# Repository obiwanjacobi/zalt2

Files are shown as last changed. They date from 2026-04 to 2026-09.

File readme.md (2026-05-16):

# Zalt II

The design of the Zalt II computer hinges on a 10-slot (PC) ISA powered backplane I had laying around.

So all modules have an ISA edge connector and although the physical construction is the same as the (PC) ISA bus, the electrical connections are different. So don't try plugging the modules into an old PC.

All card modules (except the Main Board) represent a "smart device".
A smart device has it's own processor to give it additional functionality and perform DMA to offload the CPU.

## Main Board v2.0 (manufactured)

The "motherboard" of the Zalt II computer, containing the 20MHz Z80 CPU, a CPLD for condensed system logic (like MMU/MPU) and an MCU for some (serial) peripherals.

---

## Mass Storage Card

> TBD

- Support IDE hard disks / Compact Flash
- Support File System (FAT16/32)
- Efficient file data transfer (DMA and prefetch)

---

## Video Display Card

> TBD

Currently being researched.

We start of with a simple test on an (SSD1963) [LCD display](./Lcd%20display.md) I have.

- command-based interaction
- lots of graphic services (layers, sprites, transformations, animation, scrolling)
- Additional memory for storing graphic assets
- maybe even a built-in windowing system
- VGA and HDMI using a CPLD to do the heavy lifting
- MCU (STM32?) for 'accelerion', additional memory and DMA

---

## Audio Interface Card

> TBD

Fague ideas on what to do here.

- use MIDI (files) to drive the sound generator(s).
- use a teensy and the audio library (design) capabilities as the processor / sound generator.
- Allow samples to be uploaded and played.
- Prepare for recording audio samples (don't make it impossable), but no plans to use it.

---

## Network Card

> TBD

No idea yet how to do this, but seems like a good idea.

- LAN + WIFI (+BLE?)
- W5500 LAN module (AliExpress)

---

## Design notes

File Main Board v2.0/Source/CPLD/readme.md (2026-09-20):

# CPLD Xilinx XC95288XL

Toolchain: Xilinx ISE WebPack (14.7)

## Memory Decoder

Decode address for:

- ROM Enable
- RAM Enable

## Memory Protection Unit (MPU)

> triggers NMI for violation

- M1 & MEMRQ + RD => MP_EXE (implies MP_RD)
- MEMRQ + RD => MP_RD
- MEMRQ + WR => MP_WR

> MP_RD is a bit redundant. Read access can be assumed as default (and non-destructive). MP_EXE implies read access (M1 is only active at the start of an instruction, which can have additional read cycles). MP_RD could perhaps be renamed/reused for an OS-flag, marking a memory page as locked to applications. See Repurpose MP_RD chat.

Copy on write: mark a memory page as non-writable and keep separate flags in os-memory.
When the NMI triggers, lookup the additional flags and allocate an empty memory page.
Temporary put the two pages in the same memory bank and copy over the content.
Restore the original bank with the new mem-page copy instead of the old one.

Debug Breakpoint: add an address register to the CPLD and when the CPLD detects an execution (M1) at that address, it raises the NMI. The NMI-handler can then enters the debugger using the debug-console. That would mean a loooong interrupt.

Detect `HALT` stalls: when DI and HALT both active, the code will never run. Could count Refresh to detect HALT being active for too long.

> NMI: multiple uses arrise.

- NMI triggers on an actual violation. The program should be killed. Adjust the return address on the stack to handle what to do after that.
- NMI triggers but some function has to be performed and after that execution can continue.

### External DMA

There is a potential issue with external DMA of a smart device.

When a smart device takes over the CPU bus, the smart device has control of the (CPU) memory. The MMU (and MPU) are never turned off.
So the current memory bank the application was using last when making the call to initiate the DMA transfer, is still active.

To fix this we reserve (8) memory banks for the 8 smart devices (also 8 interrupts on the bus) and auto-select the memory bank for that specific smart device.
How does the CPLD know what smart-device is (going to be) active? The bus-req is coupled to the bus interupt index, it is basically a special interrupt.

The smart-device 'index' is used to activate that specific MMU-bank in a reserved/OS-dedicated MMU-map.
This has to be done by the CPLD when the bus is requested.
Select the MMU-map and the device-bank.
That way each device has their 'shared' memory mapped in a location suitable for that device. Other page-indexes can be mapped to a null-page to make them unusable.
The OS MMU-map (Task 0) will reserve the last 8 memory banks for the 8 smart-devices that the CPLD will use.

Access to the MMU-IO registers (to change MMU configuration) is already blocked if not in supervisor mode - so a smart-device can not reconfigure the MMU to gain access to other memory.

## Memory Management Unit  (MMU)

> Physical Memory is the total memory attached to the hardware.
> Logical Memory is the memory addressed by the Z80 CPU (64k).

Normal Operation:

- Latch (6bit) for MMU-Bank
- Latch (6bit) for Task-Bank-maps
- Enable MMU RAM1 + RAM2

IO Operation (RD/WR):

- Decode IO address for writing MMU SRAMs.
- Latch (6bit) for IO-MMU-Bank
- Latch (6bit) for IO-Task-Bank-maps
- Enable MMU RAM1 + RAM2
- WR-Enable MMU RAM1 + RAM2
- Data Direction (RD/WR) for buffers (MMU_RAM_DDIR)
- Data Enable for RAM1 or RAM2

Startup sequence:

At startup/powerup the MMU SRAMs are unitialized (assume garbage).
The CPLD will not enable the SRAMs initially until a specific (IO) write is performed from the Z80 code, indicating initialization of the SRAMs is complete.

When the SRAMs are disabled, the state of the MA13-MA25 lines is determined by weak pull-up/down resistors that map the bootstrap ROM code (4k) into address space $0000 of the Z80.

When the Z80 ROM initialization code is writing values to the MMU SRAMs, they are enabled to receive the write (of course). When the write is done, the state of the SRAM CE line is set to the value of the initialization FlipFlop.

The initialization FlipFlop can be set/reset targeting an output to a specific IO address.

IO Addresses:

- Total of 6 IO addresses requires 3 bits
- Reuse high address bits: `$aaaX_1111_1111_1111`
- A13-A15 select the MMU page address (X=0)
- lower IO address nibbles are `$F` to differentiate from normal IO.

Individual IO ports:

- Startup Latch/MMU Enable (1-bit) `$1FFF`
- Current bank latch (6-bits) `$3FFF`
- Current task latch (6-bits) `$5FFF`

- Change bank latch (6-bits) `$7FFF`
- Change task latch (6-bits) `$9FFF`
- RD/WR memory page in latched bank `$0FFF`-`$EFFF` (uses A13-A15)

## Interrupt Controller

handles Interrupt priority and promotes to INT

In order of prio:

- System IO Interrupts
  - System Timer
  - Programmable Timer(s)
  - PS2 Keyboard
  - Console 1
  - Console 2
- System IO Interrupt Acknowledge

- Expansion Bus Interrupts
  - Interrupt request 1
  - Interrupt request 2
  - Interrupt request 3
  - Interrupt request 4
  - Interrupt request 5
  - Interrupt request 6
- Expansion Bus Interrupt Acknowledge

- Interrupt Enable
  - Scan for RETI instruction after interrupt was issued.

## System IO

- System IO - Data RD/WR and Status RD/Command WR
  - CMD bit
  - Data Direction (245)
  - Data Enabled (CE) (last to activate)
  - Cyclc-count clock (20MHz) to generate CPU wait-states (MCU is slower).

See also Interrupt Controller for System IO interrupts.

## Expansion Bus

- MEM-RD (MEMRQ+RD)
- MEM-WR (MEMRQ+WR)
- IO-IN (IOREQ+RD)
- IO-WR (IOREQ+WR)

- 20MHz clock on dedicated pin.
  - Output 10MHz (bus) clock

---

## TODO

- [ ] detect RETI - to know when interrupt/and RST returns. Assume DI for RSTs also.
  - [ ] Enable `BINTEN` when RETI returns (from an interrupt).
- [ ] detect all RST variants (11xxx111).
- [x] detect INT by CPU int-ack (IORQ+M1)
- [ ] add supervisor FF. Set on RST or INT and cleared on RETI. Track nesting of INT in RST - requires 2x RETI. Can check MMU_MP_OS bit for transition from user to supervisor mode.
- [ ] when coming out of reset the supervisor bit must be on
- [ ] prohibit MMU IO when supervisor is not set.
- [ ] MMU_MP_OS bit (instead of MMU_MP_RD) that is set for os data and code. Fault if MMU_MP_OS is set and supervisor FF is not on during a read or write.
- [ ] Perform no other checks when MMU_MP_OS bit is on. The os mixes code and data in memory pages.

- [x] detect a bus-req interrupt from a smart device.
  - [ ] auto-select the OS-task (0) MMU-map.
  - [ ] select the memory bank for the device requesting the interrupt.

- [ ] BINTACK is not really used. Each BIRQn has its own ACK.
- [x] MMU-enable needs to be active when data is being written or read using IO - even when the FF is off.
- [x] When MMU-enable is false (disabled) the protection bits (MMU_MP_XX) are ignored.
- [x] Writes to the normal MMU latch must be atomic to change all 11 bits at the same time.

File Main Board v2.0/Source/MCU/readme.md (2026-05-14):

# MCU ATmega1284 Source Code

Toolchains: platform IO + VScode

Contains the source code for the System IO processor.

- USART (console) (2x)
- PS/2 Keyboard
- System Tick Timer
- Realtime Clock (RTC) timer
- Programmable Timer(s)
- Persistent Settings (EEPROM)
- SD-Card (SPI)

After a Command has been issued the relevant state-machine is activated.
Any state-machine that was active (but not finished?) is aborted/terminated.

## Status and Commands

| Bit | Status | Function | Description |
| -- | -- | -- | -- |
| 0 | Error | File | There is an error in the last file operation (per file handle) |
| 1 | Error | Console 1 | There was an error. |
| 2 | Output Empty | Console 1 | There is room to send another byte. |
| 3 | Input Full | Console 1 | The receieved byte can be retrieved. |
| 4 | Error | Console 2 | There was an error. |
| 5 | Output Empty | Console 2 | There is room to send another byte. |
| 6 | Input Full | Console 2 | The receieved byte can be retrieved. |
| 7 | Busy | System IO | System IO is doing work. |

| Byte | Command | Function | Description |
| -- | -- | -- | -- |
| 0000_0000 | - | - | - |
| 0000_1000 | FILE-OPEN-READ | File | |
| 0000_1001 | FILE-OPEN-WRITE | File | |
| 0000_1010 | FILE-READ | File | |
| 0000_1011 | FILE-WRITE | File | |
| 0000_1100 | FILE-CLOSE | File | |
| 0000_1101 | FILE-ERROR | File | |
| 0000_0001 | RTC-DATE | Realtime Clock | |
| 0000_0010 | RTC-TIME | Realtime Clock | |
| 0000_0100 | SETTING-READ | Configuration Settings | |
| 0000_0101 | SETTING-WRITE | Configuration Settings | |
| 0000_0110 | SETTING-ERROR | Configuration Settings | |
| 0001_000n | CONSOLE-READ-n | Console | |
| 0001_001n | CONSOLE-WRITE-n | Console | |
| 0001_010n | CONSOLE-ERROR-n | Console | |
| 0001_1000 | KEYBOARD-READ | Keyboard | |
| 0001_1001 | KEYBOARD-WRITE | Keyboard | |
| 0010_00nn | TIMER-SET-n | Programmable Timer-n | |

## Interrupt Levels

Interrupts issued to the CPU:

| Level | Interrupt |
| -- | -- |
| 1 | System Tick Timer |
| 2 | Keyboard |
| 3 | Console 0 |
| 4 | Programmable Timer 0 |
| 5 | Console 1 |
| 6 | Programmable Timer 1 |
| 7 | Protocol Signal* |

> *) If a Procotol Signal is not needed, the interrupt will be assigned to Programmable Timer 2, which currently has no interrupt (polling-based).

Interrupts handled by the MCU (internally):

| Level | Interrupt |
| -- | -- |
| 0 | Hardware Reset |
| 1 | Protocol Data Exchange |
| 2 | Keyboard (pint) |
| 3 | Realtime Clock |
| 4 | System Tick Timer |
| 5 | Programmable Timer 0 |
| 6 | Programmable Timer 1 |
| 7 | SPI / SD-card |
| 8 | Console 0 |
| 9 | Configuration Setting Ready |
| 10 | Console 1 |
| 11 | Programmable Timer 2 |

The interrupt levels for handling internal interrupts in the MCU are fixed by the MCU.

## System Tick Timer

Fixed interval timer tick interrupts for the os to act upon.

- INT: every tick (100ms?)

> Implemented using Timer0 (interrupt) of the MCU.

## Realtime Clock

- CMD: RTC-DATE
  - RD: year (?)
  - RD: month (1-12)
  - RD: day (1-31)

- CMD: RTC-TIME
  - RD: hour (0-23)
  - RD: minute (0-59)
  - RD: second (0-59)

> Implemented using Timer2 (and the external 32.768kHz crystal) of the MCU.

## Configuration Settings

- CMD: SETTING-8
  - WR: address (0-255)
    - RD: value (slow)
    - WR: value (0-255)

- CMD: SETTING-16
  - WR: address (0-255)
    - RD: value LSB (slow)
    - RD: value MSB (slow)
    - WR: value LSB (0-255)
    - WR: value MSB (0-255)

> Implemented using the on-board EEPROM of the MCU.

## Console

- CMD: CONSOLE-n (n:0-1)
  - WR: value (0-255) - output
  - (or) RD: value (0-255) - input, response to INT
- STAT: OutputBufferEmpty, InputBufferFull
- INT: receive input

- CMD: CONSOLE-n-ERROR (n:0-1)
  - RD: error value

> Implemented off the USART0/1 (interrupts) of the MCU.

## PS2 Keyboard

- CMD: KEYBOARD (key-table values)
  - RD: LSB
  - RD: MSB
  - WR: LEDs
- INT: receive input

> Implemented off the Pin Interrupt of the MCU.

## Programmable Timers

- CMD: TIMER-n (n:0-1)
  - WR: interval (0=off)
- INT every tick (different prios)

> Implemented using Timer1 and Timer 3 (interrupts) of the MCU.

## SD-Card Files

- CMD: FILE-OPEN | mode (bit0: 0-read/1=write)
  - WR: file name (one char at a time) + terminating /0.
  - RD: file handle (CPU will wait till MCU is ready) (negative are error values)

- CMD: FILE-READ
  - WR: file-handle
  - INT: file block ready
  - RD: read file handle
  - RD: block length (0=EOF)
  - RD: block data per byte (till block length)

- CMD: FILE-WRITE
  - WR: file handle
  - WR: block length
  - WR: block data per byte (till block length)

- CMD: FILE-CLOSE
  - WR: file handle

- CMD: FILE-ERROR
  - WR: file handle
  - RD: error value

> Implemented using the SPI serial interface (interrupt) of the MCU.

## Data Exchange

The Read and Write data exchange (either data or command/status) have to be handled by the MCU.

The CPLD prepares the Data-Direction signal and the Command/Status bit before activating the Data-Enable signal (active low).

The Data-Enable signal will interrupt the MCU to allow it to read or write the data to/from the CPU data bus.

If the Command/Status bit is active, the MCU will either return the status byte -readilly available in memory- or store the requested command in memory and initialize the corresponding state-machine - clearing out any state that might be left there.

> State-machines that have not finished their state transitions -and required more IO with the CPU- will be aborted. If a state-machine just needs to finish it's background tasks, it is kept alive an gets a slice of the main loop (cooperative).

After the state-machine is initialized, the interrupt service handler is exited.

The main loop will perform the actions advance the state-machine.
The state-machine might signal an interrupt to the CPU (handled by the CPLD) as one of it's steps.

When a Data-Read is received  (another interrupt) the active state-machine is requested to yield a value.
If this value is not available yet (because the CPU is too fast) a pending or error condition has to be generated.

> Currently there is no way to distinguish a read data value from an error value:

- After a read, the corresponding error status or busy flag could be checked. This would double the data transfer.
- The CMD-protocol should be designed such, that there is room in the data-space returned from reads, to indicate errors (pending).

The state-machine can buffer data that will be read by multiple data-read operations.
If there a lot of time between isueing the command and being able to execute the first read, an interrupt should be used to signal completion of an asynchronous operation (the state-machine performed).
We have 7 interrupts in total.
Related signals could share interrupts and the client code on the CPU has to poll to know what operation completed.

Interrupt handling must be a short as possible in order not to frustrate other interrupts (data-exchange iterrupt is highest prio).
Especialy the system-tick timer has highest prio in order to have a stable tick pulse.

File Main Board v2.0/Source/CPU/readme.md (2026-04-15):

# Z80 CPU Source Code

Toolchain: z88dk

## BIOS

Basic Input/Output System - contains hardware abstraction.

- Memory Management Unit - functions for all aspects of the MMU.
- Console IO - routines for serial communication
- Keyboard - low level keyboard scan routine and turning leds on.
- Persistent settings management.
- Realtime Clock functions (Date and Time)
- Storage interaction (TBD)
- programmable timers

## OS

API / services for applications to run on the Zalt2 computer.

- System Init: memory scan/test
- Program loader (applications, modules)
- Process managment (no threads, only process/task=program)
- Memory protection routines (MMU/NMI)
- Interrupt handling / vector management
- Asynchronous communication
- Device Physical/Logical (linux like)
- Streaming API (async) Data/Meta

Program Loader:

- Relocatable code?
- Segmented application format (S-records?) (data section, code section, etc)

## Shell

- command line interface
- built-in commands (monitor like)
  - system utils
    - memory: read/write/fill/test
    - memory manager:control MMU
    - keyboard test
    - inspect settings
  - debug: setup debug console
  - expansion bus
    - address cards (TBD)
- start programs (dos like)

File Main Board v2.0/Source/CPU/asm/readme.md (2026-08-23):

# BIOS

Basic IO System

Contains routines to initialize and access the primary IO devices.

## Conventions

### Registers

`BC`, `DE`, `HL` and `AF` are used as OS-arguments and return values, filled and received by the calling application. Assume (as caller) these registers are not preserved when the call returns (except return values of course).

`BC'`, `DE'`, `HL'` and `AF'` are used by OS and are not preserved.

`IX` and `IY` are not used by the OS at all and are reserved for C-lang application code.

## Page 0

Page zero is the first 4k memory page that will live in all banks (except device specific banks). The page0 contains the necessary data and routines for the OS to operate and interact with (as an application).

- RST entry points: all RST instructions are used for application code to enter the OS.
- IM2 vector table. All the interrupt vectors that are used by the CPLD (BusIO and SystemIO) are located in the first bytes.
- MMU routines: functions to reconfigure and switch memory banks.
- NMI handler: handles memory protection faults.
- Task scheduler: schedules tasks on the system-tick interrupt.
- OS Task: the anchor for switching to and from the OS task (memory bank).

> Note that the IM2 vector table is laid out in the same addresses as the RST and NMI handlers, invalidating some of the vectors.

IM2 vector table at `$0000` (I register = `$00`), even vectors only, sharing addresses with RST and NMI handlers.

| Address | Bytes | Content | Even IM2 Data Bus Values |
|:---:|:-----:|---|:---:|
| $0000–$0003 | 4 | **RST $00** — `JP nnnn` + align | ⛔ $00, $02 |
| $0004–$0007 | 4 | IM2 vector data | ✅ $04, $06 |
| $0008–$000B | 4 | **RST $08** — `JP nnnn` + align | ⛔ $08, $0A |
| $000C–$000F | 4 | IM2 vector data | ✅ $0C, $0E |
| $0010–$0013 | 4 | **RST $10** — `JP nnnn` + align | ⛔ $10, $12 |
| $0014–$0017 | 4 | IM2 vector data | ✅ $14, $16 |
| $0018–$001B | 4 | **RST $18** — `JP nnnn` + align | ⛔ $18, $1A |
| $001C–$001F | 4 | IM2 vector data | ✅ $1C, $1E |
| $0020–$0023 | 4 | **RST $20** — `JP nnnn` + align | ⛔ $20, $22 |
| $0024–$0027 | 4 | IM2 vector data | ✅ $24, $26 |
| $0028–$002B | 4 | **RST $28** — `JP nnnn` + align | ⛔ $28, $2A |
| $002C–$002F | 4 | IM2 vector data | ✅ $2C, $2E |
| $0030–$0033 | 4 | **RST $30** — `JP nnnn` + align | ⛔ $30, $32 |
| $0034–$0037 | 4 | IM2 vector data | ✅ $34, $36 |
| $0038–$003B | 4 | **RST $38** — `JP nnnn` + align | ⛔ $38, $3A |
| $003C–$003F | 4 | IM2 vector data | ✅ $3C, $3E |
| $0040–$004D | 14 | SYSINT 1–7 — IM2 vectors | ✅ $40, $42, $44, $46, $48, $4A, $4C |
| $004E–$005D | 16 | BIRQ0–7 — IM2 vectors | ✅ $4E, $50, $52, $54, $56, $58, $5A, $5C |
| $005E–$0065 | 8 | Free — IM2 vector data | ✅ $5E–$64 (4 vectors) |
| $0066–$0069 | 4 | **NMI** — `JP nnnn` + align | ⛔ $66, $68 |
| $006A–$00FF | 150 | ⚠️ NOT INITIALIZED | ⛔ $6A–$FE (75 vectors) |

The `RST` instructions define the ABI of the OS and device drivers.
A function id follows the RST instruction indicating what to perform.
Any parameters are either passed in registers or put in a dedicated memory block.

| RST | Role | Notes |
| -- | -- | -- |
| $00 | Boot / warm reset | Cannot use it for anything else |
| $08 | OS kernel | Memory, MMU, alloc, tasks, console I/O, everything OS |
| $10 | Storage / file system | High-level functions |
| $18 | Video / graphics | High-level functions |
| $20 | Reserved | audio |
| $28 | Reserved | network / future |
| $30 | Reserved | debug / trap hook or future |
| $38 | Stray trap | All memory is filled with $FF (RST38) |

## OS Initialization

Initialize Memory:

- copy page0 from ROM (currenly executing) to RAM and put that memory page on index 0 (this tranfers execution instantly).
- layout the other OS-pages (code from ROM) in the MMU (64k max)
- initialize OS data-page (RAM) and init stack (OS-specific)

## Memory Management

- MMU operations: map page into address space / change bank configuration
- Allocating a memory page per task.
- Provide Allocators on claimed memory pages (per task).

## Debugging

There are several options for debugging in place.

| Mechanism | How triggered | Use case |
| -- | -- | -- |
| RST $30 | Developer patches a byte | Intentional breakpoint |
| CPLD breakpoint register | M1 at watched address → NMI | Non-invasive / ROM breakpoint |
| HALT → NMI | Any HALT opcode → CPLD → NMI | Crash / unhandled fault trap |

RST $30 is a single byte (0xF7), so it can replace any opcode byte in-place. The handler:

- Saves the full register set into a fixed debug save-area in page 0
- The saved PC (from the stack) points past RST $30 — subtract 1 to get the actual breakpoint address
- Enters a debug monitor loop on the debug console (you already have SYSINT5 / console 1 for this)
- Can inspect/modify the save-area (= registers), read/write any memory
Single-step: temporarily write RST $30 at the next PC, patch the original opcode back, RETI

CPLD Breakpoint register:

- Breakpoints in read-only memory (device ROM, BIOS)
- No need to modify running code
- One NMI handler checks a flag to distinguish "memory protection fault" (existing) from "hardware breakpoint hit"

## Task Switching

For handling interrupts and performing os-functions (RSTs) a light form of task-switching is required. The idea is that upon entering an ISR or RST, the OS switches to it's own private Task memory layout, including it's own stack.

If not already in OS-task:

- stash current (app) SP
- stash current MMU active Task/Bank
- switch to OS-task

For RSTs this requires bringing over the parameters (registers) that acompanied the RST call, which may introduce some additional complexity. If the OS-Task is already active, nothing happens and it is not switched back (to what?) after the ISR or RST is finished.

Just before the INT or RST returns (from page0):

- activate stashed Task/Bank
- reinstate the SP (clear var to indicate no task/bank to switch back to)

### RST - OS function

```z80asm
; os_page0.asm
    di
    jp os_rst_n

; os_rst_n - os_rst.asm
    exx
    ; TODO=> save registers BC' DE', and HL'
    ld bc, <function-table>
    jp os_rst_dispatch

; os_rst_dispatch
    ; get rst-id and adjust caller return address (uses HL' and E')
    ; save (push) all caller's registers (retrieve earlier: BC', DE' and HL')
    ; save caller mmu + SP in TCB
    
    ; switch to full os-task (mmu + SP)
    ; execute os-function (uses BC and E) - requires parameters!
    
    ; load current task mmu and SP
    ; restore (pop) all caller's registers
    ; return to caller
```

### INT - Timer Interrupt

```z80asm
; os_int.asm
    ; save (push) all caller's registers (retrieve earlier: BC, DE and HL)
    ; save caller mmu + SP in TCB

    ; switch to full os-task (mmu + SP)
    ; execute task-scheduler

    ; load current task mmu and SP
    ; restore (pop) all caller's registers
    ; return to caller (ei)
```

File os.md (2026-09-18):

# Zalt OS

Notes on a Zalt os.

## Multi-Tasking

The hardwarde (MMU) can handle multiple tasks. So it stands to reason to have the OS load more than one application that can run (at a time).

The system-timer will be the clock that the task-scheduler will use to activate the different tasks (round robbin) - preemptively. Inside a task, there is no threading (one main 'thread'). A cooperative (Async) mechanism is to be used. You can only starve your own sub-tasks if you take too long.

The OS takes up (at least) one Task (with the highest prio) that is ran outside of the standard scheduling algorithm (assume round robin). At each system-timer tick when the task-scheduler interrupt handler runs, it checks with the OS task to see if work needs to be done (typically hardware signaled), if so it is given priority.

Data per Task:

- Register Data (SP+PC) (Context Switch)*
- Memory Pages Allocated / Current Bank
- Entry Point
- Interrupt handlers? Soft-handlers that are called by the OS (when Task is scheduled).

*) instead of keeping track of all registers for all tasks at a central place (the scheduler), each task could store their own state  (on stack if needed) and we only have to keep track of the current SP for that task. When it is reactivated, we pop all registers off the stack in reverse order and continue.

Task API:

- `Task_Yield` / `Task_Sleep`
- Locking Shared Resources? Lock/Mutex
- Inter Process (Task) Communication? Pipes, Shared Memory (Mapped File)?
- Atomic operations -prevent task switch for a short time.

> We can reserve `HALT` as a yield+idle and wait for next scheduling interrupt. Although it would not be used often? If a task yields and we do not have to perform other (OS) tasks...

### Task Isolation / OS Protection

Task are isolated from each other (as much as possible):

- Have their own MMU Bank Map - no application memory is shared between tasks (except library code).
- Have their MMU Pages marked with Writable and Executable bits.
- The OS preemtively schedules Task execution. It is not possible for a Task to hijack the CPU.

The OS protects its code from illegal access by:

- Marking its MMU Pages with the OS bit. The CPLD monitors execution to manage a supervisor bit and will invalidate the memory access (write/execute) when illegal (MMU page has OS bit on but the supervisor FF is off).
- OS functions (RSTs tracked by the CPLD) can switch to their private stack and MMU banks to pull-in additional data/code.
- The CPLD can even track `IORQ` (+ address) to prevent illegal IO-requests (supervisor bit).
- The CPLD only allows MMU IO-access when supervisor bit is on.

## Program Loader

The program loader reads in a binary file and loads it into the correct memory pages.
The ultimate idea is for a program to be fully relocatable and to have segments defined that will be loaded into the memory pages (MMU). Ideal would be that each segment would also be relocatable so it can be reordered in the CPU address space. But that is probably too complex to manage and write (as a programmer of the application).

It would require an application programmer to output the program in 4k sections.
These sections have to carfully chosen to minimize the need to switch memory pages/sections in and out when calls are made across sections.
The problem of where (what memory page) the called function lives and if it is mapped into CPU address space are a burdon of the os and unclear (at this time) if it can be done. A jump/dispatch table for a program (or each section?) would make it easier to keep track of that.
Note that each Task/Process has its own set of MMU banks and therefor application/task specific bookkeeping is pretty easy.

## Memory Allocation

Memory allocations can be global (heap) - in a memory page shared (and fixed?) by all applications. Limited resource.
Memory Allocation can be local (heap) - in a memory page that is reserved for the application that made the allocation/reservation.

> I would prefer not to have a generic 'malloc' but specific allocators for each specific scenario in an attempt to optimize it as much as possible.

Memory Allocators:

- Arena: Manages a big(ger) block of memory to satify smaller allocations. Typically freed after call tree returns.
- Pooled: Manages a pool of same sized allocation, typically pre-allocated and (optional) pre-initialized.
- Stack: Manages allocations in a FIFO way. Freeing a ptr also free all ptrs that were allocated later.

Normal Stack allocation (local vars) is done through the programming language.

> Can memory be reseverd? And is this then guaranteed?

Dedicated memory pages can be allocated (per task) for smart-device interaction.
These pages are mapped to both the specific device and the application in order for them to share data.

A similar mechanism could be constructed to share data between applications.

## OS Devices

- Physical Devices: Console, Storage, Keyboard?, Mouse?, Video?, Audio?
  - Character Devices: Exchange one byte at a time.
  - Block Devices: Exchange blocks of data at a time.
- Logical Devices: Point to physical devices - can be reassigned at runtime.
  - Null Device: does nothing - data writen is ignored, read is EOF.
  - StreamTap Device: duplicates an out-Stream to an additional device (copy). What to do with read?
  - CharAdapt Device: adapts a block device to be a character device.

Character Devices:

- Console (in/out)
- Keyboard
- Mouse
- Serial

Block Devices:

- Storage (read/write)
- Printer
- Audio
- Video

Each Device Driver implements at least the Stream-Provider API.

| API | Description |
| -- | -- |
|`TryStreamOpen` (async)| Establishes a connection with the stream source (hardware or file). May allocate memory. |
|`TryStreamClose` (async)| Disconnects from stream source and cleanup (free memory). |
|`TryStreamRead` (async)| Reads a block from the underlying device/file. |
|`TryStreamWrite` (async)| Writes a block to the underlying device/file. |

Block devices manage the size of the block and the memeroy required for block data exchange.

### Everything is File (Stream)

> TBD: this is an old concept that may not be the best fit.
It has issues in its (leaky) abstraction and should be async.

Asynchronous Stream-based API interfacing with files and devices.

Content or Data Stream contains the actual data.
The format of the data is dictated by the type of underlying file or device that was opened.

A Meta Stream reports the metadata on the stream and its contents. Examples are:

- file name and attributes
- video mode/resolution

A Stream is opened using an 'uri' that identifies the device (StreamProvider) and the stream source (or target).
The 'uri' is very condensed and simplified to make parsing easy. The way device data is identified (files for instance) is device-dependent. A 8.3 file system (FAT16) will required 8.3 identifiers.

- `con:def` / `con:dbg` default or debug console
- `file:mynotes.txt` targets a file called mynotes.txt
- `file:folder/dir/notes.txt` a file nested in folders.
- `dev:con` information on the device itself.

Basic Stream API.

| API | Description |
| -- | -- |
|`Stream_Construct`| initializes a new stream struct.|
|`Stream_Open`(async)| opens the stream by 'uri'.|
|`Stream_Close` (async)| closes the stream (struct).|
|`Stream_Read` (async)| reads from the stream (char and/or block?)|
|`Stream_Write` (async)| writes to the stream (char and/or block?)|
|`Stream_Seek` (async)| skips through the contents of the stream. Not all devices may support it.|
|`Stream_CanRead`| Indicates if there is something to read from the stream.|
|`Stream_CanWrite`| Indicates if there is room to write to the stream.|

Stream API extensions.

For some devices the basic Stream API is not sufficient.
Additional APIs can be provided by the device (driver) to unlock the extra functionality.
Additional APIs can also aid in reading/writing a specific data format into/from the content or meta streams.

Examples of devices that require extra APIs

- Storage
- Audio
- Video

## Memory Map

- 512kB ROM
- 512kB RAM

- Memory Page is 4kB
- Number of active Pages: 16 (16 x 4kB = 64kB)
- Memory Bank is 64kB (16 Pages) - layout of memory in Z80 address space.
- Total number of addressable Pages: 8192 (32MB)

A Memory Page can be positioned in any 4kB slot in the Z80 address space.

### Z80 CPU Address Space

There are 16 pages of 4kB in CPU memory.

| Idx | Start | End | Size | Description |
| -- | -- | -- | -- | -- |
| f | $F000 | $FFFF | 4kB | |
| e | $E000 | $EFFF | 4kB | |
| d | $D000 | $DFFF | 4kB | |
| c | $C000 | $CFFF | 4kB | |
| b | $B000 | $BFFF | 4kB | |
| a | $A000 | $AFFF | 4kB | |
| 9 | $9000 | $9FFF | 4kB | |
| 8 | $8000 | $8FFF | 4kB | |
| 7 | $7000 | $7FFF | 4kB | |
| 6 | $6000 | $6FFF | 4kB | |
| 5 | $5000 | $5FFF | 4kB | |
| 4 | $4000 | $4FFF | 4kB | |
| 3 | $3000 | $3FFF | 4kB | OS-resident |
| 2 | $2000 | $2FFF | 4kB | OS-resident |
| 1 | $1000 | $1FFF | 4kB | OS-resident |
| 0 | $0000 | $0FFF | 4kB | OS-resident |

The number of 'OS-resident' pages is not yet determined.

## Tasks and Banks

- Number of Tasks: 64 (6-bits)
- Number of Banks (per Task): 32 (5-bits)

Total of 11 bits.

The CPLD manages the MMU Tasks/Banks.

| Task | Bank | Description |
| -- | -- | -- |
| 0 | 0 | Fixed OS Bank that manages os-function dispatching. |
| 0 | 1-23 | OS and device-driver functional memory configurations. |
| 0 | 24-31 | Last 8 Banks are reserved for Smart Device / Extension Bus IO transfer memory configuration. |
| 1-63 | 0-31 | Custom Task (program) memory layout configured by the ProgramLoader. |

MMU-Banks can be used as a stack, where each new memory layout is another bank.
When the code is done with that layout it can be popped and the previous layout is reactivated.

### OS Memory

| Page | Description |
| -- | -- |
| 0-n | OS entry point and book keeping. All Banks have these Pages mapped at the beginning of the CPU address space. |

These first pages contain the data variables required by the OS, OS-function entries (function tables) and interrupt handlers.

| Type | Description |
| -- | -- |
| OS Resident Code | OS code that needs to be accessible at all times (mapped into all Banks) |
| OS Resident Data | OS data that needs to be accessible at all times (mapped into all Banks) |
| OS Code/Data Segments | OS function-specific code segments that are mapped in/out whenever needed, such as device-driver code. Can be mixed with data variables (only OS can do that). |
| OS Blob | Static data used by the OS. Logos, fonts, math tables etc. Located in ROM. |

Some of the OS code may be located in ROM.
Some other code may be loaded from the MCU system SD-Card into RAM.

The OS is 'loaded' and initialized during the boot-sequence when the system starts.

### Application Memory

Typically the following types of segements are in play for a typical application:

| Type | Description |
| -- | -- |
| Application Code | There can be multiple segements of application code |
| Application Data | Initialized, uninitialized variables and the call stack |
| Application Blob | Large binary objects (files, images etc) that are read (or written) in chunks (4-8kB) - windowed data access. |
| Shared Code | Shared library code that can be used by multiple applications (stateless) |
| Dispatch | Jump table where the application jumps to another Bank to access additional code. This segement is always present in all Banks for the application (Task) |

> It would be nice if the OS could perform an application call stack check to prevent or at least detect a stack overrun, where either the stack overwrites application data or visa versa.

Although the memory page size is 4kB, these segments may span multiple pages.
The maximum number of pages that is in CPU address space at one time for an application (incl. dispatch) is dependent on the number of memory pages required by the resident part of the OS.

The application is loaded and initialized by the OS Program Loader that will place the code and data in memory (pages) and configure the Banks to represent the required segements.

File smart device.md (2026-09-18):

# Smart Device

Peripheral devices, like storage, video, audio etc. will be smart devices.
The idea is that communication is done at a higher abstraction level allowing the device to implement more services

Each device implements its own 'DMA' controller to effectively blast bytes over memory (in/out) in one or more memroy-page sized blocks.

## DMA Data Exchange

For an efficient data transfer between an user application and a smart device, DMA will be used.
With a short interruption of the CPU -the application won't notice- large amounts of data can be moved as fast as the RAM chips will go (typically using the CPU clock).

A general solutions could look like:

- CPLD
  - handles the mechanics of interfacing with the CPU
    - device-int + bus-req
    - reading/writing memory (A0-A15 + D0-D7 + CPU-Ctrl)
  - manages/connects local buffer RAM
    - on-device storage where data is staged for interaction with MCU
    - mux between DMA runs and MCU access
    - manages dual access to single RAM chip (DMA has prio)
  - Handshake/interfaces with MCU for reading/writing the buffer RAM
- SRAM
  - (multiple) exchange buffers
  - MCU stages data to be sent to CPU/application memory
  - CPLD dumps data that was read from CPU/application memory
- MCU
  - Implements the device services (FileSystem/Graphics Acceleration/etc)
  - Interfaces with device specific IO (Data Storage/VGA|HDMI/etc)

| Component | Pins | Description |
| -- | -- | -- |
| CPLD | 25 | Buffer/fast SRAM 32k (A:14+D:8+Ctrl:3) |
| | 29 | CPU bus / DMA (A:15+D:8+Ctrl:3+Int:3) |
| | 12 | Handshake interface MCU (D:8+Ctrl:4) |
| | 1 | Additional CPU-IO pin for accessing registers |
| SRAM | 25 | 32kB (A:14+D:8+Ctrl:3) - connected to CPLD |
| MCU | 12 | CPLD handshake (D:8+Ctrl:4) - connected to CPLD |
| | n | Additional pins for interfacing |

This setup allows the MCU to perform work asynchronsouly and stage its data in the buffer RAM (for reading),
or take its time while retrieving data from the buffer RAM when writing.
The buffer RAM is large enough to contain at least 2 times the size of the shared memory.
When a new DMA transfer needs to take place while the MCU is still busy, it can halt the MCU interaction to do an DMA burst.

## Shared Memory

See also [External DMA](./Main%20Board%20v2.0/Source/CPLD/readme.md#external_dma)

An application and a smart device share a 4k memory page (or more than one) for data exchange.
The application sets this up and tells the device (via os-driver) where to find it.

Each device gets its own memory bank that is used to map in the shared memory page(s) at a predetermined location (device specific).

## Protocol

The protocol for data exchange between an application and a smart device is based in memory.
Dependent on the type of smart device, different variations/combinations might be needed, but here is the general idea:

The application sets up a memory area in a 4k memory page for data exchange with a specific device.
Potentially each smart device gets its own memory page.
There are tree types of memory area that may be required for the device:

- Commands: contains one or more command structures that instruct the device what to perform.
- Data: filled by the application (for write) or the device (read) as command input (parameter) or output (result).
- Event: A small area where the device will put the next (or all?) available event. A device-interrupt may signal the presence of one or more events.

After the application has finished preparing the command and possible data, it calls a specific IO port on the device (via os-driver) to let it know what action to perform: 'command' or 'command + data' for example.

The device requests the CPU-bus through raising an interrupt with a bus-request signal.
The CPLD manages handling the interrupt and requesting the CPU bus. It also changes the active MMU configuration to the one specific for that device (based on the interrupt prio).

The device performs the DMA transfer as soon as it receives an acknowledge from the CPLD.
If there is incomming data for the command that is copied also.
After the command(s) (and data) are copied into the device's own memory, it releases the CPU bus.

Now the device will work on performing the command while the CPU is free to do other things.
When the device-operation is ready, it can raise an interrupt to let the application know.
Additionally it could have prepared one or more events to be sent out (retrieved by the application).
The application can retrieve the event(s) with a call to the same operation IO port that started the device-operation, but with a different value: 'events' for example.

The commands themselves can contain information/flags for what type of signaling is requested.

For some devices it may be required to be able to have many commands in one exchange, think of a video device that gets an entire new screen definition to redraw.

In that case the command memory area is managed like an object pool of linked-list items.
Each command has a pointer/offset to the next command, always starting at the root-header.
When changes need to occur, the application can add, insert, replace or remove commands simply by manipulating the pointers/offsets.

Additional data, like strings, referenced by the commands are stored in the same memory page (accessible by the device).

When a command item is disposed it is marked as free and can be reused for further 'allocation'.
Any referenced (dynamic) data is also freed. This is basically a mini-heap.

> TBD: if the heap for dynamic data will also be an object heap with fixed-size items. Otherwise fragmentation could get nasty when commands and their accompanied data are freed.

### Command Structure

```c
// first in command memory (entry point)
struct CommandHeader {
  rel_ptr_t FirstCommand;
  // other fields?
  void* FreeList;   // managed off-site/different page?
};
```

```c
// generic base for every command to allow traversal
struct Command {
  rel_ptr_t NextCommand;
  uint8_t CommandType;      // is 255 command type enough?
  uint8_t Length;           // not strictly needed
};
```

```c
// specialized device command
struct DeviceCommand {
  Command command;          // always start with command base
  // device command specific fields
};
```

### Event Structure

```c
// generic base for events
struct Event {
  uint8_t EventId;
};
```

```c
// specialized device event
struct DeviceEvent {
  Event event;              // always start with event base
  // device event specific fields
};
```

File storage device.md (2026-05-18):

# Storage Smart Device

> This is an idea carried over from Zalt I. It assumes a single MCU that takes care of the DMA and talking to the HDD over IDE.

The idea here is to have the details of the IDE/PATA disk managed by an MCU.
The MCU acts as a DMA controller to the Z80 and can read/write data directly into/from the Z80 memory - after the Z80 has released its bus.

The idea is also that the interaction abstraction is higher that tracks and sectors or even logical blocks.
The idea of (Meta) Streams can be implemented to interface with the disk. The data is moved between Z80 memory and IDE(DMA) using blocks of a certain size. There will be a limit on the max block size because of the size of the internal memory of the MCU (4kB). The location of the command parameter and data buffers have to be on an address that is greater than `0x2200` (ATmega2560) because the DMA of the IDE controller cannot go below that - where it's own internal memory is located. Note that it is also possible to set an upper limit and free a couple of pins on the MCU that would then not be needed for the upper address lines.

The MCU exposes IO locations to the Z80 program to set registers. At what address the data is to be read/written and how large the blocks are etc. Writing to the data or Command Buffer registers, will reset any internal state in the IDE controller.

Register | Description
--|--
Buffer Address | 16-bit memory address for data exchange [1]
Buffer Length | 16-bit memory size [2]
Command Buffer Address | 16-bit memory address for writing command parameters [1][3]
BlockIndex | Writing this triggers a block-move for the current command [4]
Status | Status of the last (or current) operation [5]
Interrupt Vector | IM0 RST instruction or IM2 interrupt vector

---

Notes:

1. The Z80 raw address must be supplied to these registers. The MCU-DMA will take over the Z80 bus and any memory mapping the MMU has in place will activate as if the Z80 itself was reading/writing data.

2. The length of these data blocks are always a multiple of 512 bytes due to the logical block size the IDE uses (128 x 16-bit words). Not strictly needed but addition data will be read from the IDE disk and not used. For writing, the entire 512 bytes for that block has to be read, the changes copied in and the result written back. If the data does not align with the disk's logical blocks, multiple blocks have to be read and written.

3. The command buffer has a fixed (mandatory) length.

4. If we make the BlockIndex 8-bits the maximum file size is related to the `BufferLength`. With a `BufferLength` of 512-multiples the maximum file size would be 256*512=131072 bytes. Sounds like a reasonable start. A 4k buffer would yield 1MB file sizes.

5. Status can be written to set interrupt enable.

> For a (potential) RAM disk, we need extra registers that point to the RAM disk buffer (in Z80 memory) and defines its length.

## Commands

Command | Description
--|--
Read | reads a file
Write | writes a file
Delete | deletes a file
Move | moves a file or folder
Copy | copies a file or folder
Find | finds one or more files (returns meta)
ReadMeta | reads the meta stream
WriteMeta | writes the meta stream (create folders)
DeleteMeta | deletes the meta stream (delete folders)
Abort | aborts any active command

---

The Ide Controller will store all state that is needed across block calls - triggered by writing to the IO `BlockIndex` register of the IDE controller - in the command block. The reserved/filler area is there for that purpose and should not be changed by the Z80 program. Any new command can zero-out the command block and fill the parameters as needed (`Command` is mandatory).

The command parameter block is kept intact during the execution of multiple block transfers for a command - only the IDE controller will update the Stream parameters for bookkeeping. Then by writing the (next) BlockIndex into the IO register, the IDE controller will process the next block.

Multiple file transfers can be interleaved by (re)writing the location of the Command Parameter and data buffers.

## Command Parameters

Due to the high abstraction of the commands there is a need to pass extra command parameters.

```c
enum Commands
{
    None,   // done
    Read,
    Write,
    Delete
    Copy,   // also Move?
    Find,
    Abort   // error
    Meta    // flag
    Direct  // flag
    Sequential  // flag
}

enum Status
{
    Done,
    Error,
    Busy,
}

struct CommandParameters
{
    Commands    Command;
    Status      Status;
    uint16_t    ContentLength;
    uint16_t    ContentOffset;
    const char* Location;       // 16 bits

    // block bookkeeping
    uint16_t    StreamLength;
    uint16_t    StreamOffset;
    uint8_t     Filler[];   // reserved space
}
```

The `None` command is written by the IDE controller on the last block when a data exchange is finished. When a Z80 program writes a stream to the IDE controller it does not have to indicate the end. The IDE controller uses the `ContentLength` in combination with `StreamLength` and `StreamOffset` to calculate this.

The `Abort` command can be written by the Z80 program to abort an unfinished exchange -or it is written by the IDE controller when an error occurs. It is also an error when the `BlockIndex` written to the IO register of the IDE controller is outside the range of the `ContentLength` and `ContentOffset` specified in the command parameter block.

The `Meta` flag can be combined with the following commands:

- Read
- Write
- Delete

The `Direct` flag on any command indicates that the operation is to use the data from the Z80 memory directly and not copy it to the IDE controller's internal memory first.

The `Sequential` flag indicates that (part of) the file is read in sequence (forward, not random access) *AND* that the command will not be interleaved with other commands. This allows the IDE controller to prefetch data for the next block while the Z80 program is processing the current block. Not all commands will take advantage of this flag but it is never an error specifying it.

The `Status` field is a copy of the Status register at the very last moment the IDE controller has access to the Z80 memory bus. The status register can be queried at any time to get an up to date value. For instance a write command copies the data over to the IDE controller's internal memory and then releases the bus. At that time the status is `Busy` as an indication of the data being written to disk. It also indicates that it is ok for the Z80 program to fill up the (write) buffer with another block of data.

The `Location` field of the file (or folder) to fetch is a pointer to a null-terminated string. The location of this string must be accessible to the IDE controller when it accesses the Z80 memory directly (DMA). Should not be a problem.

### File Path (Location)

The file path parameters identifies the location of a file on the file system. Files and Folders can be explored by opening Meta streams on the root or any known folder location.

This parameter is mandatory for all commands.

Location | Description
--|--
`/` | root folder
`/MyFolder/` | 1st level folder [1]
`/MyFile.dat` | root file
`/**/*.txt` | Find query (find all text files in any folder)

---

1. Note that folder paths always end with a path separator (`/`).

### Block Number

The block numbers (Id) of the first block in the buffer. When a command starts this is always 0. When a continuation is submitted, this number is incremented by the Z80 program.

### Content Length

The content length parameter allows a limit on the amount of data to return from a (data) stream. Usually not very useful for Meta streams.

This parameter can be specified per byte (no alignment).
If not specified (zero) the entire file is retrieved.

### Content Offset

The content offset parameter allows reading or writing partial files. Usually not very useful for Meta streams.

This parameter can be specified per byte (no alignment).
If not specified (zero) data transfers starts at the beginning of the file.

### Stream Length

Running value for length of the stream. It is always smaller or equal to the `BufferLength`.

### Stream Offset

Running value for the offset for the current block in the buffer. The next block will start at the `Stream Offset` + `Stream Length`, taking the `ContentOffset` as a start point.

For Meta Streams it may be necessary to relate back to the disk data. For instance doing a list (dir) on a folder may return more files than the buffer has room for. This field will point to the next item in the original list (from FS).

### Stream Structure

Exchange of data between the Z80 program and the IDE (or any other smart device) is done by pumping over blocks of data using the shared (Z80) memory buffer.

For data files the buffer is just a part of the file content. The interpretation of that content is up to the Z80 program.

For Meta Streams there is a fixed structure to the content of the stream. If a meta stream is larger than the buffer length, it will always contain a number of complete structures - it never ends (or begins) with a partial structure.

The bad news is that the structure is a variable size - to save space.

```c
enum MetaFlags
{
    None = 0x00,        // end of the line
    File = 0x01,
    Folder = 0x02,

    Protected = 0x04,  // read-only
    Hidden = 0x08,

    // TBD
    Meta,   // indicates a meta stream
    Volume, // volume/partition ??
    Flush,  // make sure everything is persisted
}

struct MetaRecord
{
    MetaFlags   Flags;  // uint8_t
    uint32_t    ContentLength; // max length dependent on FS
    uint16_t    Date;
    uint16_t    Time;
    char        Location[1+];   // variable length
}
```

Field | Offset | Description
--|--|--
Flags | 0 | Flags and attributes of the record
ContentLength | 1 | Length in bytes of a file (0 for Folder)
Date | 5 | Date (year, month and day) of last modified
Time | 7 | Time (hour, minute, second) of last modified
Location | 19 | Zero terminated string of path (min length is 1)
\<end> | > 20 | Variable length structure

---

The end of the stream is indicated by an additional `null` in memory (next record's Flags = None).

> No provision for Volumes, Partitions, (un)mounting etc. yet.

> Mount drives by name (not drive letter) service as root.

Location names are subject to underlying file system (FAT32/exFAT). Assume 8.3 file names.

## Process Interaction

### Read

- The Z80 program initializes the command block for a read operation.
- The Z80 program sets the MCU-DMA registers using OUT instruction at the appropriate addresses.
- The Z80 program triggers the MCU-DMA to perform the read command (writing to the BlockIndex register).
- The MCU-DMA implements the file system and maps the requested file path to an entry in the index on disk.
- The MCU-DMA activates the read-command to the IDE disk and retrieves the first logical block.
- When retrieving the data from disk is finished, the MCU-DMA activates the Z80 /BUSRQ to gain access to the memory.
- After /BUSACK is activated the MCU-DMA disables the IDE-interface and enables the external memory interface.
- It then copies the data from the MCU's internal memory to a memory location that corresponds to the target address in the Z80 memory. It also updates the command block.
- When done it releases the Z80 /BUSRQ and advanced its internal state-machine to setup the next read cycle from the ide.
- The MCU-DMA will generate an /INT to the Z80.
- In the mean time the MCU-DMA will commence to read the next data block into its internal memory (pre-fetch).
- The Z80 program will respond to the interrupt and signal the MCU-DMA that the next block can be read (by writing to the BlockIndex register).
- The MCU-DMA will continue to move data from its internal memory to the Z80's memory and preloading the next data block.

### Write

- The Z80 program initializes the command block for a write operation.
- The Z80 program sets the MCU-DMA registers using OUT instruction at the appropriate addresses.
- The Z80 program writes its data to the (shared) memory it has set up for the MCU-DMA to access.
- The Z80 program triggers the MCU-DMA to perform the write command (writing to the BlockIndex register).
- Then the MCU-DMA activates the Z80 /BUSRQ to gain access to the memory.
- After /BUSACK is activated the MCU-DMA (disables the IDE-interface and) enables the external memory interface.
- It then copies the data from  a memory location that corresponds to the target address in the Z80 memory to the MCU's internal memory.
- When done it releases the Z80 /BUSRQ.
- The MCU-DMA implements the file system and maps the requested file path to an entry in the index on disk.
- The MCU-DMA activates the write-command to the IDE disk and pushes the first logical block.
- The Z80 program can fill its data buffer in memory in the meantime, to prepare for the next write cycle.
- The MCU-DMA will generate an /INT to the Z80 when it has finished writing to the IDE disk.
- The Z80 program will respond to the interrupt and signal the MCU-DMA that the next block can be written (by writing to a register).
- The MCU-DMA will continue to move data from the Z80's memory to the MCU's internal memory while the Z80 can continue to prepare the data to write in its memory buffer while the MCU is busy writing to disk.

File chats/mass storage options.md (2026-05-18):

User: I am investigating what mass-storage to attach to my 20HMz z80 homebrew computer.
The main board that is currently being made works on a (custom) bus. The idea is to have smart-devices on the bus that each perform a task, like mass-storage, video display, network etc.
The protocol to communicate with a smart-device (SD) is not final, but the current idea is to have the SD do DMA to exchange large amounts of data.
The protocol is also on a higher abstraction level than sectors or blocks (for mass storage). The file system (FAT16/32) will be imlemented in the SD.
My initial idea was to try to interface with an old IDE HDD, but perhaps there are easier options to persue. Any thoughts?

GitHub Copilot: I’m checking the existing project notes around storage and the smart-device bus so the recommendation is grounded in your current architecture rather than generic advice.

Read [](file:///c%3A/My/MyProjects/zalt2/Main%20Board%20v2.0/readme.md)

Read [](file:///c%3A/My/MyProjects/zalt2/readme.md)

Read [](file:///c%3A/My/MyProjects/zalt2/chats/SPI%20SD%20Card.md)

For your architecture, an old IDE HDD is probably the wrong first target. Since the smart-device owns the filesystem and the Z80 only sees higher-level file operations, the best storage medium is the one that is easiest for the smart-device to drive reliably, not the one that is most “native” to the Z80 era.

My recommendation is: start with an SD card, likely over SPI for rev 1. If you later want more throughput, move to a controller that can do 4-bit SD mode or use a faster MCU. SD gives you cheap media, low power, no 12 V rail, simple mechanics, easy replacement, and straightforward MCU support. For the abstraction you described, it is a very good fit.

Old IDE HDDs are attractive emotionally, but they cost you a lot:
- awkward power requirements
- bulk and noise
- aging, failure-prone media
- more annoying electrical/timing behavior than modern removable flash
- little benefit if your smart-device hides sectors and ATA details anyway

If you want something “IDE-like” without the pain of spinning disks, CompactFlash is the interesting middle ground. CF in True IDE mode is much friendlier than a real HDD, still has the retro flavor, and is electrically simpler to integrate than a legacy drive. If your goal is experimentation with a parallel storage interface, CF is a better path than an actual HDD.

I’d rank the options like this:

1. SD card over SPI
Best first implementation. Lowest risk, fastest path to a working mass-storage device.

2. CompactFlash in True IDE mode
Good if you specifically want a parallel, retro-style storage module and removable media.

3. eMMC
Technically good for a compact fixed “system disk,” but usually worse for hobbyist bring-up because of package and routing pain.

4. Old IDE HDD
Only worth it as a later novelty or engineering challenge.

5. USB flash drive
Avoid for now. USB host support adds complexity for very little payoff in your design.

For the protocol, I’d keep a strict split between control plane and data plane:
- control: open, create, close, read, write, seek, stat, enumerate
- data: DMA transfers of file payload only

That keeps the Z80 side clean. The smart-device should own:
- FAT16/32 parsing
- directory traversal
- filename handling
- current file position
- buffering and prefetch
- write-back caching

On the Z80 side, expose opaque handles rather than paths after open. Something like:
- `open(path, mode) -> handle`
- `read(handle, addr, len) -> actual_len`
- `write(handle, addr, len) -> actual_len`
- `seek(handle, pos)`
- `close(handle)`
- `find_first/find_next`
- `mkdir`, `delete`, `rename` later if needed

A few design choices will make this much smoother:
- Use DMA in 256 B or 512 B chunks, not tiny transfers.
- Let the device prefetch sequential reads.
- Keep writes buffered and commit on `close` or `flush`.
- Return simple status/error codes; don’t mirror FAT internals to the Z80.
- Support sequential access first. Random seek can come later.
- Consider 8.3 filenames first, then add long filenames only if you really need them.

If you want a practical first target, I’d build a storage smart-device around:
- an SD card
- an MCU with solid SPI and enough RAM for a few sector buffers
- a handle-based file API
- DMA bursts into Z80 RAM

That gets you to a usable filesystem quickly. If later you still want the retro satisfaction of “IDE,” make a second mass-storage card based on CF rather than a spinning HDD.

Natural next steps:
1. I can help sketch a minimal command set for the Z80-to-storage-device protocol.
2. I can help compare MCU choices for the storage smart-device.
3. I can help define a DMA-friendly file API that fits your bus cleanly.

User: Is there a CF size I should be aware of? Like the new modern ones with many GBs - do they introduce extra complexity?

GitHub Copilot: Yes. The main capacity-related complexity is not the CF interface itself, but the addressing mode and filesystem choices that come with larger cards.

For CF in True IDE mode, the practical breakpoints are:

1. Up to 2 GB: easiest if you want FAT16.
2. Above 2 GB up to 128 GiB: still straightforward if you use FAT32 and 28-bit LBA.
3. Above 128 GiB: you need 48-bit LBA support, which adds command and register-handling complexity.

So if your storage device implements FAT16/32 and talks ATA/IDE-style commands to the CF card, “modern big” CF cards do not automatically become hard, but once you cross 128 GiB you are in a different class of protocol support. For a first implementation, I would avoid that entirely.

There is also a filesystem breakpoint:
- Small cards let you stay on FAT16 if you want the simplest code.
- Larger cards push you toward FAT32.
- Very large cards may come preformatted as exFAT, but that is not a hardware problem; you can usually reformat them to FAT32 if the size is reasonable for your use.

For your project, I would deliberately choose something modest, like 512 MB to 8 GB, or at most 16 GB or 32 GB. That gives you plenty of space, keeps you away from 48-bit LBA, and avoids any temptation to support exFAT. If you want the absolute simplest path, 1 GB to 2 GB is a very comfortable range.

The bigger practical issue with CF today is often not size but card quality and compatibility. New random CF cards can be inconsistent. Industrial CF cards or older genuine-brand cards tend to behave more predictably in True IDE mode.

Short version: large CF cards do add some complexity, but mostly only at the filesystem and LBA48 boundary. If you stay at 32 GB or below, and ideally much smaller, you avoid most of it.

User: can you address a CF > 2GB as one < 2GB (FAT16) - just wasting the rest?

GitHub Copilot: Yes, in principle. A CF card larger than 2 GB can usually be used as if it were a smaller FAT16 volume by creating a small partition at the front and ignoring the rest.

A few distinctions matter:

- Hardware addressing: the CF card still reports its real full capacity. Your smart-device can choose to use only the first N sectors.
- Filesystem: you format only that first region as FAT16.
- Unused space: the remainder just stays unpartitioned or unused.

So from your firmware’s point of view, you can absolutely say: “I only expose the first 1 GB or 2 GB of this card” and treat it like a small disk.

The simplest ways to do it are:

1. Create a partition smaller than 2 GB at LBA 0 and format that FAT16.
2. Ignore partitioning entirely and build a FAT16 volume directly on the first part of the medium, if your firmware is happy treating the device as “superfloppy” style media.

The catch is compatibility, not theory:

- Some PC formatting tools may prefer FAT32 on larger cards.
- Some OSes may not like odd partitioning choices on large removable media.
- If the card comes preformatted, you’ll likely want to repartition/reformat it yourself.
- If your firmware reads MBR partitions, it must honor the partition size and not the raw device size.
- If your firmware skips MBR and mounts a raw FAT volume, then you just ignore everything after the FAT16 region.

For your project, this is a valid simplification strategy. In fact, it is a good one if you want:
- FAT16 only
- fixed small-volume assumptions
- simpler testing and recovery

I would still prefer getting an actually small CF card if convenient, because it reduces ambiguity during bring-up. But if larger cards are easier to source, using only the first 512 MB to 2 GB is perfectly reasonable.

One practical warning: FAT16 “2 GB” is not a universal hard line in the real world. The exact usable limit depends on sector size and cluster-count rules. If you want the least friction, target something comfortably below the edge, like 1 GB or 1.9 GB, rather than trying to hit the absolute maximum exactly.

If you want, I can outline the simplest on-device strategy for this:
1. raw FAT16 volume with no partition table
2. MBR with one small FAT16 partition
3. smart-device firmware that clamps visible capacity regardless of actual CF size

User: got it.
what MCU would be suitable?
My idea for DMA is to use a complete 4k memory page that contains both control commands (ring) buffer as well as the data (ring) buffer.
Would be ideal if the MCU had some sort of external memory interface. 

GitHub Copilot: For what you described, the first thing to pin down is this: do you want the MCU to be a bus master that actively drives the Z80 memory bus during DMA, or do you want a permanently shared 4 kB page that both sides can access through some arbitration logic?

Those lead to different MCU requirements.

If you want true DMA into Z80 RAM, an “external memory interface” on the MCU is helpful, but not in the way people usually mean. Most MCU external bus interfaces are for the MCU to access external SRAM, NOR flash, LCDs, or FPGA registers as a master. They do not automatically make the MCU a nice bus-slave on someone else’s system bus. So if your DMA plan is “MCU grabs the bus and writes into a 4 kB page of system RAM,” then what matters is:
- fast GPIO or a parallel bus peripheral
- predictable timing
- enough DMA capability internally to move data from SDIO/SPI into staging RAM
- enough RAM for buffering
- acceptable glue logic complexity

If instead you create a dedicated 4 kB dual-ported or arbitrated shared page, then the MCU can talk to that page as external memory and the Z80 can map it through the MMU. That is much cleaner architecturally. In that model, the MCU is not pretending to be a RAM chip on the Z80 bus; both sides just exchange descriptors and payloads through shared memory.

For MCU families, I would shortlist these:

1. STM32F4/F7 with FSMC/FMC
Best overall fit. These parts have a well-known async external memory controller, decent DMA, lots of RAM options, SDIO/SDMMC on many variants, and a big hobby ecosystem. An STM32F407 or STM32F767 is a strong candidate.

2. ATSAM / SAME70 / SAMV71 with EBI/SMC
Very capable for external bus work and storage tasks. Good if you want a more industrial feel and strong peripheral set. Slightly less hobby-friendly than STM32, but technically solid.

3. NXP LPC177x/178x or similar parts with EMC
Usable, though I would usually pick STM32 first unless you already know the NXP toolchain well.

4. Teensy-class i.MX RT boards
Very fast, but often less convenient for clean external parallel bus interfacing than an STM32 with FMC. Great compute, less obviously the simplest fit for this exact job.

The part I would not choose for this specific card is an AVR-class MCU like the ATmega1284P if you want serious DMA-style mass storage. It can do the logic, but once you add FAT, buffering, ring management, and high-speed bus transfers, you will start fighting RAM size, throughput, and software complexity.

My concrete recommendation would be:
- STM32F407 if you want a pragmatic first implementation
- STM32F767 or H7-class only if you know you need more headroom
- use SD card first, not CF first, unless retro-parallel storage is the actual goal

About your 4 kB page idea: that is a good idea. In fact, it is better than trying to expose lots of registers. I would structure it as:
- a command ring
- a completion ring
- one or two large data regions
- ownership flags / producer-consumer indices
- a very small doorbell/interrupt mechanism outside the page

That gives you a transport layer that can serve storage, network, and video devices with the same model.

A few practical observations:
- 4 kB is large enough to be useful and small enough to reason about.
- Make the rings descriptor-based, not byte-stream-only.
- Keep command descriptors fixed-size.
- Put actual file data in one or two larger contiguous buffers.
- Use separate producer/consumer pointers for Z80 and MCU.
- Avoid per-byte handshakes entirely.

One important caveat: if the shared page lives in the normal Z80 RAM space and the MCU writes it during DMA, cache coherency is not an issue for a Z80, but page ownership is. You need a very crisp rule about when the Z80 may touch a buffer and when the MCU may touch it. A double-buffered region is usually easier than a fully general byte-ring for payload data.

If you want the simplest hardware architecture, I would do this:
1. MCU with FMC/FSMC and SDIO/SDMMC, preferably STM32F4/F7.
2. Shared 4 kB page implemented as external SRAM or FPGA/CPLD-backed memory window.
3. Descriptor rings in the first part of the page, data buffers in the rest.
4. MCU reads SD card into its own RAM first, then copies or DMA-pushes into the shared page.
5. Z80 consumes from the shared page without touching storage protocol details.

If you want the simplest firmware architecture, I would not try to make the MCU directly emulate a memory device on the Z80 bus. I would use the shared-page design instead.

If you want, I can do one of these next:
1. sketch a concrete 4 kB page layout with ring headers and descriptors
2. compare a few specific STM32 parts for this role
3. outline the bus-arbitration options for “true DMA into Z80 RAM” versus “shared-page transport”

User: Each smart device (SD) has it's own dma capability (instead of a central DMA controller on the motherboard like with a PC). The SD can request the (CPU) bus and access the memory without contention. Clearly this time should be as short as possible. 

GitHub Copilot: In that model, I would treat the smart device as two blocks, not one:

- an MCU that handles the slow, stateful work: filesystem, SD/CF protocol, buffering, command parsing
- a small CPLD/FPGA or dedicated bus-state machine that handles the fast, timing-critical bus master cycle generation

That split fits your bus-master-per-device architecture much better than trying to make the MCU do everything directly.

A plain MCU external memory interface is usually not the deciding feature here. It helps the MCU talk to parallel memory, but bus-mastering a Z80 system cleanly means you also need:
- bus request/grant handling
- address/data/control signal sequencing
- wait-state handling if needed
- clean tri-state behavior
- short, deterministic burst transfers

Those are exactly the parts a CPLD/FPGA is good at. The MCU is good at everything else.

So the ideal smart-device architecture is:

1. MCU fills a local buffer from storage or prepares data to write.
2. When enough data is ready, the device requests the Z80 bus.
3. A CPLD/FPGA takes over the bus and performs a short burst into RAM.
4. Bus is released immediately.
5. MCU continues background work while the CPU runs again.

That keeps bus-hold time short, which is the right optimization target.

For MCU choice under that architecture, I would prioritize:
- enough SRAM for prefetch/write-back buffers
- good SDIO/SDMMC or at least fast SPI
- decent internal DMA
- enough performance to handle FAT and command queues comfortably
- easy toolchain and board availability

I would look at these classes:

1. STM32F4
Very good baseline. Enough RAM/performance for filesystem work, strong peripheral set, easy to source used boards/modules.

2. STM32F7 or H7
Good if you want more buffering, more throughput, or multiple services later. Probably more than you need for a first storage device.

3. SAME70 / SAMV71
Technically strong, especially for a more serious bus-oriented design, but I’d still usually pick STM32 first unless you already prefer Microchip’s ARM parts.

For a first device, an STM32F407-class MCU plus a small CPLD is a very sensible combination.

What I would not optimize for first is “MCU with external memory bus.” If the CPLD is generating the actual Z80 bus cycles, the MCU no longer needs to directly present itself as a bus master on the motherboard. It only needs a fast local link to the CPLD and enough RAM to stage bursts.

The key architectural rule should be: never hold the CPU bus while talking to the storage medium.

That means:
- read from SD/CF into local RAM first
- then request the bus and blast a burst into system RAM
- for writes, pull a burst from RAM quickly, release the bus, then write to media afterward

So your DMA becomes “burst memory exchange,” not “live storage transaction.” That is the right design.

If you want to minimize bus occupancy further, your 4 kB page idea is strong, but I would use it as a mailbox plus staging window, not as a constantly shared live structure. For example:
- one small command ring
- one completion ring
- one or two data buffers
- ownership bits per buffer

Then the MCU can prefetch a 512-byte sector or file chunk locally, request the bus once, copy it into the 4 kB page, release the bus, and let the Z80 consume it later without another bus arbitration event.

So the practical recommendation becomes:

- MCU: STM32F407 or similar
- Bus interface: small CPLD/FPGA
- Media: SD first, CF second if you want the retro interface
- DMA strategy: prebuffer locally, burst over the bus, release immediately

If you want, I can next sketch:
1. a concrete smart-device hardware partition between MCU and CPLD
2. a bus-master DMA burst protocol for your 4 kB page
3. a rough timing budget for how long a 256 B, 512 B, or 4 kB transfer would hold the Z80 bus at 20 MHz

User: Splitting into a CPLD-DMA, a (transfer) RAM and a MCU will make the hardware more complicated. You need to mux the RAM between the CPLD and the MCU. Also using a ring buffer in the 4k shared page - it is not as straight-forward to implement in a CPLD? it is not a mere 'increment address' until you're done - scenario.

GitHub Copilot: Yes. That is the real cost of the “MCU + CPLD + transfer RAM” split: the timing gets cleaner, but the local card architecture gets more complicated.

And you are also right about the ring buffer point: a general-purpose ring is not something I would want the CPLD to “own” in the sense of parsing variable-length commands, tracking wraparound, dealing with partial records, and arbitrating with the MCU. That pushes too much control logic into the programmable logic.

The cleaner way to think about it is this: the ring lives at the protocol level, but the CPLD should only execute very small, fixed transfer primitives. The MCU owns the ring semantics.

So instead of:

- CPLD understands the shared 4 kB page structure
- CPLD walks command/data rings
- CPLD decides where the next payload begins

I would do:

- MCU parses the command ring in shared memory
- MCU decides: source address, destination address, length, direction
- MCU then arms the CPLD with a very small descriptor like “copy 512 bytes between local buffer X and system address Y”
- CPLD performs only the burst
- MCU updates the shared-page ring metadata afterward

That keeps the CPLD to “increment address until done,” which is exactly the level it should operate at. The ring buffer remains a software structure, not a hardware state machine.

So your objection is valid, but it argues for narrowing the CPLD’s role, not necessarily removing it.

If you want to reduce hardware even further, there are really three viable architectures:

1. MCU only, no local transfer RAM, no CPLD
Possible, but only if you are willing to accept relatively slow and timing-sensitive DMA bus service. At 20 MHz Z80, I would not choose this unless the DMA bursts are tiny and infrequent.

2. MCU + CPLD, but no shared local RAM between them
This is often the sweet spot. The MCU keeps its own SRAM buffers internally. The CPLD is just a bus master engine. The link between MCU and CPLD is a few control/status registers plus maybe an 8- or 16-bit local data path/FIFO. No external transfer RAM to mux.

3. MCU + dual-port RAM, optionally no CPLD or minimal CPLD
Architecturally elegant, but dual-port RAM parts are less common and may be overkill unless you really want a true shared-memory card model.

Given your concern, I would avoid “CPLD + external transfer RAM + MCU” unless you have a very clear reason for it. It adds a lot of board complexity for something the MCU’s internal RAM can often handle perfectly well.

A better compromise is:

- MCU stores prefetched file data in its own RAM
- MCU manages the 4 kB shared-page protocol logically
- CPLD only performs bus-request, bus-master burst, bus-release
- CPLD gets a simple transfer descriptor from the MCU
- no CPLD awareness of ring wrap, handles, file state, or variable-length protocol records

That also fixes your ring-buffer concern. The shared 4 kB page can still use rings, but only the MCU and Z80 software need to understand them. The DMA hardware only copies byte ranges.

If you want to simplify even more, I would question whether you need a true ring for the data area at all. For a storage device, a ping-pong or mailbox scheme is often much easier:

- command area
- response area
- buffer A
- buffer B

Ownership bits:
- Z80 owns A, MCU fills B
- then swap

That is much easier in both firmware and hardware than a general ring, and for sequential file I/O it is usually enough. Rings are attractive, but they solve a more general problem than mass-storage really needs.

So my practical advice is:

- keep the 4 kB shared page idea
- do not implement the ring logic in the CPLD
- strongly consider replacing the data ring with fixed-size double buffers
- let the MCU own all protocol semantics
- let the CPLD only execute fixed DMA bursts

That gets you most of the benefit without turning the card into a three-way arbitration problem.

If you want, I can sketch a concrete 4 kB layout based on double-buffered file transfers rather than a full ring.

User: You say the CPLD performs a 'bus master burst' - what is that exactly? Is it the data transfer? If so - how does it reach the MCUs internal RAM?

GitHub Copilot: Yes, in that sentence “bus master burst” meant the actual memory transfer on the Z80 side: the device takes the bus, presents addresses and control signals, and writes or reads a run of bytes to or from system RAM.

Your question is the right one: a CPLD cannot magically read the MCU’s internal RAM. Internal MCU SRAM is only visible inside the MCU unless the MCU explicitly exports the data somehow. So if the CPLD is the block performing the Z80 bus cycles, it needs a separate path to get the bytes.

That path can only be one of these:

1. MCU directly feeds the CPLD during the burst
The MCU writes bytes or words into a small register/FIFO interface in the CPLD, and the CPLD consumes them while driving the Z80 bus.
This works, but only if the MCU can keep up, or if the burst is short enough.

2. External transfer RAM or FIFO shared between MCU and CPLD
The MCU fills local RAM first. Then the CPLD reads that RAM and performs the Z80-side burst.
This is the cleanest separation, but it adds the hardware complexity you objected to.

3. MCU performs the bus transfer itself
In this case the MCU, not the CPLD, is what actually sources or sinks the data while bus mastering.
Then there is no “how does the CPLD reach MCU RAM?” problem, because it doesn’t. The MCU already has the data.
A CPLD could still help with bus arbitration or signal shaping, but it is no longer the transfer engine.

So yes: my earlier phrasing hid an important detail. If the payload is in MCU internal RAM, then either:
- the MCU must participate actively during the transfer, or
- the data must first be copied into some memory/FIFO the CPLD can see.

That is exactly why this partition is tricky.

For your design, the realistic options are:

1. MCU-only DMA engine
The MCU requests the bus and directly performs the reads/writes to Z80 memory.
Simplest hardware.
Harder timing problem.

2. MCU + small CPLD, but CPLD only handles arbitration/control
The MCU still provides address/data timing, or at least feeds the data path.
Middle ground, but not always worth it.

3. MCU + CPLD + shared buffer memory
Most robust hardware behavior.
Most complicated board design.

If your main concern is avoiding extra muxed RAM and keeping the board simpler, then the most honest conclusion is: the MCU probably has to be the actual DMA data mover. In that case, an MCU with:
- plenty of GPIO
- predictable timing
- decent SRAM
- maybe an external memory/peripheral bus for convenience
becomes more important than a CPLD-centric scheme.

So the corrected summary is:

- “bus master burst” = the actual sequence of memory read/write cycles on the Z80 bus
- if a CPLD performs that burst, it must get the bytes from somewhere it can see
- MCU internal RAM is not directly visible to the CPLD
- therefore you need either a feeder interface, external buffer memory, or the MCU doing the transfer itself

Given your stated preference for less hardware complexity, I would lean toward this architectural rule:
- MCU owns buffering and protocol
- MCU is the real DMA mover
- optional CPLD only assists with bus request/grant and safe bus isolation, not bulk data storage

If you want, I can next compare these two concrete approaches:
1. MCU directly writing Z80 RAM during bus hold
2. External dual-ported or shared transfer RAM page with no active burst copying at all

User: I actually like the CPLD idea and I understand that a (dual ported) RAM would be ideal, but I am trying not to over-engineer it. I am currently leaning towards a CPLD that performs the bus operations and DMA and has a dedicated/special/specific interface with the MCU. I mean would only take like 12 pins (max?) for a 2-way 8-bit data handshake...?

GitHub Copilot: Yes, that is a reasonable middle ground.

What you are describing is essentially:

- MCU handles storage, FAT, buffering, and protocol
- CPLD handles bus request/grant and Z80 memory read/write cycles
- MCU and CPLD talk over a small private byte-stream interface

That is not over-engineering. It is a fairly clean partition, and it avoids the worst part of the “full shared transfer RAM” design.

Your “about 12 pins” intuition is in the right range if the interface is narrow and handshake-based. For example:

- 8 data pins
- 1 direction bit, or separate read/write strobes
- 1 data valid / write strobe
- 1 ready / ack
- 1 optional packet-start / command-data select

That is already enough for a robust two-way link.

The main question is not pin count, but whether the MCU-to-CPLD link can feed data fast enough to justify the CPLD doing the Z80-side burst. There are two basic models.

1. Streaming interface
The MCU pushes or pulls bytes while the CPLD is in the middle of a DMA transfer.

This is the simplest interface electrically, but it means the CPLD is only as fast as the MCU can feed it. In that case the CPLD is mostly helping with timing cleanliness on the Z80 side, not making the transfer fundamentally faster.

2. Commanded burst with small local elasticity
The MCU first loads a small FIFO or holding buffer in the CPLD, then tells it:
- direction
- Z80 address
- length
- go

The CPLD performs as much of the burst as it can from that local buffer, while handshaking for refill or drain as needed.

This is usually the sweet spot. You do not need a full 4 kB dual-port RAM. Even a tiny elastic buffer, say 16 to 64 bytes, can decouple the MCU and the Z80 bus enough to simplify timing a lot.

So yes, a “special-purpose interface” is a good idea. I would make it packetized rather than a raw bidirectional bus.

A practical split would be:

Control path from MCU to CPLD:
- target Z80 address
- transfer length
- direction
- start
- maybe flags like auto-increment and interrupt-on-complete

Data path between MCU and CPLD:
- 8-bit data bus
- write strobe from source side
- read/consume strobe from sink side
- full/empty or ready/valid flags

That is cleaner than trying to build a symmetric “general bus” between them.

If you want to keep pins down, I would avoid a truly bidirectional 8-bit data bus unless you really need it. Two reasons:

- bidirectional buses cost you direction control and tighter timing discipline
- modern MCUs are often happier with separate unidirectional signals or a simple parallel write/read protocol

You can still do it bidirectionally, but from a design-risk standpoint, these are the options I’d rank:

1. 8-bit bidirectional data + 3 to 4 handshake/control pins
Lowest pin count, slightly trickier control.

2. 8-bit data path optimized for “mostly write into CPLD,” plus a few status registers read back separately
Very practical if storage reads dominate and writeback is less frequent.

3. 2 small unidirectional FIFOs
Best behavior, highest pin count.

For your use case, option 1 or 2 is likely enough.

The key design decision is this: do not make the CPLD parse rings or filesystem semantics. Let the CPLD see only transfer descriptors such as:

- source/destination mode
- base address
- byte count
- execute

Then the MCU can say:
- “write 512 bytes to Z80 RAM at page X offset Y”
- “read 128 bytes from Z80 RAM at address Z”

and the CPLD just does the cycles.

A few concrete recommendations:

- Put a small FIFO in the CPLD if it fits. Even 16 bytes helps.
- Keep the MCU-CPLD protocol fixed-length and simple.
- Support only linear bursts with auto-increment at the CPLD level.
- Let the MCU handle ring wrap, ownership, and command interpretation.
- Add a “pause/refill needed” state so the CPLD can stall between sub-bursts if its FIFO empties.
- Keep read-from-Z80 and write-to-Z80 symmetric if possible, but optimize write-to-Z80 first since that is the common storage-read path.

One subtle point: if the CPLD has no significant local buffering, calling it a “burst” can be misleading. It is then really a paced transfer engine. That is still useful. The win is that Z80 bus timing stays deterministic and isolated from MCU firmware jitter.

So my answer is: yes, that architecture is sane, and yes, roughly 10 to 14 signals is enough for a very workable private MCU-CPLD transfer interface. The real trick is to include just enough elasticity in the CPLD so the Z80 bus side and MCU side do not have to be cycle-locked.

A good first version would be:

- 8-bit shared data bus
- `DIR`
- `DATA_STB`
- `READY`
- `START`
- `DONE`
- optional `IRQ`

Then separate latched registers for:
- Z80 address
- transfer length
- mode

That keeps the CPLD simple and the board reasonable.

If you want, I can sketch a concrete signal list and a minimal MCU↔CPLD DMA protocol next.

User: yes, please do

GitHub Copilot: A workable first cut is to treat the MCU↔CPLD link as two planes:

- a slow control plane for transfer setup
- a narrow byte-stream plane for payload

That keeps the CPLD simple. It only needs to know “copy N bytes to or from Z80 memory starting at address A,” while the MCU handles all higher-level storage logic.

**Signals**

I would start with 14 to 16 signals total, depending on how symmetric you want reads and writes to be.

Minimal shared payload bus:
- `MCD[7:0]` : 8-bit data bus between MCU and CPLD
- `MDIR` : direction, `0 = MCU->CPLD`, `1 = CPLD->MCU`
- `MSTB` : source says data is valid
- `MACK` : sink accepted byte
- `MSTART` : marks start of a transfer
- `MDONE` : marks end of transfer / engine idle
- `MIRQ` : optional interrupt from CPLD to MCU

Control register interface:
- `CREG[1:0]` : register select
- `CWR` : write selected control register
- `CRD` : read selected status register

That is 8 + 8 = 16 pins if you count everything. You can trim it a bit if some signals are multiplexed.

If you want the absolute simplest version, drop `CRD` and make status visible on a few dedicated pins. Then you are around 14 pins.

**Register Set**

The CPLD only needs a few registers:

1. `ADDR0`
Low 8 bits of Z80 address.

2. `ADDR1`
Middle 8 bits of Z80 address.

3. `ADDR2`
High bits / page / flags.
Since your machine has paging, this should encode the physical destination context cleanly rather than pretending all RAM is flat.

4. `LEN0`
Low byte of transfer length.

5. `LEN1`
High byte of transfer length.

6. `CTRL`
Bits like:
- direction: `0 = write to Z80 RAM`, `1 = read from Z80 RAM`
- auto-increment enable
- assert interrupt on completion
- maybe memory cycle type if your bus distinguishes them

7. `STATUS`
Bits like:
- busy
- fifo empty
- fifo full
- done
- bus granted
- error / timeout

That is enough for a first implementation.

**Recommended Internal CPLD Structure**

Do not try to implement the full 4 kB ring logic in the CPLD. Internally, keep only:

- transfer registers
- a tiny FIFO, ideally 16 to 64 bytes
- a Z80 bus master state machine
- a small MCU-side handshake state machine

That is the right level of complexity for a CPLD.

**How A Write-To-Z80 Transfer Works**

This is the main storage-read case: MCU has read file data locally and wants it copied into Z80 RAM.

1. MCU fills `ADDR`, `LEN`, and `CTRL`.
2. MCU asserts `MSTART`.
3. CPLD requests the Z80 bus.
4. Once bus grant is active, CPLD begins consuming bytes from the MCU over `MCD[7:0]`.
5. For each accepted byte, CPLD performs one Z80 memory write cycle and increments address.
6. When `LEN` reaches zero, CPLD releases the bus and asserts `MDONE` or `MIRQ`.

The payload handshake is simply:

- MCU places byte on `MCD`
- MCU asserts `MSTB`
- CPLD latches byte when ready and pulses or asserts `MACK`
- MCU moves to next byte

That is easy to drive from firmware.

**How A Read-From-Z80 Transfer Works**

This is the storage-write case: device wants to fetch a block from Z80 RAM.

1. MCU fills `ADDR`, `LEN`, and `CTRL` with direction set to read-from-Z80.
2. MCU asserts `MSTART`.
3. CPLD requests the Z80 bus.
4. CPLD performs Z80 memory read cycles and pushes bytes toward MCU.
5. MCU accepts bytes using the same `MSTB/MACK` handshake, but with `MDIR=1`.
6. On completion, CPLD releases the bus and raises `MDONE`.

This gives you symmetry without needing separate buses.

**Recommended Handshake Semantics**

Use a ready/valid style handshake, even if you name the signals differently.

For `MCU -> CPLD`:
- MCU drives byte and raises `MSTB`
- CPLD raises `MACK` when consumed
- MCU drops `MSTB` and advances

For `CPLD -> MCU`:
- CPLD drives byte and raises `MSTB`
- MCU raises `MACK` when consumed
- CPLD drops `MSTB` and advances

That lets one pair of handshake lines work in both directions.

**Why A Tiny FIFO Helps**

Without any FIFO, the CPLD must wait on nearly every byte for the MCU. That still works, but bus hold time increases.

Even a 16-byte FIFO helps because the sequence becomes:

- MCU preloads a few bytes
- CPLD takes the bus and writes a short burst
- MCU refills while CPLD drains
- if FIFO empties, CPLD pauses locally, not by losing state

So the system behaves much better even with a very small amount of elasticity.

**A Minimal Protocol Example**

Write 512 bytes to Z80 RAM:

1. MCU writes:
- `ADDR = destination`
- `LEN = 512`
- `CTRL = write_to_z80 | autoinc | irq_on_done`

2. MCU asserts `MSTART`.

3. CPLD:
- sets `busy`
- requests bus
- waits for grant
- starts draining incoming bytes into memory writes

4. MCU streams 512 bytes over `MCD` using `MSTB/MACK`.

5. CPLD:
- decrements internal count
- releases bus at zero
- sets `done`
- optionally asserts `MIRQ`

**What The CPLD State Machine Actually Does**

The core states are simple:

1. `IDLE`
Wait for `MSTART`.

2. `REQ_BUS`
Assert bus request, wait for CPU release/grant.

3. `TRANSFER`
For each byte:
- if direction is MCU->Z80, wait for input byte then issue memory write cycle
- if direction is Z80->MCU, issue memory read cycle then present byte to MCU
- increment address
- decrement count

4. `COMPLETE`
Release bus, raise done/irq, return to idle.

That is a good CPLD problem. It avoids parsing rings, file handles, or variable-sized descriptors.

**Where The 4 kB Shared Page Fits**

Your 4 kB page can still be the software-visible transport area, but the CPLD does not need to understand its internal structure.

The MCU can interpret:
- command ring
- completion ring
- data buffer ownership

Then it tells the CPLD only:
- move bytes from my local buffer to Z80 page offset X
or
- fetch bytes from Z80 page offset X into my local buffer

That keeps the smart part in firmware and the deterministic part in logic.

**My Recommendation For Rev 1**

I would build rev 1 around:

- 8-bit bidirectional data bus `MCD[7:0]`
- `MDIR`
- `MSTB`
- `MACK`
- `MSTART`
- `MDONE`
- optional `MIRQ`
- 5 to 7 simple control/status registers
- a 16-byte or 32-byte FIFO inside the CPLD if it fits

That is small enough to be realistic and structured enough to grow.

If you want, I can next turn this into one of two concrete artifacts:

1. a pin-level signal table with exact direction and meaning for each pin
2. a register map and step-by-step firmware/CPLD transaction sequence for `DMA write`, `DMA read`, and `status polling`

User: The z80 program should tell the smart-device where it wants the data written, or where it has prepared the data to be read by the smart device/mcu. The command-plane of the protocol communicates what the operation is and for instance a file name etc.
I am not sure if I want the commands to be just another DMA with predefined structures or some sort of IO driven mechanism where the CPLD implemens some IO ports and stores address, length and operation etc. Other metadata (file name) will then be a problem. But there should be a trigger that the z80 app can set/send that tells the smart-device that it can do its thing.
Interrupt on done is a must.
Ideally I would also want the z80 program to be able to setup a device-to-device exchange but that can wait.

GitHub Copilot: The cleanest answer is a hybrid, not “all DMA” or “all I/O”.

Use I/O for control and triggering, and use DMA-visible memory for everything variable-sized. That gives you a simple hardware model and avoids turning file names and long metadata into awkward port traffic.

What I would recommend is:

1. The Z80 builds a command descriptor in RAM.
2. The descriptor contains:
- operation
- data buffer address
- data length
- metadata pointer
- metadata length
- flags
- request id or tag

3. The Z80 pokes one or two I/O registers in the smart-device:
- descriptor address
- `GO` / doorbell

4. The smart-device raises DMA, fetches the descriptor, then fetches any extra metadata such as the filename from the pointer in the descriptor.

5. When done, it writes status back to a completion area or updates the descriptor, then interrupts the Z80.

That is the best fit for what you described.

Why this is better than pure I/O commands:
- filenames and paths stay in normal RAM, so they can be arbitrary length
- you avoid designing a complicated port-streaming protocol for metadata
- the CPLD only needs a few I/O registers, not a full command parser
- the same mechanism scales later to device-to-device transfers

Why this is better than “commands are just another DMA blob” with no I/O:
- you still need a clean trigger
- you still need status/ownership bits somewhere
- a tiny I/O doorbell interface is much simpler than polling memory blindly
- reset/error/abort becomes easier

So I would make the command plane look like this:

I/O registers:
- `CMD_DESC_LO`
- `CMD_DESC_HI`
- `CMD_DESC_PAGE` or bank/page selector if needed
- `CONTROL`
- `STATUS`
- `IRQ_ACK`

And let `CONTROL` contain things like:
- `GO`
- `ABORT`
- `RESET`

Let `STATUS` contain:
- `BUSY`
- `DONE`
- `ERROR`
- maybe `IRQ_PENDING`

Then put the real command payload in RAM.

A good first descriptor could be fixed-size, something like:

```c
struct DeviceCommand {
    uint8_t opcode;
    uint8_t flags;
    uint16_t request_id;

    uint32_t data_addr;
    uint16_t data_len;

    uint32_t meta_addr;
    uint16_t meta_len;

    uint32_t result_addr;
    uint16_t result_len;

    uint8_t status;
    uint8_t error;
};
```

The exact widths depend on how your page/bank system is encoded, but the structure is the important part.

That gives you a clean split:

- `data_addr/data_len`: actual file payload buffer
- `meta_addr/meta_len`: filename, path, open mode, seek info, whatever extra command data is needed
- `result_addr/result_len`: optional return payload for things like directory listings or stat data

For example:

`OPEN`:
- `opcode = OPEN`
- `meta_addr -> "SYS/CONFIG.TXT\0"`
- `meta_len = filename length`
- `data_addr = 0`
- result written into descriptor or result buffer

`READ`:
- `opcode = READ`
- `data_addr = destination buffer in Z80 RAM`
- `data_len = requested bytes`
- metadata may be empty if using an already-open handle

`WRITE`:
- `opcode = WRITE`
- `data_addr = source buffer in Z80 RAM`
- `data_len = bytes to write`

That avoids inventing separate special cases for “commands with strings” versus “commands with data”.

The CPLD role then becomes much simpler:
- expose a few I/O registers
- latch the descriptor pointer when `GO` is written
- notify the MCU
- optionally help fetch the descriptor or perform DMA bursts
- assert interrupt on completion

The MCU role:
- interpret the descriptor
- fetch any extra metadata via DMA
- do FAT/filesystem work
- move file data to/from the specified buffer
- update completion status
- trigger interrupt

That is a much cleaner partition than making the CPLD understand filenames or command syntax.

For completion, I would strongly prefer:
- interrupt on done
- plus a completion status field in memory

Do not rely on interrupt alone. The interrupt is the wakeup, but the descriptor/result area is the truth. That makes retries, debugging, and future multitasking much cleaner.

On the “where should the operation be set” question: use the descriptor, not a port. The port should just be the trigger. In other words:

- operation code lives in RAM descriptor
- I/O port says only “command at address X is ready”

That is the simplest model.

For future device-to-device exchange, this same model extends nicely. Later you can define a descriptor whose source or target is not “CPU RAM” but “device endpoint”. For example:
- source device id
- destination device id
- shared buffer descriptor
- command chaining

You do not need to solve that now, but this descriptor-based design does not block it.

My recommendation for rev 1 is therefore:

1. Use I/O only as doorbell/control/status.
2. Put all real command content in a fixed-size command descriptor in RAM.
3. Put variable-length metadata like filenames in separate RAM buffers referenced by the descriptor.
4. Use DMA for descriptor fetch, metadata fetch, and payload transfer.
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

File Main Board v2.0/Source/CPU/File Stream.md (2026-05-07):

# Files and Streams

All Device IO functions are Async.

An 'uri' points to a device (or file). This identifies the device as well as any sub-entity (think of a file in a directory on a file-system).

Stupid example:

```
u:0          → UART 0
u:1          → UART 1
s:boot/x.com → SD card, path boot/x.com
p:3          → MMU page 3
r:date       → RTC date
i:           → stdin  (alias)
o:           → stdout (alias)
x:0          → expansion bus device 0
```

`File_Open(uri)` returns a handle that represents the item/entity identified in the uri, created by the specific driver of the targeted device.

`StreamWriter` => `Stream` => `StreamReader` // async api

A `Stream` is always one-way - it's writer produces data which the reader consumes.

For reading, a Device implements the StreamWriter and the client uses a StreamReader to get the data.
For Writing, a Device implement the StreamReader and the client uses a StreamWriter to send the data.

The `Stream` can be a ring-buffer:

```
Reading from SD card:

  [SD hardware]
       │
  FileDesc (sd driver)  ← handle lives here, in the Writer
       │
  StreamWriter ──► [ring buffer] ──► StreamReader
                                           │
                                      application
                                      (no handle — app IS the reader)
```

```
Writing to UART:

  application
  (no handle — app IS the writer)
       │
  StreamWriter ──► [ring buffer] ──► StreamReader
                                           │
                                      FileDesc (uart driver) ← handle lives here
                                           │
                                      [UART hardware]
```

The `Stream` can be a direct connection to a device?
Do you need a stream for a direct connection?
Or will there always be a need for a buffer.

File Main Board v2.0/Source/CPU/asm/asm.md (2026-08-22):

# Z80 Assembly

`LD HL, $0000`

```asm
; 3b-10c
ld hl, $0000    ; 3b-10c

; 4b-14c
ld h, $00   ; 2b-7c
ld l, $00   ; 2b-7c

; 3b-12c
xor a       ; 1b-4c
ld h, a     ; 1b-4c
ld l, a     ; 1b-4c
```

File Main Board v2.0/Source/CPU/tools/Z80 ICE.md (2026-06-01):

# Z80 In-Circuit Emulator

- Wiki: https://github.com/hoglet67/AtomBusMon/wiki
- Getting Started: https://github.com/hoglet67/AtomBusMon/wiki/User-Manual---Getting-Started
- Commands: https://github.com/hoglet67/AtomBusMon/wiki/User-Manual---Command-Reference

We have the eepizza variant with the Z80 adapter board:
https://github.com/hoglet67/AtomBusMon/wiki/Z80-CPU-Adapter
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

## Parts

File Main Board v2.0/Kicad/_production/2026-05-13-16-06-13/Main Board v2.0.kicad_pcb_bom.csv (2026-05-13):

Designator | Quantity | Value | Footprint | Package | MPN | DNP | Mount_Type | Description | KiLib_Generator
C1, C10, C11, C12, C13, C14, C15, C16, C17, C2, C21, C22, C23, C24, C25, C3, C4, C5, C6, C7, C8, C9 | 22 | 100n | C_0603_1608Metric_Pad1.08x0.95mm_HandSolder |  |  |  | smt | [C2,C21,C22,C23,C24,C25,C3,C4,C5,C6,C7,C8,C9]Unpolarized capacitor; [C17]Unpolarized capacitor, small symbol | SMD_2terminal_chip_molded
C18, C19, C20 | 3 | 100u | CP_Radial_D8.0mm_P3.80mm |  |  |  | tht | [C18,C19]Polarized capacitor, small symbol; [C20]Polarized capacitor | capacitor/THT/other
J1 | 1 | Bus_ISA_16bit | BUS_AT |  |  |  | tht | 16-bit ISA-AT bus connector
J2 | 1 | +3V3 Supply | PinHeader_1x01_P2.54mm_Vertical |  |  |  | tht | Generic connector, single row, 01x01, script generated | connector/pin_header_socket
J3 | 1 | JTAG | IDC-Header_2x07_P2.54mm_Vertical |  |  |  | tht | Generic connector, double row, 02x07, odd/even pin numbering scheme (row 1 odd numbers, row 2 even numbers), script generated (kicad-library-utils/schlib/autogen/connector/) | connector/pin_header_socket
J4 | 1 | AVR-JTAG-10 | IDC-Header_2x05_P2.54mm_Vertical |  |  |  | tht | Atmel 10-pin JTAG connector | connector/pin_header_socket
J5 | 1 | USART0 | PinHeader_1x04_P2.54mm_Vertical |  |  |  | tht | Generic connector, single row, 01x04, script generated (kicad-library-utils/schlib/autogen/connector/) | connector/pin_header_socket
J6 | 1 | USART1 | PinHeader_1x04_P2.54mm_Vertical |  |  |  | tht | Generic connector, single row, 01x04, script generated (kicad-library-utils/schlib/autogen/connector/) | connector/pin_header_socket
J7 | 1 | PS2KB | PinHeader_1x04_P2.54mm_Vertical |  |  |  | tht | Generic connector, single row, 01x04, script generated (kicad-library-utils/schlib/autogen/connector/) | connector/pin_header_socket
J8 | 1 | SPI-SDCard | PinSocket_1x06_P2.54mm_Vertical |  |  |  | tht | Generic connector, single row, 01x06, script generated (kicad-library-utils/schlib/autogen/connector/) | connector/pin_header_socket
R1, R10, R11, R12, R13, R14, R15, R16, R17, R18, R19, R2, R20, R21, R22, R23, R24, R25, R26, R27, R28, R29, R3, R30, R31, R33, R34, R4, R5, R6, R7, R8, R9 | 33 | 10k | R_0603_1608Metric_Pad0.98x0.95mm_HandSolder |  |  |  | smt | Resistor, small symbol | SMD_2terminal_chip_molded
R32 | 1 | 100R | R_0603_1608Metric_Pad0.98x0.95mm_HandSolder |  |  |  | smt | Resistor, small symbol | SMD_2terminal_chip_molded
R35, R36, R37 | 3 | 4k7 | R_0603_1608Metric_Pad0.98x0.95mm_HandSolder |  |  |  | smt | Resistor, small symbol | SMD_2terminal_chip_molded
SW1 | 1 | Reset | SW_Tactile_SPST_Angled_PTS645Vx83-2LFS |  |  |  | tht | Push button switch, generic, two pins
U1, U10, U3 | 3 | 74HCT245 | DIP-20_W7.62mm_Socket_LongNarrowPads |  |  |  | tht | Octal BUS Transceivers, 3-State outputs | package/DIP/legacy
U11 | 1 | ATmega1284-P | DIP-40_W15.24mm_Socket_LongPads |  |  |  | tht | 20MHz, 128kB Flash, 16kB SRAM, 4kB EEPROM, JTAG, DIP-40 | package/DIP/legacy
U2, U4 | 2 | GLT725608 | SOJ-28_7.62x18.415mm_P1.27mm |  |  |  | smt | 32Kx8 bit Low Power CMOS Static RAM, 25/45ns, Automotive | package/gullwing
U5 | 1 | AS6C4008-55PCN | SOP-32_11.305x20.495mm_P1.27mm |  |  |  | smt | 512K x 8 Low Power CMOS RAM, DIP-32 | package/gullwing
U6 | 1 | AM29F040B | 3M_Textool_232-1288-00-0602J_2x16_P2.54mm |  |  |  | tht | 512K x 8 Low Power CMOS Flash, DIP-32
U7 | 1 | XC95288XL-TQ144 | TQFP-144_20x20mm_P0.5mm |  |  |  | smt | CPLD, 288 Macrocells, 6400 Usable Gates | package/gullwing
U8 | 1 | AP1117-33 | SOT-223-3_TabPin2 |  |  |  | smt | 1A Low Dropout regulator, positive, 3.3V fixed output, SOT-223
U9 | 1 | Z80CPU | 3M_Textool_240-1288-00-0602J_2x20_P2.54mm |  |  |  | tht | 8-bit General Purpose Microprocessor, DIP-40
Y1 | 1 | 20MHz | Oscillator_DIP-8_LargePads |  |  |  | tht | Crystal Clock Oscillator, DIP14-style metal package
Y2 | 1 | 32.768kHz | Crystal_C26-LF_D2.1mm_L6.5mm_Horizontal |  |  |  | tht | Two pin crystal | crystal_resonator_oscillator

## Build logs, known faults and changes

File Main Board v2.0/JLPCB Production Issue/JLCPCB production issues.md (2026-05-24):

# JLCPCB Production Issues

To the best of my knowledge I uploaded the [13-05 gerbers](./Kicad/_production/2026-05-13-16-06-13/Main%20Board%20v2.0.kicad_pcb_gerber.zip) to place the order with JLCPCB (W2026051322175247) at 13-05-2026.

Upon receiving the PCBs (which was pretty quick) I noticed that all my ground vias were not present on the PCB manufactured by JLCPCB.

I contacted them and they (after sales) were pretty adament that my original gerbers did not include any ground vias.

JLCPCB
```
Dear Customer,
Thank you for contacting JLCPCB regarding your order.
From our live chat conversation, you indicated that all of the ground vias in your PCBs were removed. Before we can investigate further, could you kindly provide a picture clearly indicating where the ground vias were removed?
Once we receive the image, we will proceed with checking the issue.
Thank you for your cooperation.
Best regards,
Nick
```

Me
```
Hi Nick,
I have attached a photo of the right-bottom corner where I had placed some via's around the edge. Clearly they are not there. Also attached is the zip file I uploaded for this order.
Looking forward to your reply.
Marc Jacobi
```

JLCPCB
```
Dear Marc,
Thank you for your message and for providing the photo and the ZIP file.
Upon comparing the Gerber file you provided via email with the Gerber file you originally uploaded for your order, we found that they are different. The file you uploaded for production does not contain the vias you indicated, as shown in the images below:
Gerber file uploaded for production:
```
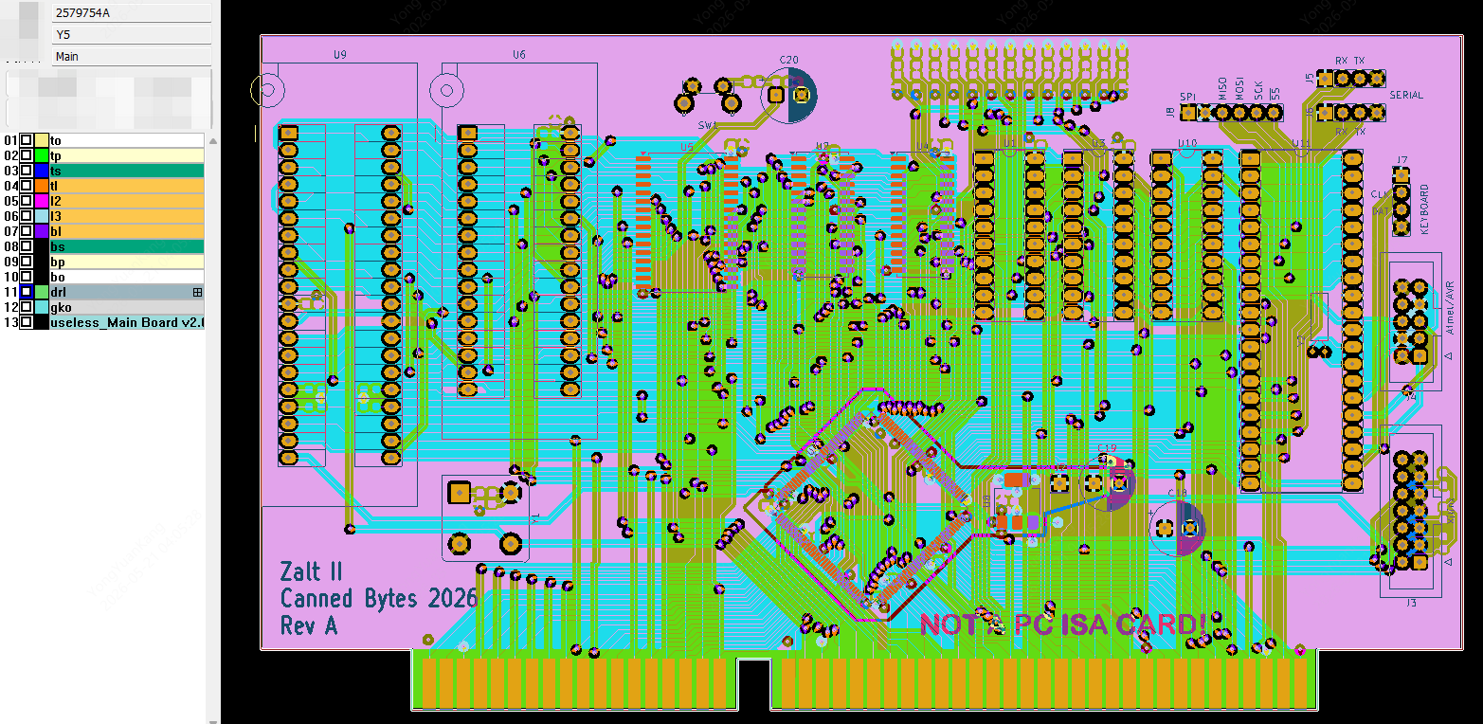
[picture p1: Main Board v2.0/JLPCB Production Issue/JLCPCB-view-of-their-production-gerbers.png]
JLCPCB production gerbers

```
Gerber file you provided via email:
```
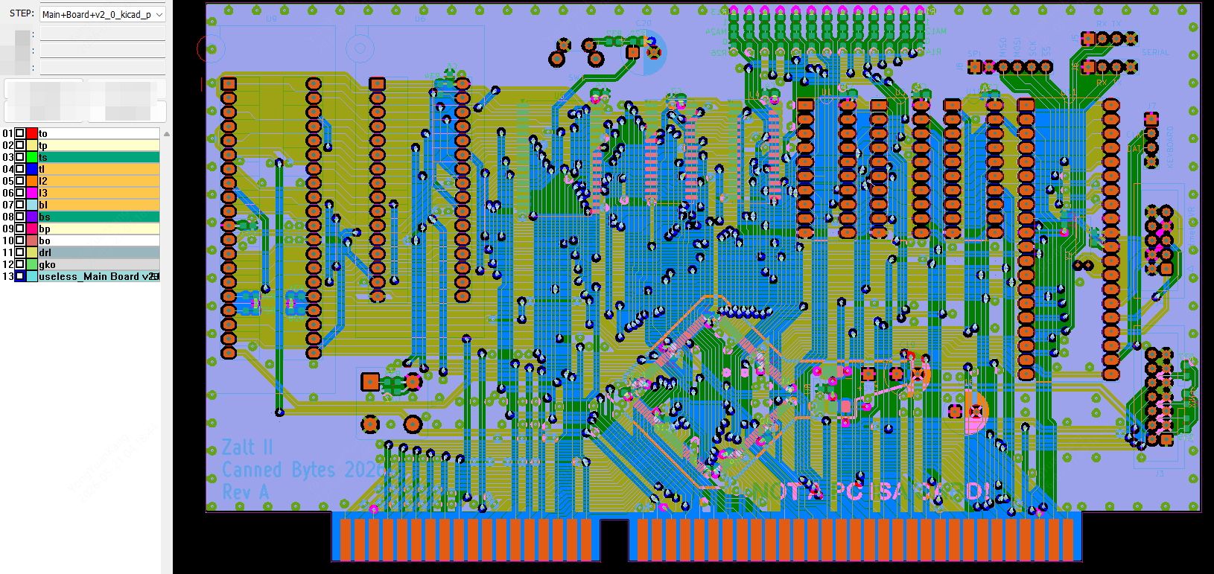
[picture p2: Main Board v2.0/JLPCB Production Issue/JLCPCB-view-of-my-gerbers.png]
JLCPCB view of my attached gerbers

```
Your PCBs were manufactured exactly according to the Gerber file you uploaded at the time of order placement.
```

My reply:
```
Hi Nick,
Clearly the production file I can download from the order page, is NOT my original file.
This is not a satisfactory conclusion.
Marc
```

JLCPCB:
```
Dear Marc,
Thank you for your message, and we sincerely apologize for the inconvenience caused.
We have noted your concern. We will request our after‑sales team to review your order issue again. Once we have determined the cause, we will get back to you.
Thank you for your patience.
Best regards,
Nick
```

There followed some more emails offering me a $3 coupon!
I just left it at that.

## 3V3 inner layer plane.

> Later I noticed that the 3V3 plane was not entirely connected, too. There are no errors in Kicad that indicate that they were not connected so is this another production issue?

It turns out that in my design I had two separate fills touching in Kicad.
In their gerbers these do not touch anymore and cause the 3V3 plane to be interrupted.

So if you're using separate fills for the same net, overlap them generously.

Another part that was also a separate fill overlapped, and did connect ok on the production gerbers.

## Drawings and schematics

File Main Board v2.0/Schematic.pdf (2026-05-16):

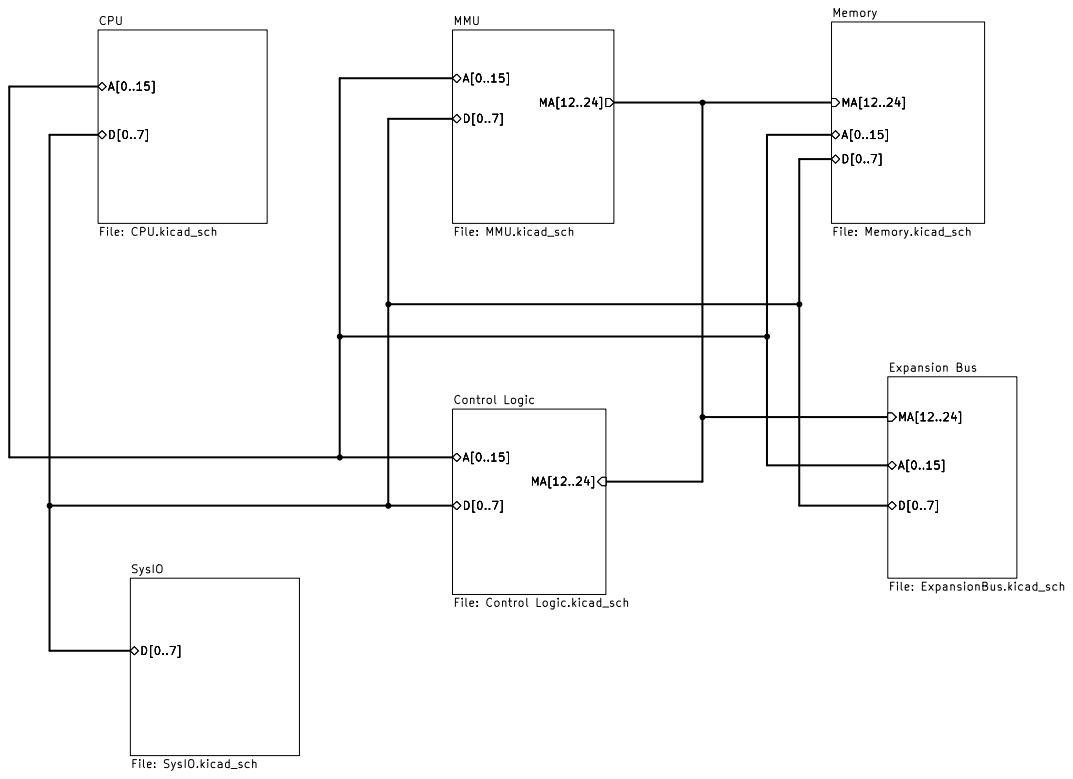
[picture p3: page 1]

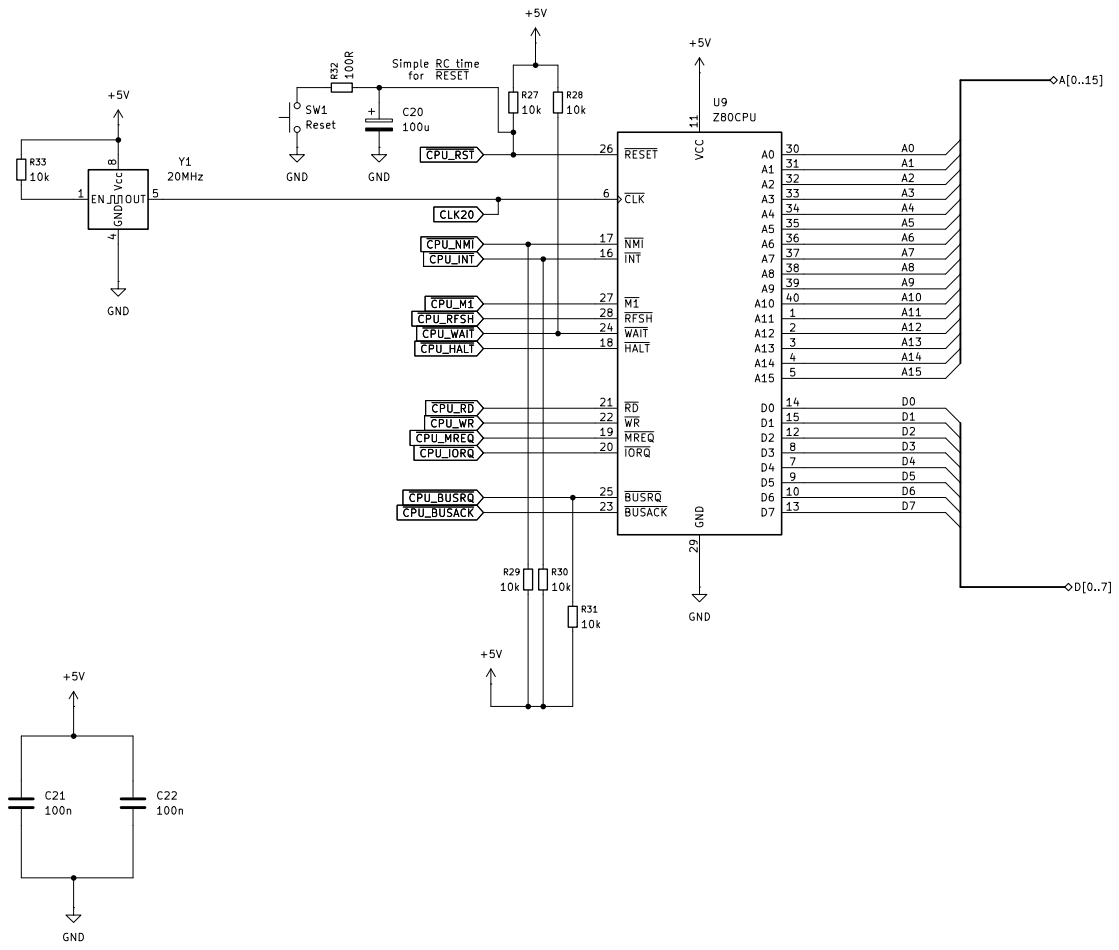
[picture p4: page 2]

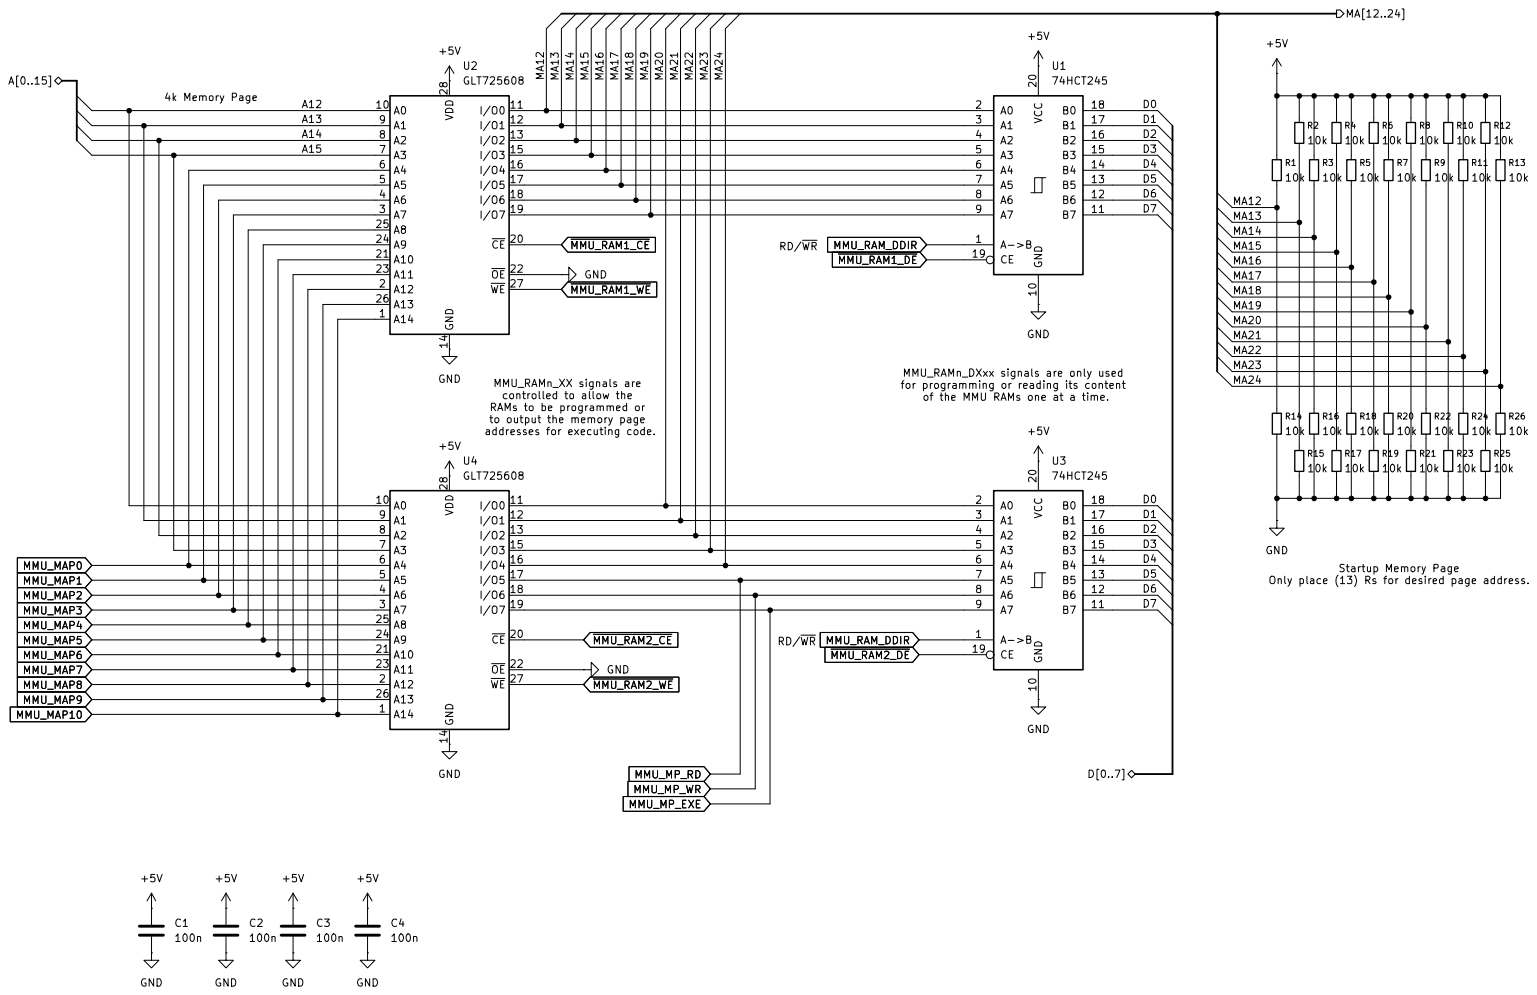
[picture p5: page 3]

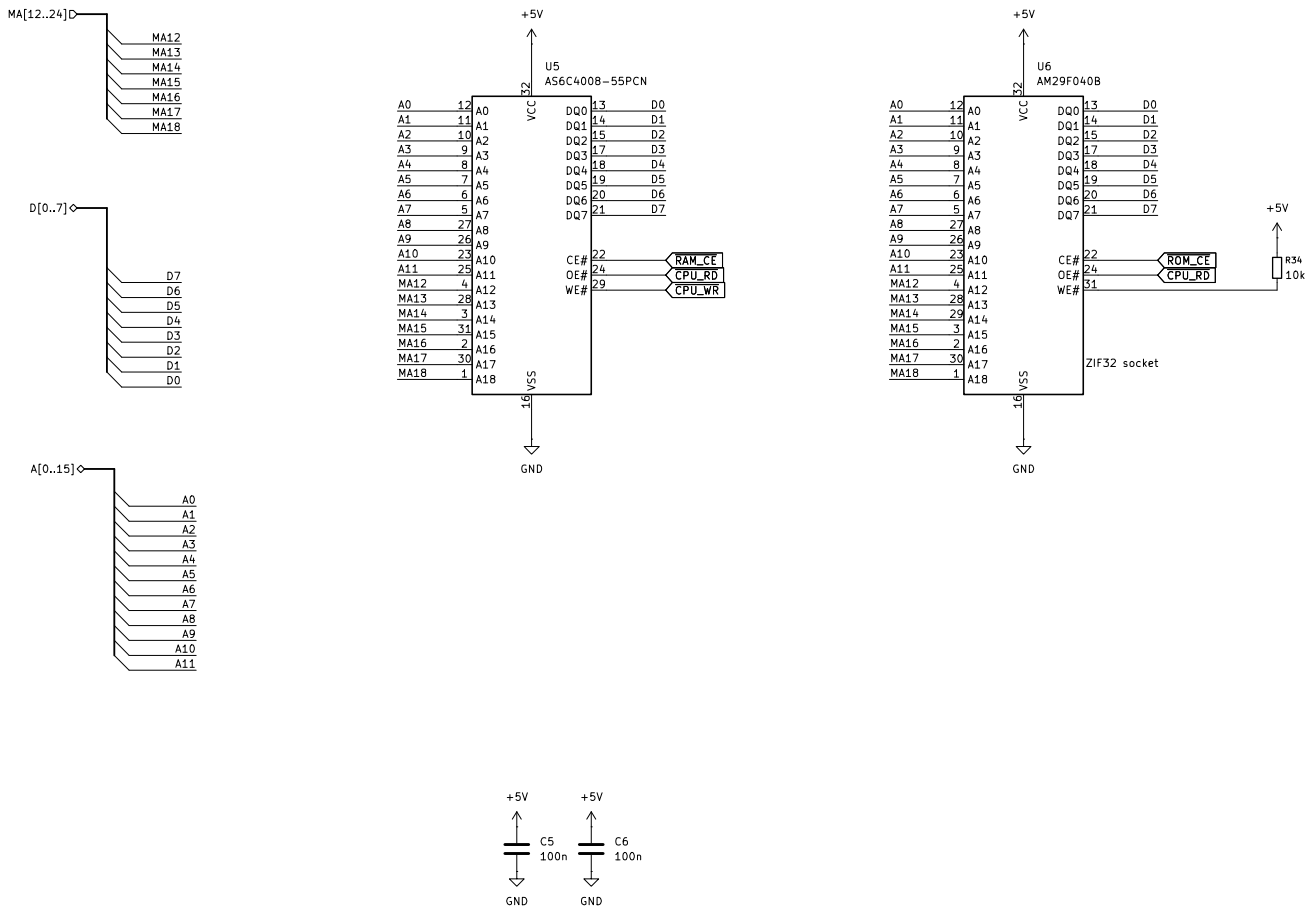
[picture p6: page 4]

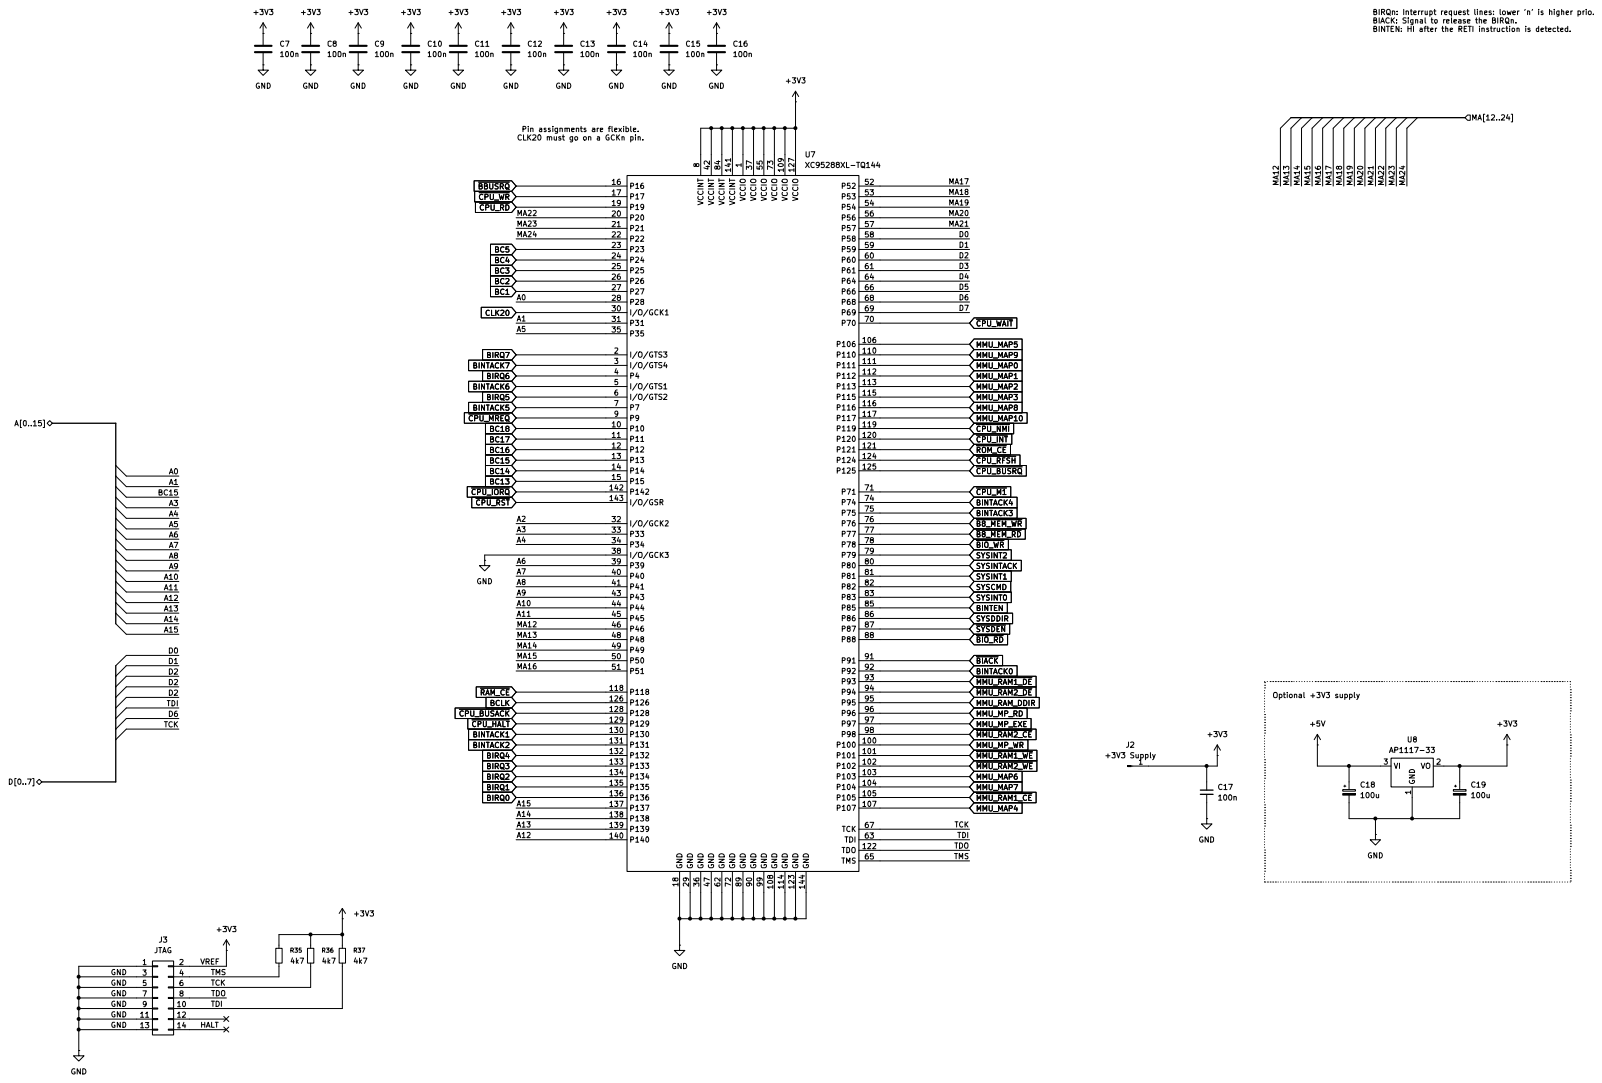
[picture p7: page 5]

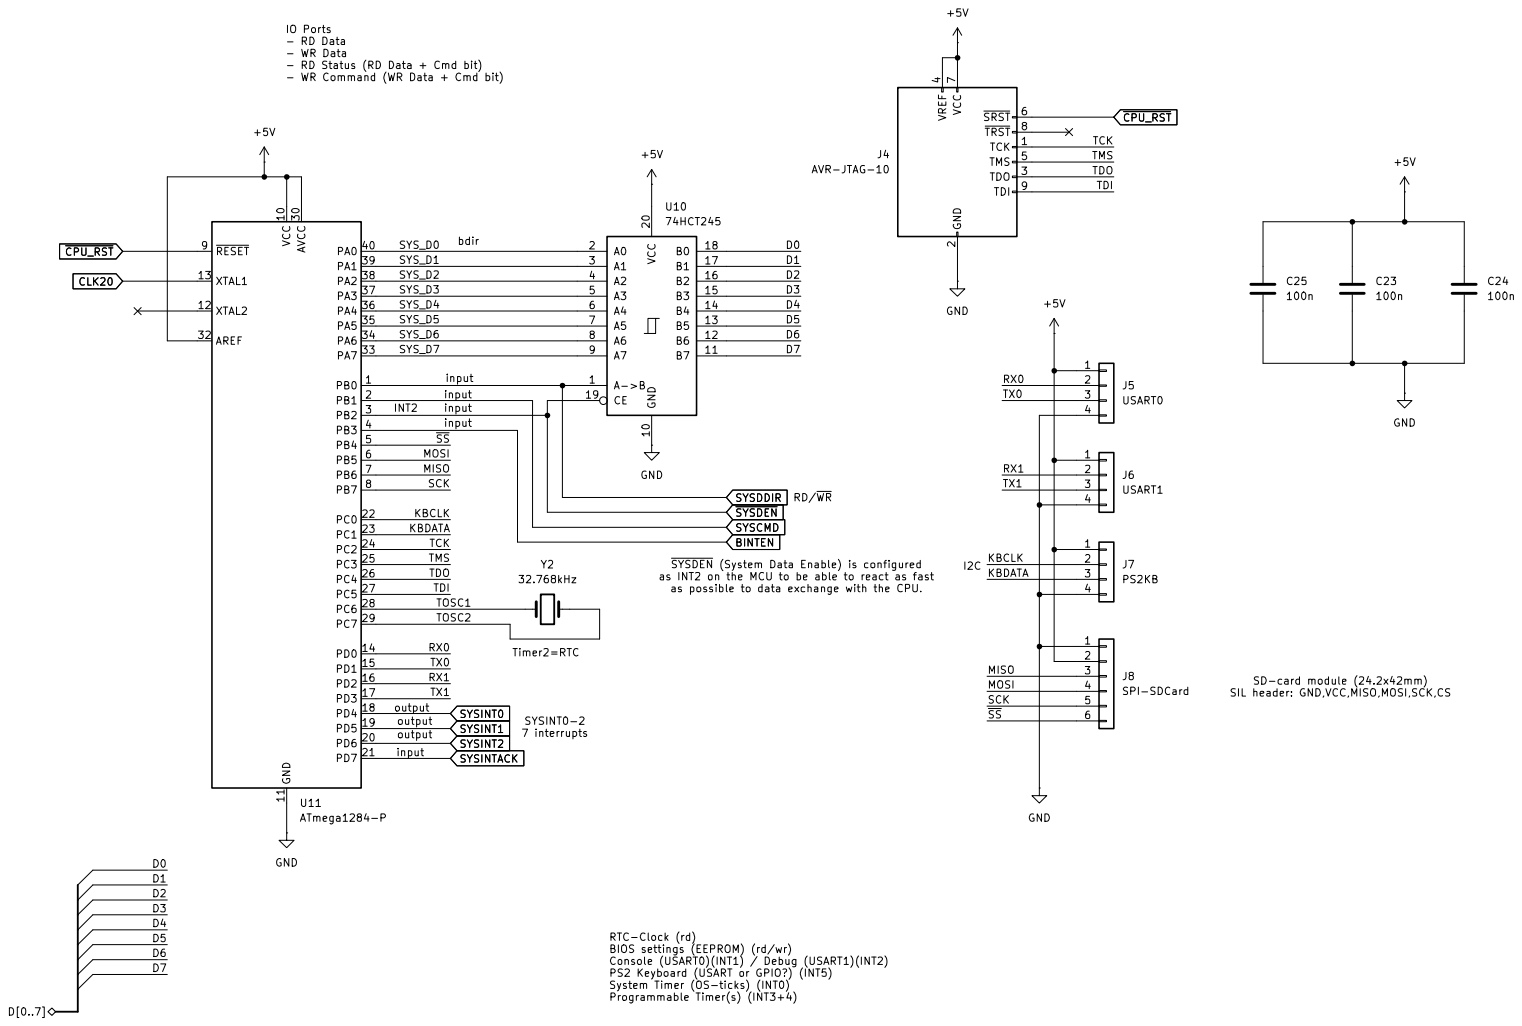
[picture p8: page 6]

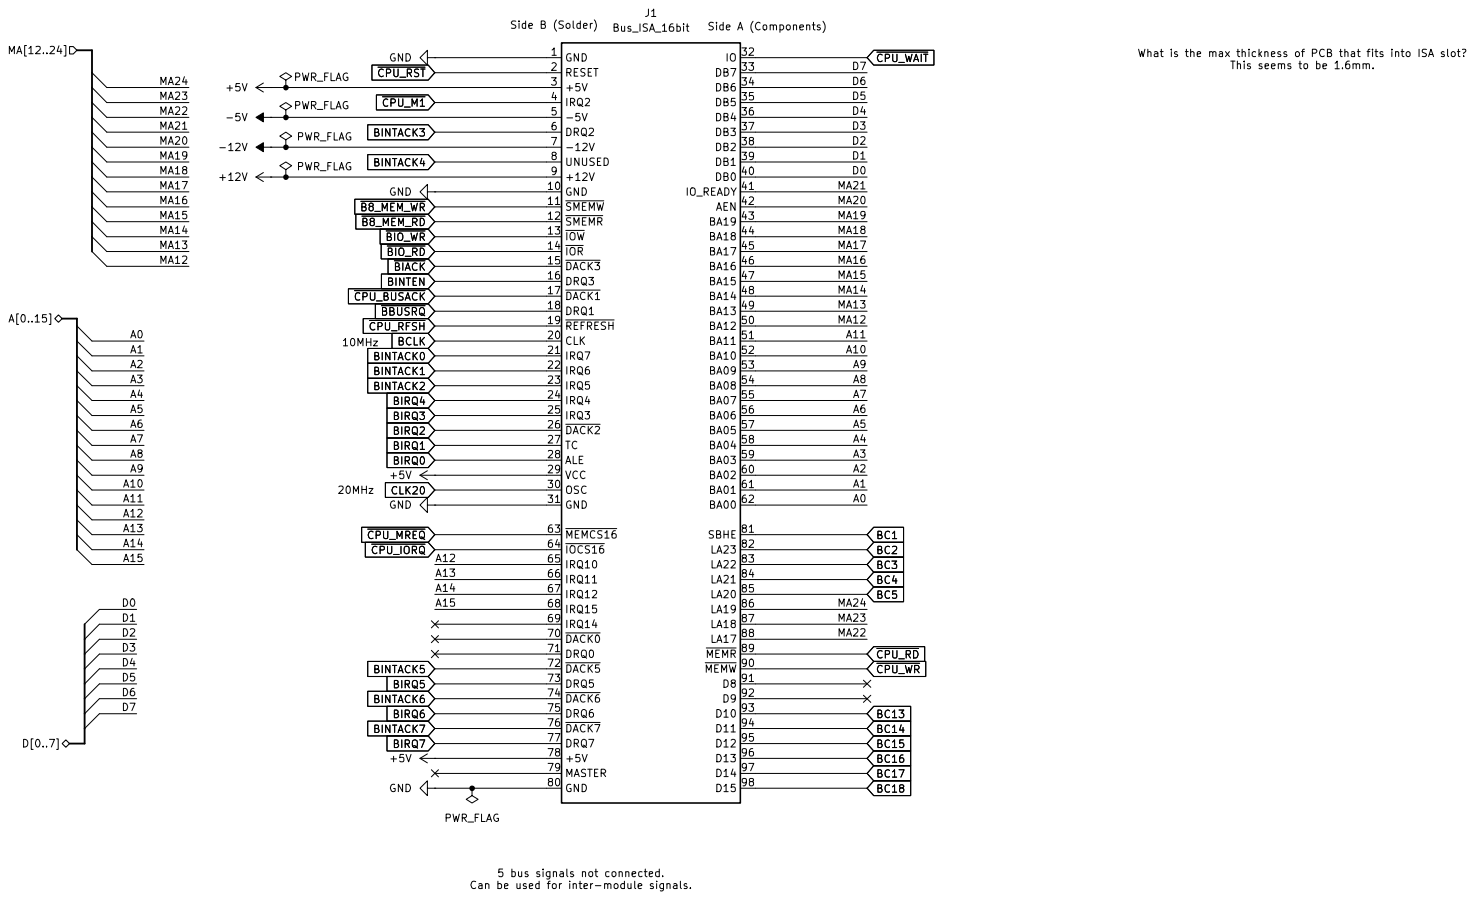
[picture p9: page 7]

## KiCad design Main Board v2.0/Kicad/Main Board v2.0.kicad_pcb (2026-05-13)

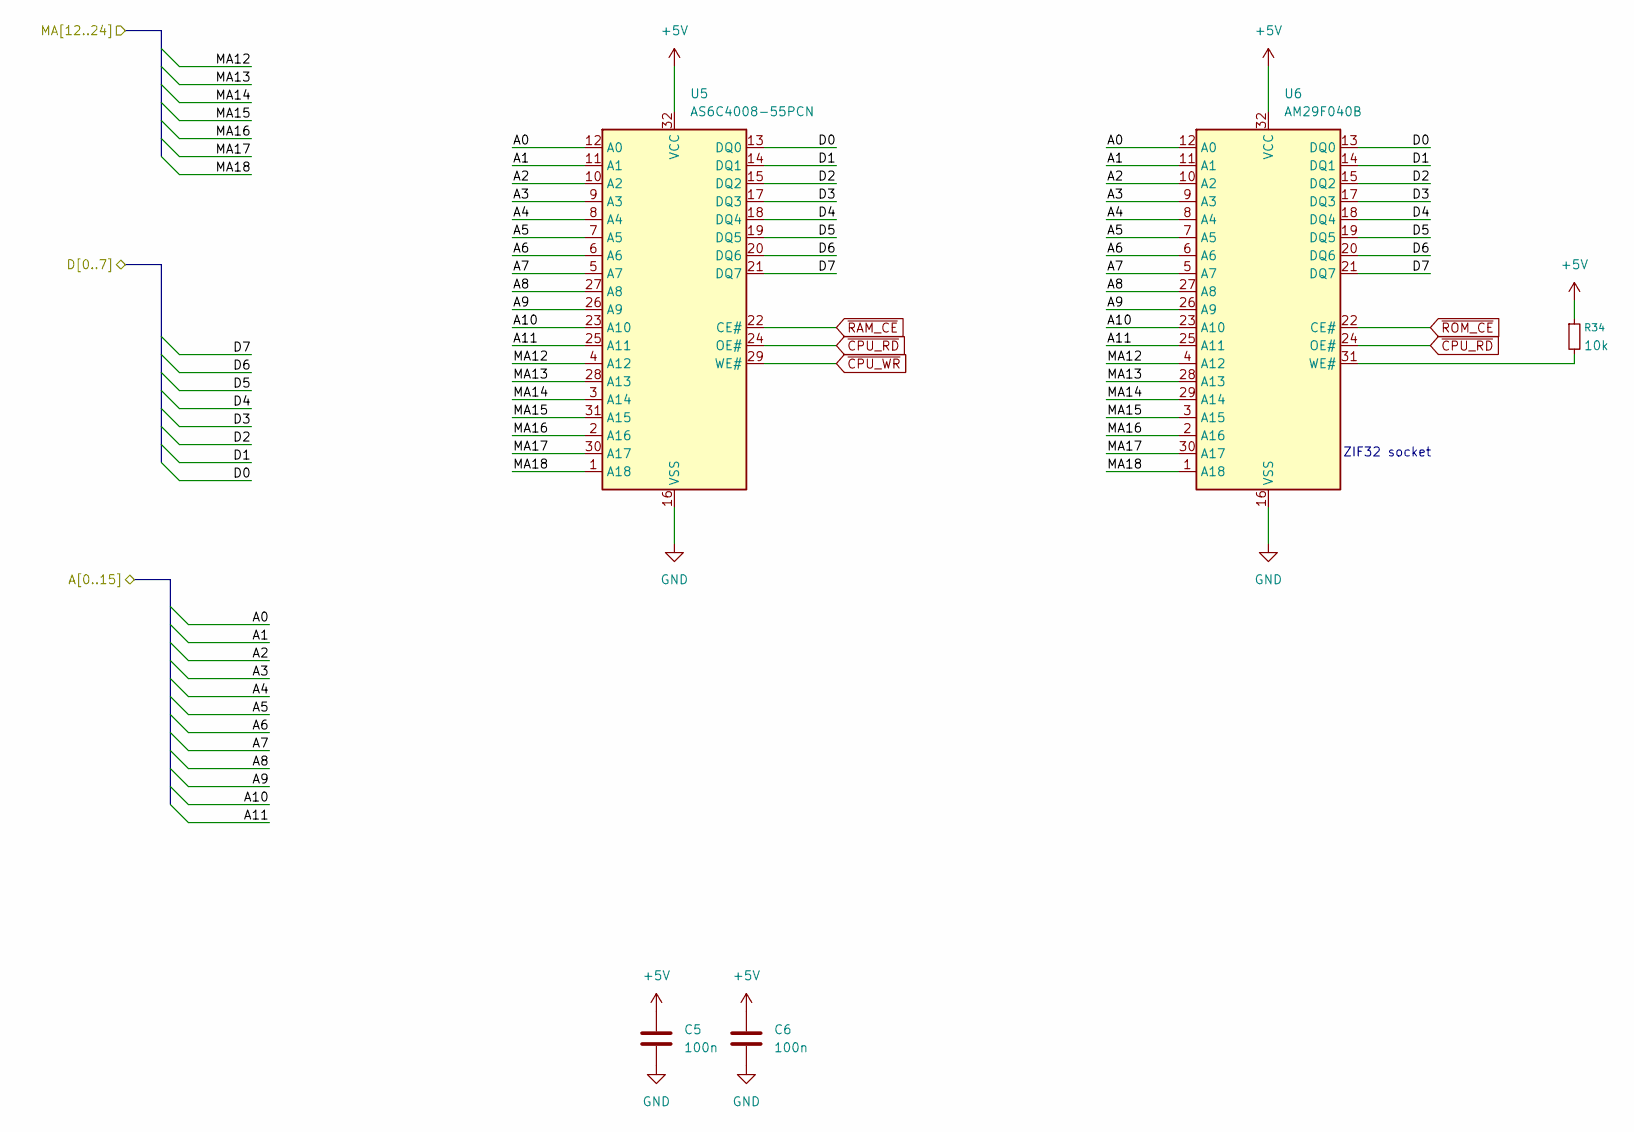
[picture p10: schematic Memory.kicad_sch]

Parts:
C5, C6: 100n; C_0603_1608Metric_Pad1.08x0.95mm_HandSolder
R34: 10k; R_0603_1608Metric_Pad0.98x0.95mm_HandSolder
U5: AS6C4008-55PCN; SOP-32_11.305x20.495mm_P1.27mm
U6: AM29F040B; 3M_Textool_232-1288-00-0602J_2x16_P2.54mm

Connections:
+5V: C5.1, C6.1, R34.1, U5.32 (VCC), U6.32 (VCC); also elsewhere on the board
/CPU/A0: U5.12 (A0), U6.12 (A0); also elsewhere on the board
/CPU/A1: U5.11 (A1), U6.11 (A1); also elsewhere on the board
/CPU/A2: U5.10 (A2), U6.10 (A2); also elsewhere on the board
/CPU/A3: U5.9 (A3), U6.9 (A3); also elsewhere on the board
/CPU/A4: U5.8 (A4), U6.8 (A4); also elsewhere on the board
/CPU/A5: U5.7 (A5), U6.7 (A5); also elsewhere on the board
/CPU/A6: U5.6 (A6), U6.6 (A6); also elsewhere on the board
/CPU/A7: U5.5 (A7), U6.5 (A7); also elsewhere on the board
/CPU/A8: U5.27 (A8), U6.27 (A8); also elsewhere on the board
/CPU/A9: U5.26 (A9), U6.26 (A9); also elsewhere on the board
/CPU/A10: U5.23 (A10), U6.23 (A10); also elsewhere on the board
/CPU/A11: U5.25 (A11), U6.25 (A11); also elsewhere on the board
/CPU/D0: U5.13 (DQ0), U6.13 (DQ0); also elsewhere on the board
/CPU/D1: U5.14 (DQ1), U6.14 (DQ1); also elsewhere on the board
/CPU/D2: U5.15 (DQ2), U6.15 (DQ2); also elsewhere on the board
/CPU/D3: U5.17 (DQ3), U6.17 (DQ3); also elsewhere on the board
/CPU/D4: U5.18 (DQ4), U6.18 (DQ4); also elsewhere on the board
/CPU/D5: U5.19 (DQ5), U6.19 (DQ5); also elsewhere on the board
/CPU/D6: U5.20 (DQ6), U6.20 (DQ6); also elsewhere on the board
/CPU/D7: U5.21 (DQ7), U6.21 (DQ7); also elsewhere on the board
/Control Logic/MA12: U5.4 (A12), U6.4 (A12); also elsewhere on the board
/Control Logic/MA13: U5.28 (A13), U6.28 (A13); also elsewhere on the board
/Control Logic/MA14: U5.3 (A14), U6.29 (A14); also elsewhere on the board
/Control Logic/MA15: U5.31 (A15), U6.3 (A15); also elsewhere on the board
/Control Logic/MA16: U5.2 (A16), U6.2 (A16); also elsewhere on the board
/Control Logic/MA17: U5.30 (A17), U6.30 (A17); also elsewhere on the board
/Control Logic/MA18: U5.1 (A18), U6.1 (A18); also elsewhere on the board
GND: C5.2, C6.2, U5.16 (VSS), U6.16 (VSS); also elsewhere on the board
unnamed: R34.2, U6.31 (WE#)
~CPU_RD: U5.24 (OE#), U6.24 (OE#); also elsewhere on the board
~CPU_WR: U5.29 (WE#); also elsewhere on the board
~RAM_CE: U5.22 (CE#); also elsewhere on the board
~ROM_CE: U6.22 (CE#); also elsewhere on the board

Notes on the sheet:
ZIF32 socket

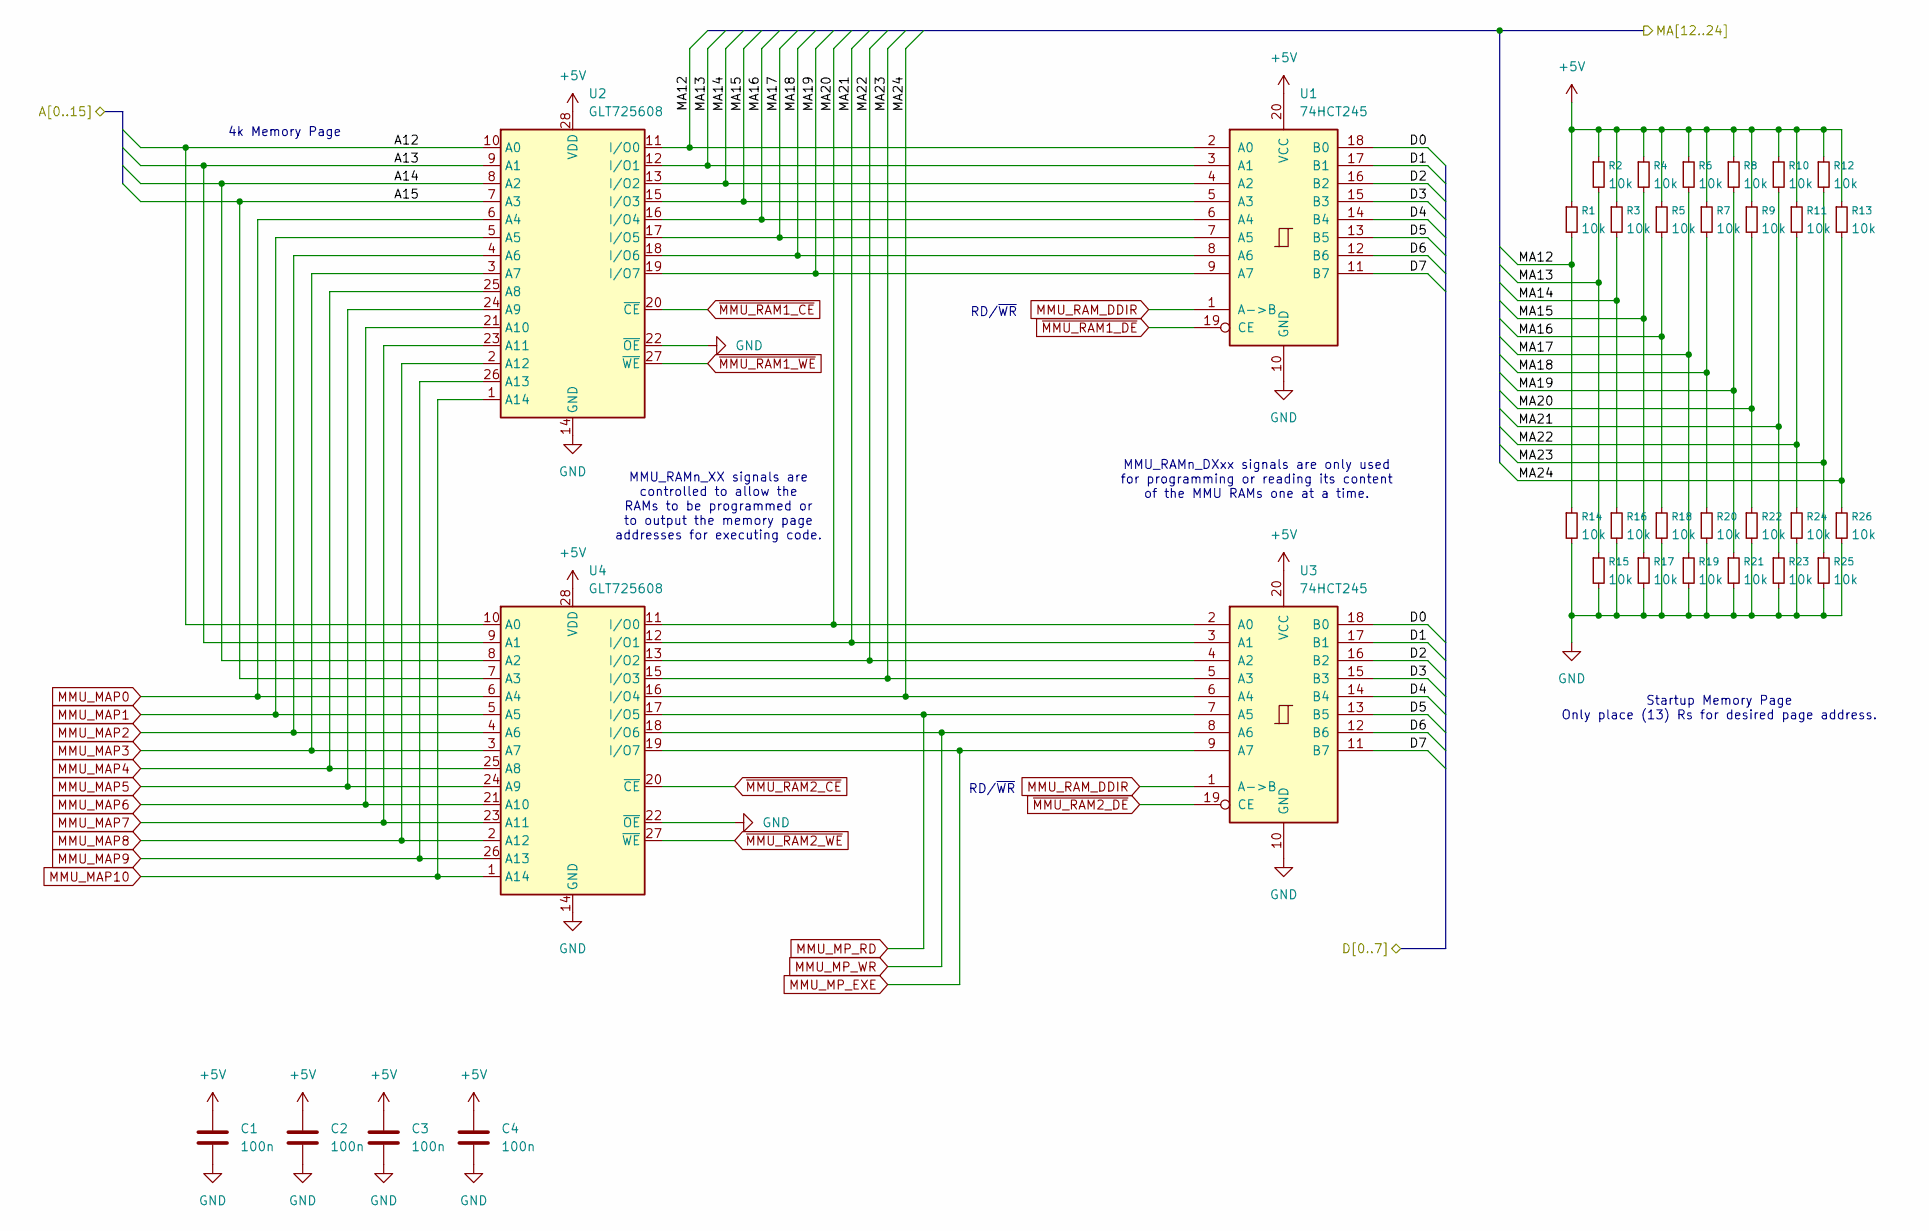
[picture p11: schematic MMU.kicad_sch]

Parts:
C1, C2, C3, C4: 100n; C_0603_1608Metric_Pad1.08x0.95mm_HandSolder
R1, R2, R3, R4, R5, R6, R7, R8, R9, R10, R11, R12, R13, R14, R15, R16, R17, R18, R19, R20, R21, R22, R23, R24, R25, R26: 10k; R_0603_1608Metric_Pad0.98x0.95mm_HandSolder
U1, U3: 74HCT245; DIP-20_W7.62mm_Socket_LongNarrowPads
U2, U4: GLT725608; SOJ-28_7.62x18.415mm_P1.27mm

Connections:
+5V: C1.1, C2.1, C3.1, C4.1, R1.1, R2.1, R3.1, R4.1, R5.1, R6.1, R7.1, R8.1, R9.1, R10.1, R11.1, R12.1, R13.1, U1.20 (VCC), U2.28 (VDD), U3.20 (VCC), U4.28 (VDD); also elsewhere on the board
/CPU/A12: U2.10 (A0), U4.10 (A0); also elsewhere on the board
/CPU/A13: U2.9 (A1), U4.9 (A1); also elsewhere on the board
/CPU/A14: U2.8 (A2), U4.8 (A2); also elsewhere on the board
/CPU/A15: U2.7 (A3), U4.7 (A3); also elsewhere on the board
/CPU/D0: U1.18 (B0), U3.18 (B0); also elsewhere on the board
/CPU/D1: U1.17 (B1), U3.17 (B1); also elsewhere on the board
/CPU/D2: U1.16 (B2), U3.16 (B2); also elsewhere on the board
/CPU/D3: U1.15 (B3), U3.15 (B3); also elsewhere on the board
/CPU/D4: U1.14 (B4), U3.14 (B4); also elsewhere on the board
/CPU/D5: U1.13 (B5), U3.13 (B5); also elsewhere on the board
/CPU/D6: U1.12 (B6), U3.12 (B6); also elsewhere on the board
/CPU/D7: U1.11 (B7), U3.11 (B7); also elsewhere on the board
/Control Logic/MA12: R1.2, R14.1, U1.2 (A0), U2.11 (I/O0); also elsewhere on the board
/Control Logic/MA13: R2.2, R15.1, U1.3 (A1), U2.12 (I/O1); also elsewhere on the board
/Control Logic/MA14: R3.2, R16.1, U1.4 (A2), U2.13 (I/O2); also elsewhere on the board
/Control Logic/MA15: R4.2, R17.1, U1.5 (A3), U2.15 (I/O3); also elsewhere on the board
/Control Logic/MA16: R5.2, R18.1, U1.6 (A4), U2.16 (I/O4); also elsewhere on the board
/Control Logic/MA17: R6.2, R19.1, U1.7 (A5), U2.17 (I/O5); also elsewhere on the board
/Control Logic/MA18: R7.2, R20.1, U1.8 (A6), U2.18 (I/O6); also elsewhere on the board
/Control Logic/MA19: R8.2, R21.1, U1.9 (A7), U2.19 (I/O7); also elsewhere on the board
/Control Logic/MA20: R9.2, R22.1, U3.2 (A0), U4.11 (I/O0); also elsewhere on the board
/Control Logic/MA21: R10.2, R23.1, U3.3 (A1), U4.12 (I/O1); also elsewhere on the board
/Control Logic/MA22: R11.2, R24.1, U3.4 (A2), U4.13 (I/O2); also elsewhere on the board
/Control Logic/MA23: R12.2, R25.1, U3.5 (A3), U4.15 (I/O3); also elsewhere on the board
/Control Logic/MA24: R13.2, R26.1, U3.6 (A4), U4.16 (I/O4); also elsewhere on the board
GND: C1.2, C2.2, C3.2, C4.2, R14.2, R15.2, R16.2, R17.2, R18.2, R19.2, R20.2, R21.2, R22.2, R23.2, R24.2, R25.2, R26.2, U1.10 (GND), U2.14 (GND), U2.22 (~OE), U3.10 (GND), U4.14 (GND), U4.22 (~OE); also elsewhere on the board
MMU_MAP0: U2.6 (A4), U4.6 (A4); also elsewhere on the board
MMU_MAP1: U2.5 (A5), U4.5 (A5); also elsewhere on the board
MMU_MAP2: U2.4 (A6), U4.4 (A6); also elsewhere on the board
MMU_MAP3: U2.3 (A7), U4.3 (A7); also elsewhere on the board
MMU_MAP4: U2.25 (A8), U4.25 (A8); also elsewhere on the board
MMU_MAP5: U2.24 (A9), U4.24 (A9); also elsewhere on the board
MMU_MAP6: U2.21 (A10), U4.21 (A10); also elsewhere on the board
MMU_MAP7: U2.23 (A11), U4.23 (A11); also elsewhere on the board
MMU_MAP8: U2.2 (A12), U4.2 (A12); also elsewhere on the board
MMU_MAP9: U2.26 (A13), U4.26 (A13); also elsewhere on the board
MMU_MAP10: U2.1 (A14), U4.1 (A14); also elsewhere on the board
MMU_MP_EXE: U3.9 (A7), U4.19 (I/O7); also elsewhere on the board
MMU_MP_RD: U3.7 (A5), U4.17 (I/O5); also elsewhere on the board
MMU_MP_WR: U3.8 (A6), U4.18 (I/O6); also elsewhere on the board
MMU_RAM_DDIR: U1.1 (A->B), U3.1 (A->B); also elsewhere on the board
~MMU_RAM1_CE: U2.20 (~CE); also elsewhere on the board
~MMU_RAM1_DE: U1.19 (CE); also elsewhere on the board
~MMU_RAM1_WE: U2.27 (~WE); also elsewhere on the board
~MMU_RAM2_CE: U4.20 (~CE); also elsewhere on the board
~MMU_RAM2_DE: U3.19 (CE); also elsewhere on the board
~MMU_RAM2_WE: U4.27 (~WE); also elsewhere on the board

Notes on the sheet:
RD/~{WR}
MMU_RAMn_DXxx signals are only used for programming or reading its content of the MMU RAMs one at a time.
MMU_RAMn_XX signals are controlled to allow the RAMs to be programmed or to output the memory page addresses for executing code.
4k Memory Page
Startup Memory Page Only place (13) Rs for desired page address.

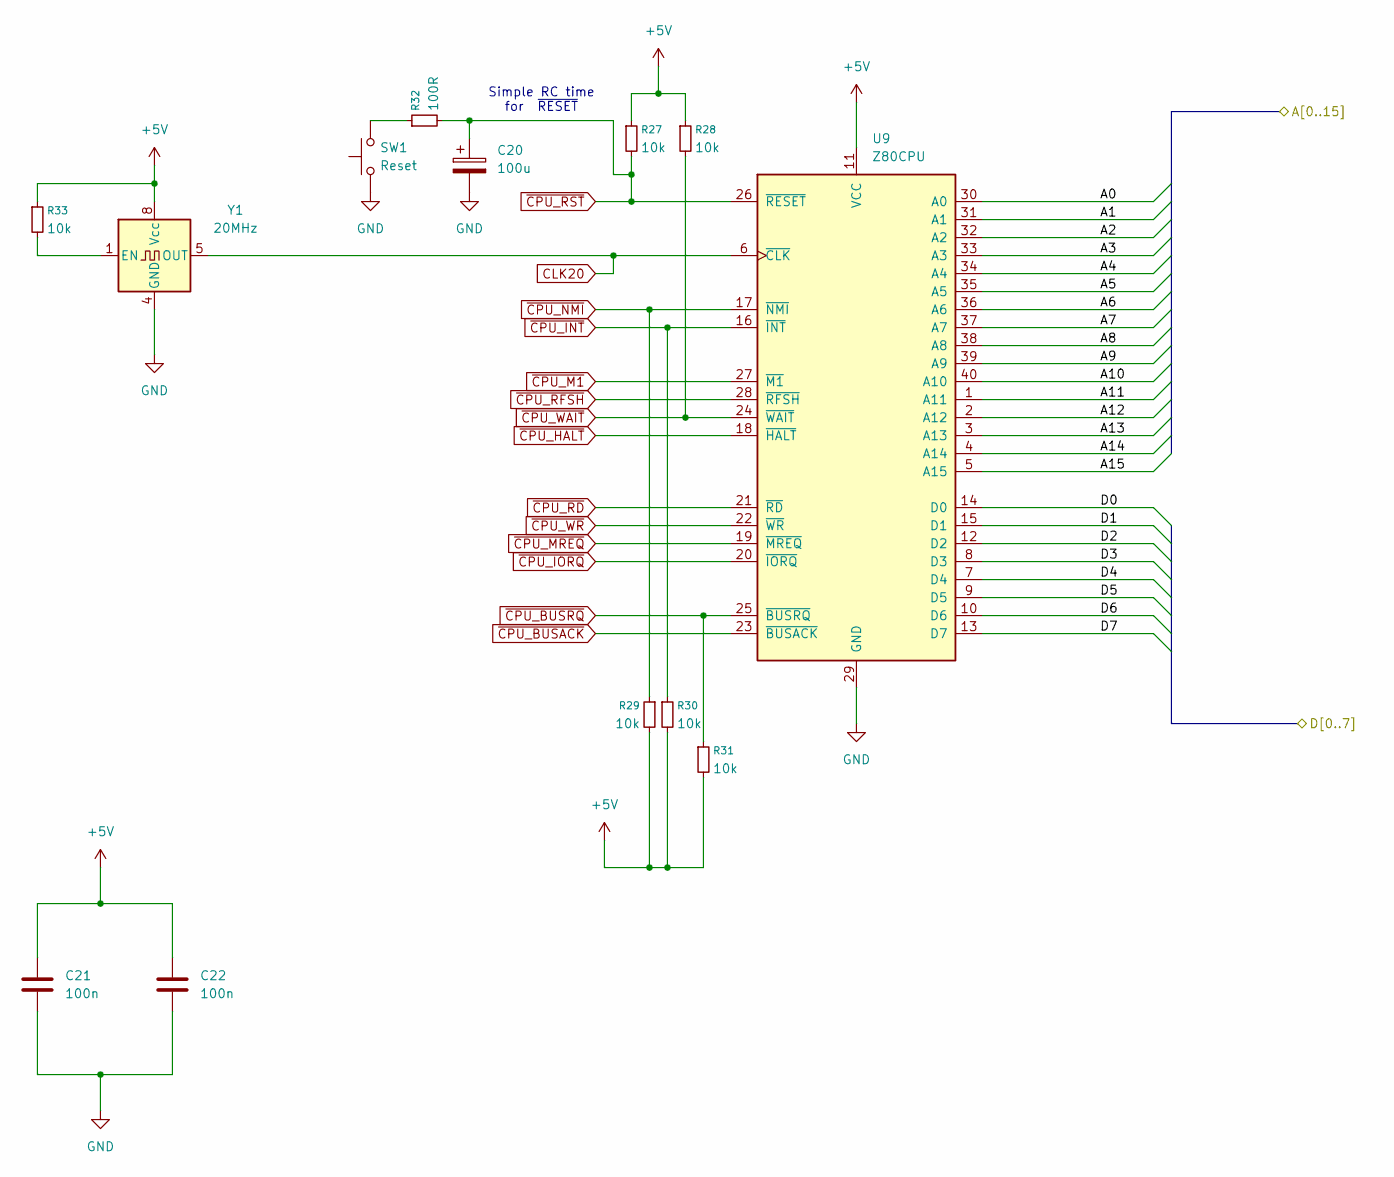
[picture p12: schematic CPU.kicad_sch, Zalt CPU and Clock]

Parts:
C20: 100u; CP_Radial_D8.0mm_P3.80mm
C21, C22: 100n; C_0603_1608Metric_Pad1.08x0.95mm_HandSolder
R27, R28, R29, R30, R31, R33: 10k; R_0603_1608Metric_Pad0.98x0.95mm_HandSolder
R32: 100R; R_0603_1608Metric_Pad0.98x0.95mm_HandSolder
SW1: Reset; SW_Tactile_SPST_Angled_PTS645Vx83-2LFS
U9: Z80CPU; 3M_Textool_240-1288-00-0602J_2x20_P2.54mm
Y1: 20MHz; Oscillator_DIP-8_LargePads

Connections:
+5V: C21.1, C22.1, R27.1, R28.1, R29.2, R30.2, R31.2, R33.1, U9.11 (VCC), Y1.8 (Vcc); also elsewhere on the board
/CPU/A0: U9.30 (A0); also elsewhere on the board
/CPU/A1: U9.31 (A1); also elsewhere on the board
/CPU/A2: U9.32 (A2); also elsewhere on the board
/CPU/A3: U9.33 (A3); also elsewhere on the board
/CPU/A4: U9.34 (A4); also elsewhere on the board
/CPU/A5: U9.35 (A5); also elsewhere on the board
/CPU/A6: U9.36 (A6); also elsewhere on the board
/CPU/A7: U9.37 (A7); also elsewhere on the board
/CPU/A8: U9.38 (A8); also elsewhere on the board
/CPU/A9: U9.39 (A9); also elsewhere on the board
/CPU/A10: U9.40 (A10); also elsewhere on the board
/CPU/A11: U9.1 (A11); also elsewhere on the board
/CPU/A12: U9.2 (A12); also elsewhere on the board
/CPU/A13: U9.3 (A13); also elsewhere on the board
/CPU/A14: U9.4 (A14); also elsewhere on the board
/CPU/A15: U9.5 (A15); also elsewhere on the board
/CPU/D0: U9.14 (D0); also elsewhere on the board
/CPU/D1: U9.15 (D1); also elsewhere on the board
/CPU/D2: U9.12 (D2); also elsewhere on the board
/CPU/D3: U9.8 (D3); also elsewhere on the board
/CPU/D4: U9.7 (D4); also elsewhere on the board
/CPU/D5: U9.9 (D5); also elsewhere on the board
/CPU/D6: U9.10 (D6); also elsewhere on the board
/CPU/D7: U9.13 (D7); also elsewhere on the board
CLK20: U9.6 (~CLK), Y1.5 (OUT); also elsewhere on the board
GND: C20.2, C21.2, C22.2, SW1.1, U9.29 (GND), Y1.4 (GND); also elsewhere on the board
unnamed: R32.1, SW1.2
unnamed: R33.2, Y1.1 (EN)
~CPU_BUSACK: U9.23 (~BUSACK); also elsewhere on the board
~CPU_BUSRQ: R31.1, U9.25 (~BUSRQ); also elsewhere on the board
~CPU_HALT: U9.18 (~HALT); also elsewhere on the board
~CPU_INT: R30.1, U9.16 (~INT); also elsewhere on the board
~CPU_IORQ: U9.20 (~IORQ); also elsewhere on the board
~CPU_M1: U9.27 (~M1); also elsewhere on the board
~CPU_MREQ: U9.19 (~MREQ); also elsewhere on the board
~CPU_NMI: R29.1, U9.17 (~NMI); also elsewhere on the board
~CPU_RD: U9.21 (~RD); also elsewhere on the board
~CPU_RFSH: U9.28 (~RFSH); also elsewhere on the board
~CPU_RST: C20.1, R27.2, R32.2, U9.26 (~RESET); also elsewhere on the board
~CPU_WAIT: R28.2, U9.24 (~WAIT); also elsewhere on the board
~CPU_WR: U9.22 (~WR); also elsewhere on the board

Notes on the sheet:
Simple RC time for ~{RESET}

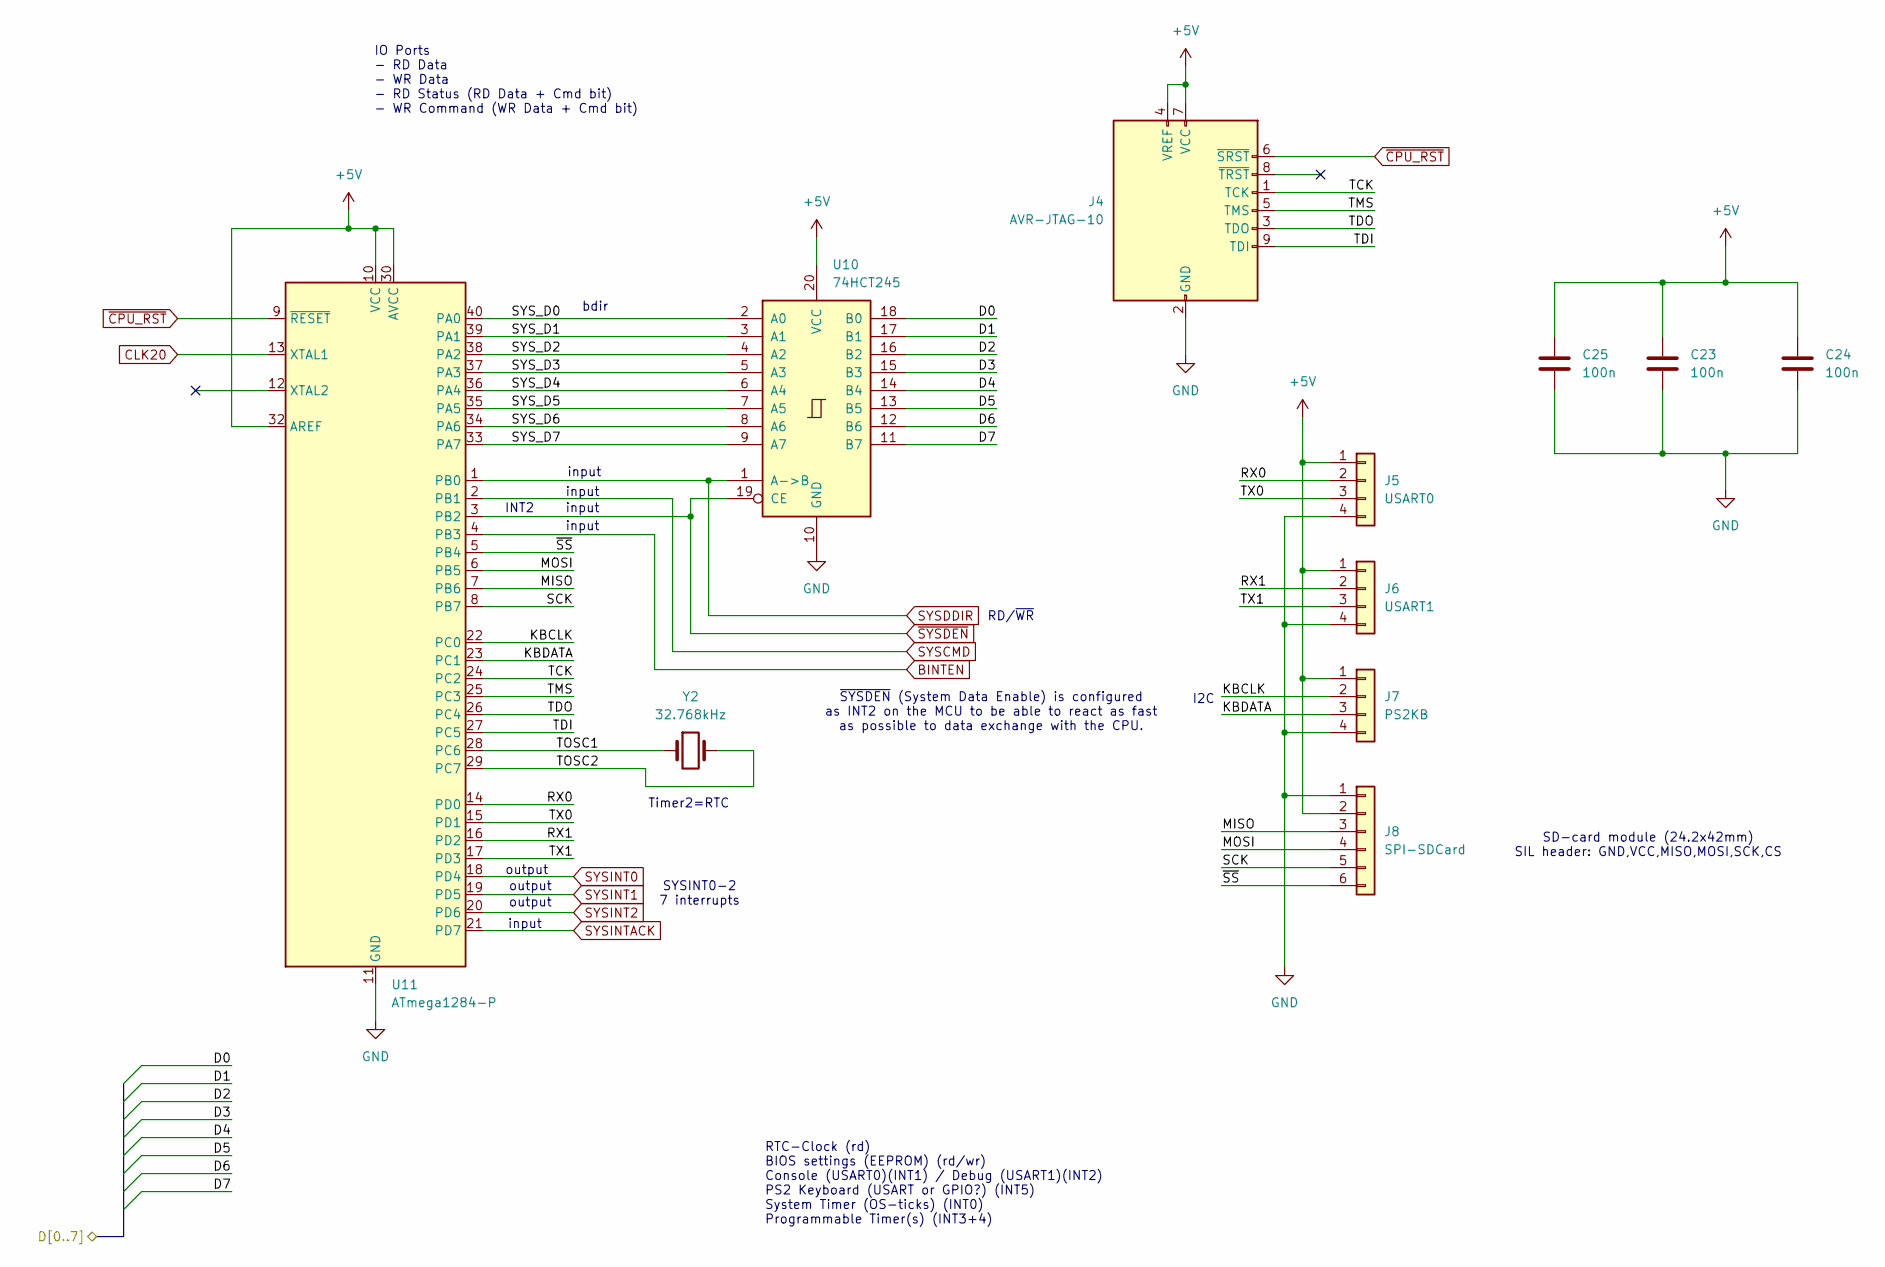
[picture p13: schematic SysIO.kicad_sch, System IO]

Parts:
C23, C24, C25: 100n; C_0603_1608Metric_Pad1.08x0.95mm_HandSolder
J4: AVR-JTAG-10; IDC-Header_2x05_P2.54mm_Vertical
J5: USART0; PinHeader_1x04_P2.54mm_Vertical
J6: USART1; PinHeader_1x04_P2.54mm_Vertical
J7: PS2KB; PinHeader_1x04_P2.54mm_Vertical
J8: SPI-SDCard; PinSocket_1x06_P2.54mm_Vertical
U10: 74HCT245; DIP-20_W7.62mm_Socket_LongNarrowPads
U11: ATmega1284-P; DIP-40_W15.24mm_Socket_LongPads
Y2: 32.768kHz; Crystal_C26-LF_D2.1mm_L6.5mm_Horizontal

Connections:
+5V: C23.1, C24.1, C25.1, J4.4 (VREF), J4.7 (VCC), J5.1, J6.1, J7.1, J8.2, U10.20 (VCC), U11.10 (VCC), U11.30 (AVCC), U11.32 (AREF); also elsewhere on the board
/CPU/D0: U10.18 (B0); also elsewhere on the board
/CPU/D1: U10.17 (B1); also elsewhere on the board
/CPU/D2: U10.16 (B2); also elsewhere on the board
/CPU/D3: U10.15 (B3); also elsewhere on the board
/CPU/D4: U10.14 (B4); also elsewhere on the board
/CPU/D5: U10.13 (B5); also elsewhere on the board
/CPU/D6: U10.12 (B6); also elsewhere on the board
/CPU/D7: U10.11 (B7); also elsewhere on the board
/SysIO/KBCLK: J7.2, U11.22 (PC0)
/SysIO/KBDATA: J7.3, U11.23 (PC1)
/SysIO/MISO: J8.3, U11.7 (PB6)
/SysIO/MOSI: J8.4, U11.6 (PB5)
/SysIO/RX0: J5.2, U11.14 (PD0)
/SysIO/RX1: J6.2, U11.16 (PD2)
/SysIO/SCK: J8.5, U11.8 (PB7)
/SysIO/SYS_D0: U10.2 (A0), U11.40 (PA0)
/SysIO/SYS_D1: U10.3 (A1), U11.39 (PA1)
/SysIO/SYS_D2: U10.4 (A2), U11.38 (PA2)
/SysIO/SYS_D3: U10.5 (A3), U11.37 (PA3)
/SysIO/SYS_D4: U10.6 (A4), U11.36 (PA4)
/SysIO/SYS_D5: U10.7 (A5), U11.35 (PA5)
/SysIO/SYS_D6: U10.8 (A6), U11.34 (PA6)
/SysIO/SYS_D7: U10.9 (A7), U11.33 (PA7)
/SysIO/TCK: J4.1 (TCK), U11.24 (PC2)
/SysIO/TDI: J4.9 (TDI), U11.27 (PC5)
/SysIO/TDO: J4.3 (TDO), U11.26 (PC4)
/SysIO/TMS: J4.5 (TMS), U11.25 (PC3)
/SysIO/TOSC1: U11.28 (PC6), Y2.1
/SysIO/TOSC2: U11.29 (PC7), Y2.2
/SysIO/TX0: J5.3, U11.15 (PD1)
/SysIO/TX1: J6.3, U11.17 (PD3)
/SysIO/~SS: J8.6, U11.5 (PB4)
BINTEN: U11.4 (PB3); also elsewhere on the board
CLK20: U11.13 (XTAL1); also elsewhere on the board
GND: C23.2, C24.2, C25.2, J4.2 (GND), J4.10 (GND), J5.4, J6.4, J7.4, J8.1, U10.10 (GND), U11.11 (GND), U11.31 (GND); also elsewhere on the board
SYSCMD: U11.2 (PB1); also elsewhere on the board
SYSDDIR: U10.1 (A->B), U11.1 (PB0); also elsewhere on the board
SYSINT0: U11.18 (PD4); also elsewhere on the board
SYSINT1: U11.19 (PD5); also elsewhere on the board
SYSINT2: U11.20 (PD6); also elsewhere on the board
SYSINTACK: U11.21 (PD7); also elsewhere on the board
~CPU_RST: J4.6 (~SRST), U11.9 (~RESET); also elsewhere on the board
~SYSDEN: U10.19 (CE), U11.3 (PB2); also elsewhere on the board

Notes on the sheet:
IO Ports - RD Data - WR Data - RD Status (RD Data + Cmd bit) - WR Command (WR Data + Cmd bit)
output
RTC-Clock (rd) BIOS settings (EEPROM) (rd/wr) Console (USART0)(INT1) / Debug (USART1)(INT2) PS2 Keyboard (USART or GPIO?) (INT5) System Timer (OS-ticks) (INT0) Programmable Timer(s) (INT3+4)
input
bdir
SYSINT0-2 7 interrupts
~{SYSDEN} (System Data Enable) is configured as INT2 on the MCU to be able to react as fast as possible to data exchange with the CPU.
I2C
Timer2=RTC
INT2
SD-card module (24.2x42mm) SIL header: GND,VCC,MISO,MOSI,SCK,CS
RD/~{WR}

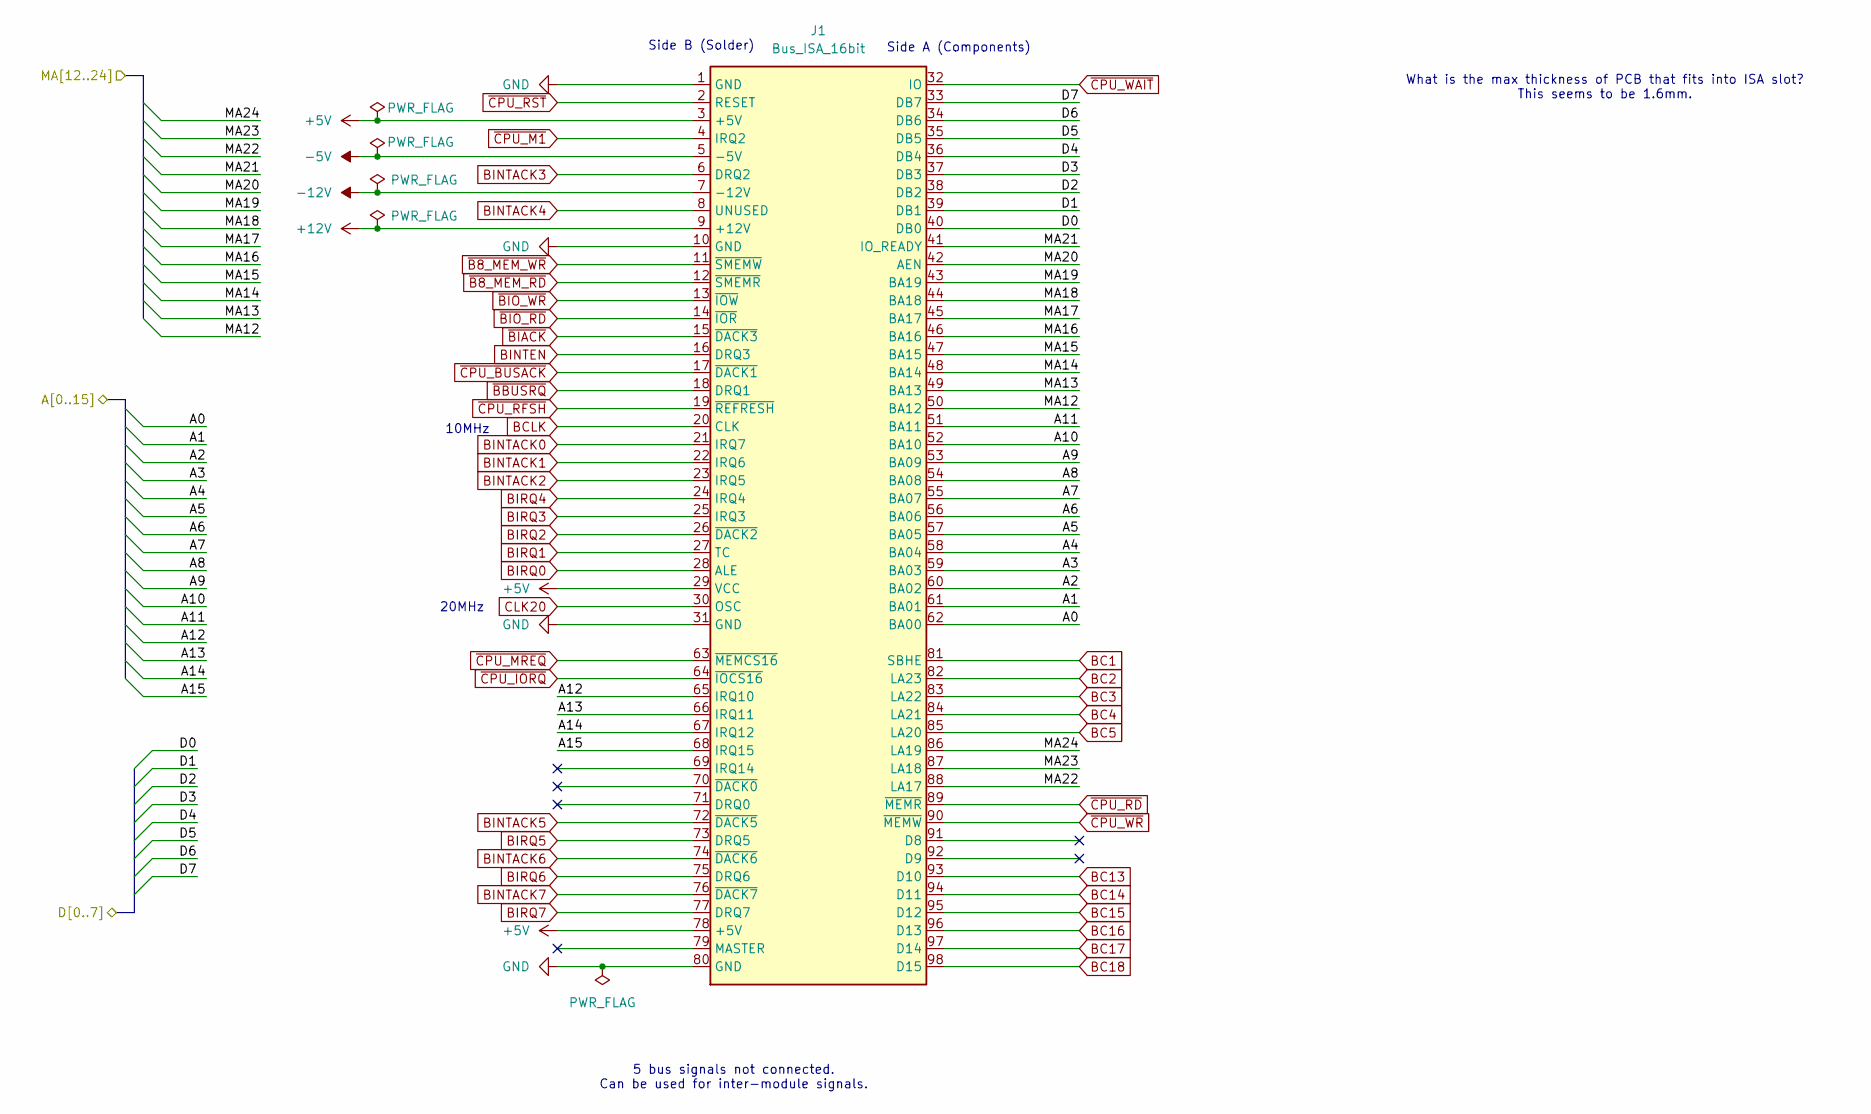
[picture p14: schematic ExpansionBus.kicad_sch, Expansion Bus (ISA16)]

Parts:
J1: Bus_ISA_16bit; BUS_AT

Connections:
+5V: J1.3 (+5V), J1.29 (VCC), J1.78 (+5V); also elsewhere on the board
+12V: J1.9 (+12V)
-5V: J1.5 (-5V)
-12V: J1.7 (-12V)
/CPU/A0: J1.62 (BA00); also elsewhere on the board
/CPU/A1: J1.61 (BA01); also elsewhere on the board
/CPU/A2: J1.60 (BA02); also elsewhere on the board
/CPU/A3: J1.59 (BA03); also elsewhere on the board
/CPU/A4: J1.58 (BA04); also elsewhere on the board
/CPU/A5: J1.57 (BA05); also elsewhere on the board
/CPU/A6: J1.56 (BA06); also elsewhere on the board
/CPU/A7: J1.55 (BA07); also elsewhere on the board
/CPU/A8: J1.54 (BA08); also elsewhere on the board
/CPU/A9: J1.53 (BA09); also elsewhere on the board
/CPU/A10: J1.52 (BA10); also elsewhere on the board
/CPU/A11: J1.51 (BA11); also elsewhere on the board
/CPU/A12: J1.65 (IRQ10); also elsewhere on the board
/CPU/A13: J1.66 (IRQ11); also elsewhere on the board
/CPU/A14: J1.67 (IRQ12); also elsewhere on the board
/CPU/A15: J1.68 (IRQ15); also elsewhere on the board
/CPU/D0: J1.40 (DB0); also elsewhere on the board
/CPU/D1: J1.39 (DB1); also elsewhere on the board
/CPU/D2: J1.38 (DB2); also elsewhere on the board
/CPU/D3: J1.37 (DB3); also elsewhere on the board
/CPU/D4: J1.36 (DB4); also elsewhere on the board
/CPU/D5: J1.35 (DB5); also elsewhere on the board
/CPU/D6: J1.34 (DB6); also elsewhere on the board
/CPU/D7: J1.33 (DB7); also elsewhere on the board
/Control Logic/MA12: J1.50 (BA12); also elsewhere on the board
/Control Logic/MA13: J1.49 (BA13); also elsewhere on the board
/Control Logic/MA14: J1.48 (BA14); also elsewhere on the board
/Control Logic/MA15: J1.47 (BA15); also elsewhere on the board
/Control Logic/MA16: J1.46 (BA16); also elsewhere on the board
/Control Logic/MA17: J1.45 (BA17); also elsewhere on the board
/Control Logic/MA18: J1.44 (BA18); also elsewhere on the board
/Control Logic/MA19: J1.43 (BA19); also elsewhere on the board
/Control Logic/MA20: J1.42 (AEN); also elsewhere on the board
/Control Logic/MA21: J1.41 (IO_READY); also elsewhere on the board
/Control Logic/MA22: J1.88 (LA17); also elsewhere on the board
/Control Logic/MA23: J1.87 (LA18); also elsewhere on the board
/Control Logic/MA24: J1.86 (LA19); also elsewhere on the board
BC1: J1.81 (SBHE); also elsewhere on the board
BC2: J1.82 (LA23); also elsewhere on the board
BC3: J1.83 (LA22); also elsewhere on the board
BC4: J1.84 (LA21); also elsewhere on the board
BC5: J1.85 (LA20); also elsewhere on the board
BC13: J1.93 (D10); also elsewhere on the board
BC14: J1.94 (D11); also elsewhere on the board
BC15: J1.95 (D12); also elsewhere on the board
BC16: J1.96 (D13); also elsewhere on the board
BC17: J1.97 (D14); also elsewhere on the board
BC18: J1.98 (D15); also elsewhere on the board
BCLK: J1.20 (CLK); also elsewhere on the board
BINTACK0: J1.21 (IRQ7); also elsewhere on the board
BINTACK1: J1.22 (IRQ6); also elsewhere on the board
BINTACK2: J1.23 (IRQ5); also elsewhere on the board
BINTACK3: J1.6 (DRQ2); also elsewhere on the board
BINTACK4: J1.8 (UNUSED); also elsewhere on the board
BINTACK5: J1.72 (~DACK5); also elsewhere on the board
BINTACK6: J1.74 (~DACK6); also elsewhere on the board
BINTACK7: J1.76 (~DACK7); also elsewhere on the board
BINTEN: J1.16 (DRQ3); also elsewhere on the board
BIRQ0: J1.28 (ALE); also elsewhere on the board
BIRQ1: J1.27 (TC); also elsewhere on the board
BIRQ2: J1.26 (~DACK2); also elsewhere on the board
BIRQ3: J1.25 (IRQ3); also elsewhere on the board
BIRQ4: J1.24 (IRQ4); also elsewhere on the board
BIRQ5: J1.73 (DRQ5); also elsewhere on the board
BIRQ6: J1.75 (DRQ6); also elsewhere on the board
BIRQ7: J1.77 (DRQ7); also elsewhere on the board
CLK20: J1.30 (OSC); also elsewhere on the board
GND: J1.1 (GND), J1.10 (GND), J1.31 (GND), J1.80 (GND); also elsewhere on the board
~B8_MEM_RD: J1.12 (~SMEMR); also elsewhere on the board
~B8_MEM_WR: J1.11 (~SMEMW); also elsewhere on the board
~BBUSRQ: J1.18 (DRQ1); also elsewhere on the board
~BIACK: J1.15 (~DACK3); also elsewhere on the board
~BIO_RD: J1.14 (~IOR); also elsewhere on the board
~BIO_WR: J1.13 (~IOW); also elsewhere on the board
~CPU_BUSACK: J1.17 (~DACK1); also elsewhere on the board
~CPU_IORQ: J1.64 (~IOCS16); also elsewhere on the board
~CPU_M1: J1.4 (IRQ2); also elsewhere on the board
~CPU_MREQ: J1.63 (~MEMCS16); also elsewhere on the board
~CPU_RD: J1.89 (~MEMR); also elsewhere on the board
~CPU_RFSH: J1.19 (~REFRESH); also elsewhere on the board
~CPU_RST: J1.2 (RESET); also elsewhere on the board
~CPU_WAIT: J1.32 (IO); also elsewhere on the board
~CPU_WR: J1.90 (~MEMW); also elsewhere on the board

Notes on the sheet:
Side B (Solder)
5 bus signals not connected. Can be used for inter-module signals.
Side A (Components)
What is the max thickness of PCB that fits into ISA slot? This seems to be 1.6mm.
20MHz
10MHz

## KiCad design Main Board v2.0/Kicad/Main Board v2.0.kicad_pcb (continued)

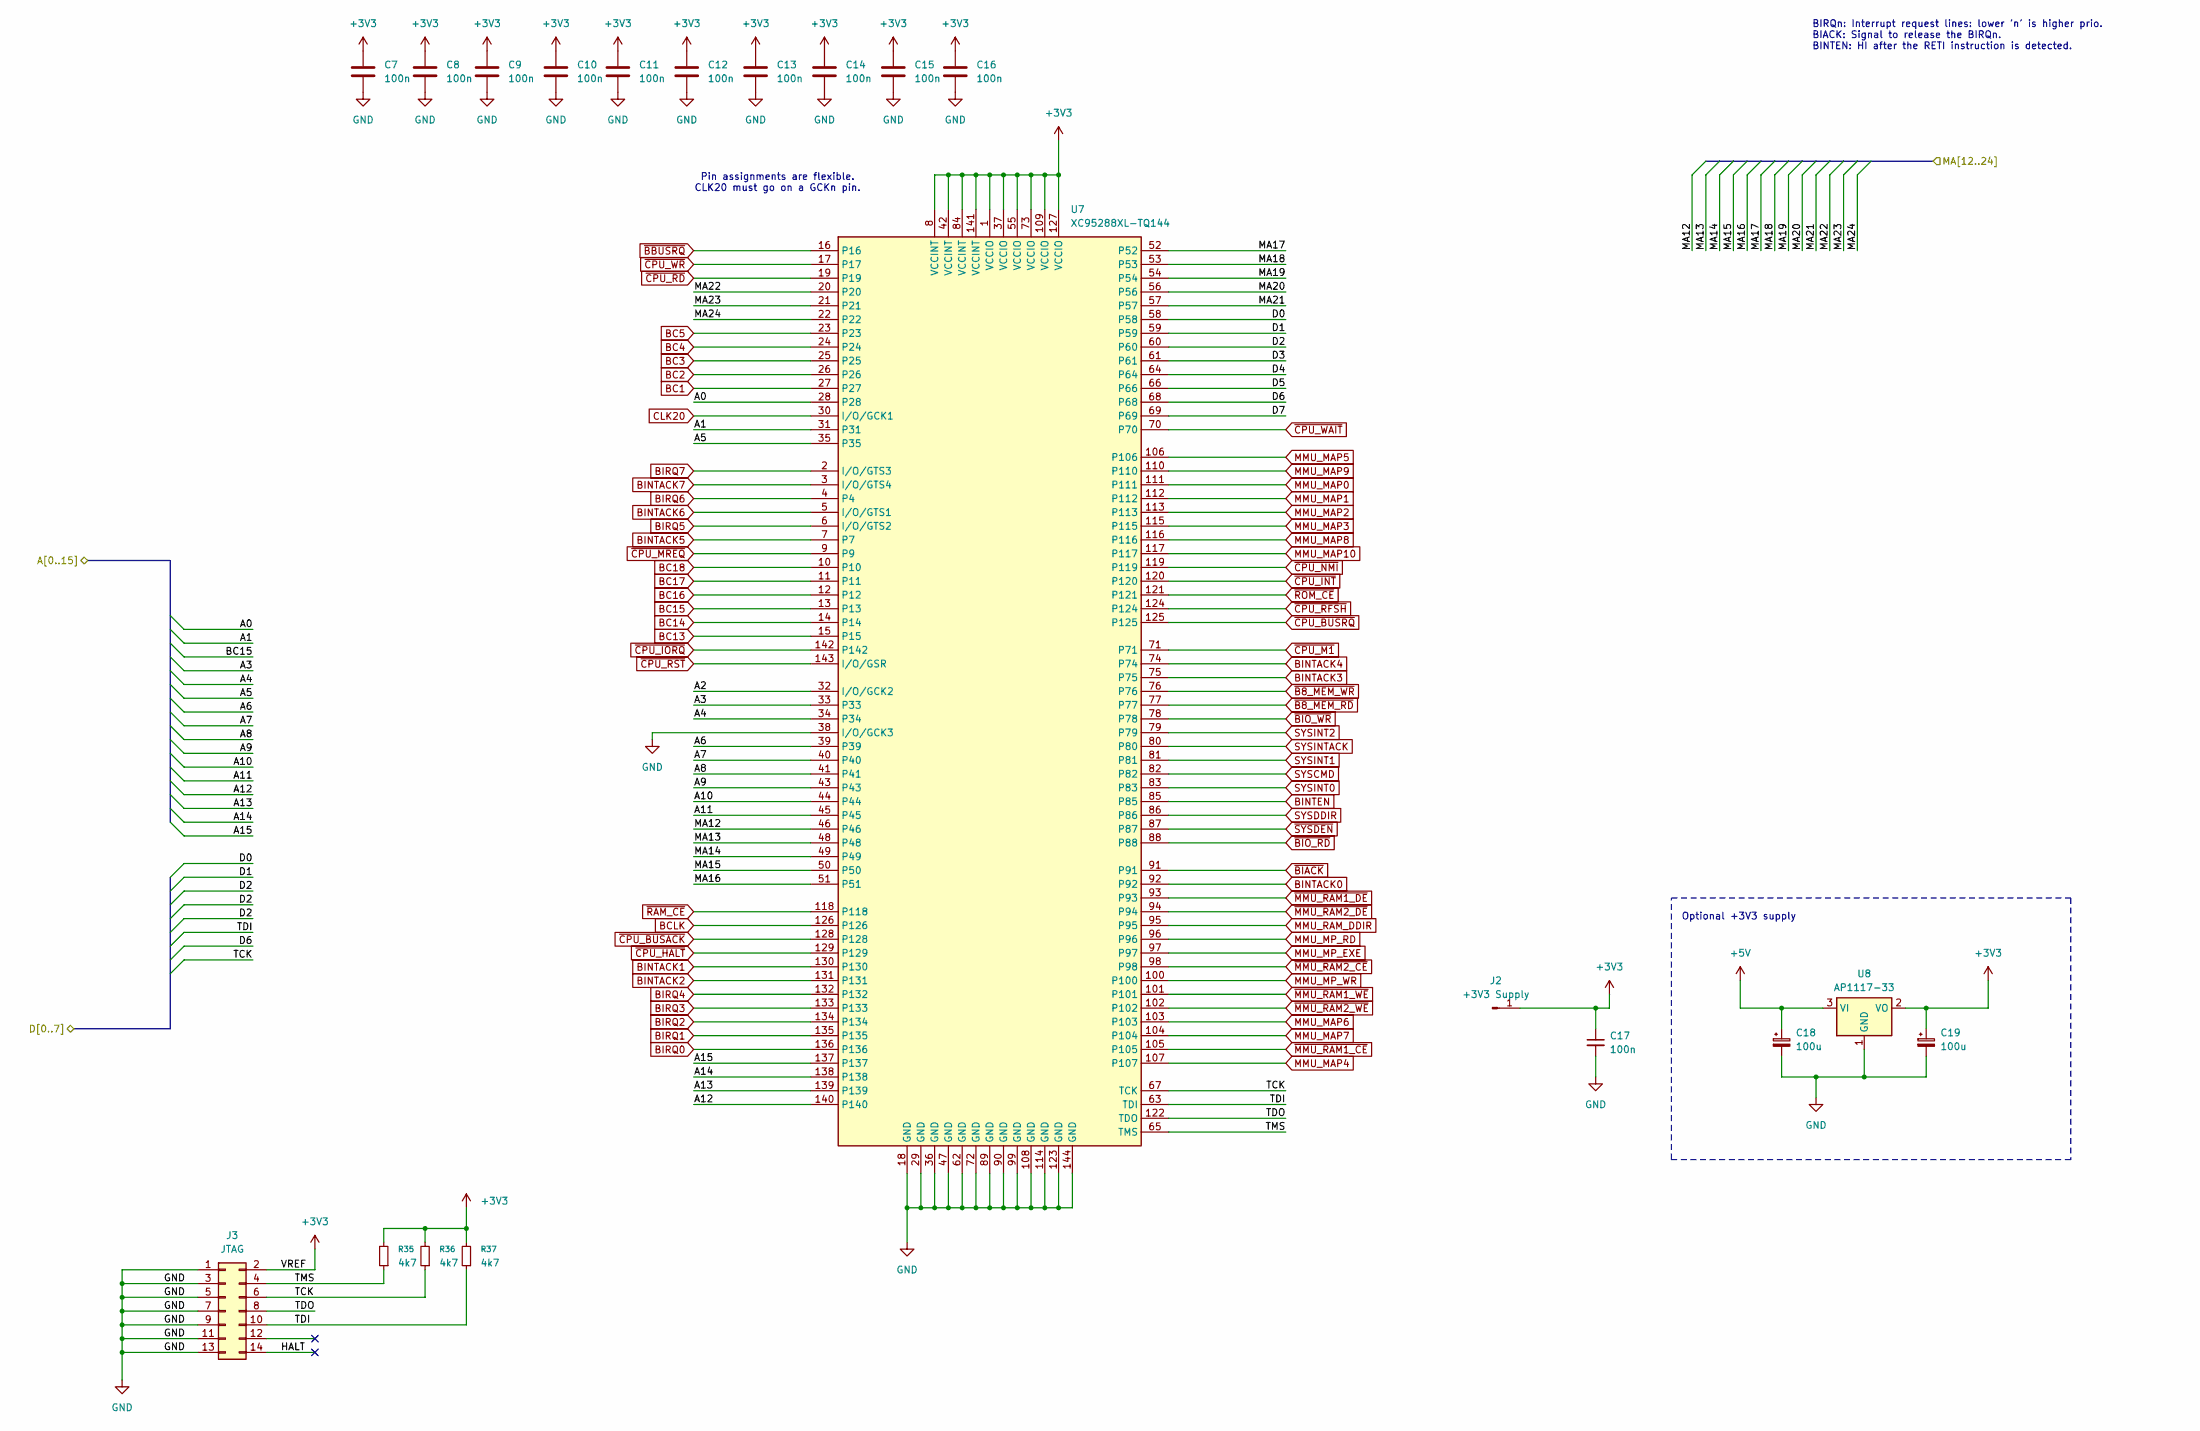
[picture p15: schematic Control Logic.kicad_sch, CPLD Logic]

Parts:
C7, C8, C9, C10, C11, C12, C13, C14, C15, C16, C17: 100n; C_0603_1608Metric_Pad1.08x0.95mm_HandSolder
C18, C19: 100u; CP_Radial_D8.0mm_P3.80mm
J2: +3V3 Supply; PinHeader_1x01_P2.54mm_Vertical
J3: JTAG; IDC-Header_2x07_P2.54mm_Vertical
R35, R36, R37: 4k7; R_0603_1608Metric_Pad0.98x0.95mm_HandSolder
U7: XC95288XL-TQ144; TQFP-144_20x20mm_P0.5mm
U8: AP1117-33; SOT-223-3_TabPin2

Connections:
+3V3: C7.1, C8.1, C9.1, C10.1, C11.1, C12.1, C13.1, C14.1, C15.1, C16.1, C17.1, C19.1, J2.1 (Pin_1_1), J3.2, R35.2, R36.2, R37.2, U7.1 (VCCIO), U7.8 (VCCINT), U7.37 (VCCIO), U7.42 (VCCINT), U7.55 (VCCIO), U7.73 (VCCIO), U7.84 (VCCINT), U7.109 (VCCIO), U7.127 (VCCIO), U7.141 (VCCINT), U8.2 (VO)
+5V: C18.1, U8.3 (VI); also elsewhere on the board
/CPU/A0: U7.28; also elsewhere on the board
/CPU/A1: U7.31; also elsewhere on the board
/CPU/A2: U7.32 (I/O/GCK2); also elsewhere on the board
/CPU/A3: U7.33; also elsewhere on the board
/CPU/A4: U7.34; also elsewhere on the board
/CPU/A5: U7.35; also elsewhere on the board
/CPU/A6: U7.39; also elsewhere on the board
/CPU/A7: U7.40; also elsewhere on the board
/CPU/A8: U7.41; also elsewhere on the board
/CPU/A9: U7.43; also elsewhere on the board
/CPU/A10: U7.44; also elsewhere on the board
/CPU/A11: U7.45; also elsewhere on the board
/CPU/A12: U7.140; also elsewhere on the board
/CPU/A13: U7.139; also elsewhere on the board
/CPU/A14: U7.138; also elsewhere on the board
/CPU/A15: U7.137; also elsewhere on the board
/CPU/D0: U7.58; also elsewhere on the board
/CPU/D1: U7.59; also elsewhere on the board
/CPU/D2: U7.60; also elsewhere on the board
/CPU/D3: U7.61; also elsewhere on the board
/CPU/D4: U7.64; also elsewhere on the board
/CPU/D5: U7.66; also elsewhere on the board
/CPU/D6: U7.68; also elsewhere on the board
/CPU/D7: U7.69; also elsewhere on the board
/Control Logic/HALT: J3.14
/Control Logic/MA12: U7.46; also elsewhere on the board
/Control Logic/MA13: U7.48; also elsewhere on the board
/Control Logic/MA14: U7.49; also elsewhere on the board
/Control Logic/MA15: U7.50; also elsewhere on the board
/Control Logic/MA16: U7.51; also elsewhere on the board
/Control Logic/MA17: U7.52; also elsewhere on the board
/Control Logic/MA18: U7.53; also elsewhere on the board
/Control Logic/MA19: U7.54; also elsewhere on the board
/Control Logic/MA20: U7.56; also elsewhere on the board
/Control Logic/MA21: U7.57; also elsewhere on the board
/Control Logic/MA22: U7.20; also elsewhere on the board
/Control Logic/MA23: U7.21; also elsewhere on the board
/Control Logic/MA24: U7.22; also elsewhere on the board
/Control Logic/TCK: J3.6, R36.1, U7.67 (TCK)
/Control Logic/TDI: J3.10, R37.1, U7.63 (TDI)
/Control Logic/TDO: J3.8, U7.122 (TDO)
/Control Logic/TMS: J3.4, R35.1, U7.65 (TMS)
BC1: U7.27; also elsewhere on the board
BC2: U7.26; also elsewhere on the board
BC3: U7.25; also elsewhere on the board
BC4: U7.24; also elsewhere on the board
BC5: U7.23; also elsewhere on the board
BC13: U7.15; also elsewhere on the board
BC14: U7.14; also elsewhere on the board
BC15: U7.13; also elsewhere on the board
BC16: U7.12; also elsewhere on the board
BC17: U7.11; also elsewhere on the board
BC18: U7.10; also elsewhere on the board
BCLK: U7.126; also elsewhere on the board
BINTACK0: U7.92; also elsewhere on the board
BINTACK1: U7.130; also elsewhere on the board
BINTACK2: U7.131; also elsewhere on the board
BINTACK3: U7.75; also elsewhere on the board
BINTACK4: U7.74; also elsewhere on the board
BINTACK5: U7.7; also elsewhere on the board
BINTACK6: U7.5 (I/O/GTS1); also elsewhere on the board
BINTACK7: U7.3 (I/O/GTS4); also elsewhere on the board
BINTEN: U7.85; also elsewhere on the board
BIRQ0: U7.136; also elsewhere on the board
BIRQ1: U7.135; also elsewhere on the board
BIRQ2: U7.134; also elsewhere on the board
BIRQ3: U7.133; also elsewhere on the board
BIRQ4: U7.132; also elsewhere on the board
BIRQ5: U7.6 (I/O/GTS2); also elsewhere on the board
BIRQ6: U7.4; also elsewhere on the board
BIRQ7: U7.2 (I/O/GTS3); also elsewhere on the board
CLK20: U7.30 (I/O/GCK1); also elsewhere on the board
GND: C7.2, C8.2, C9.2, C10.2, C11.2, C12.2, C13.2, C14.2, C15.2, C16.2, C17.2, C18.2, C19.2, J3.1, J3.3, J3.5, J3.7, J3.9, J3.11, J3.13, U7.18 (GND), U7.29 (GND), U7.36 (GND), U7.38 (I/O/GCK3), U7.47 (GND), U7.62 (GND), U7.72 (GND), U7.89 (GND), U7.90 (GND), U7.99 (GND), U7.108 (GND), U7.114 (GND), U7.123 (GND), U7.144 (GND), U8.1 (GND); also elsewhere on the board
MMU_MAP0: U7.111; also elsewhere on the board
MMU_MAP1: U7.112; also elsewhere on the board
MMU_MAP2: U7.113; also elsewhere on the board
MMU_MAP3: U7.115; also elsewhere on the board
MMU_MAP4: U7.107; also elsewhere on the board
MMU_MAP5: U7.106; also elsewhere on the board
MMU_MAP6: U7.103; also elsewhere on the board
MMU_MAP7: U7.104; also elsewhere on the board
MMU_MAP8: U7.116; also elsewhere on the board
MMU_MAP9: U7.110; also elsewhere on the board
MMU_MAP10: U7.117; also elsewhere on the board
MMU_MP_EXE: U7.97; also elsewhere on the board
MMU_MP_RD: U7.96; also elsewhere on the board
MMU_MP_WR: U7.100; also elsewhere on the board
MMU_RAM_DDIR: U7.95; also elsewhere on the board
SYSCMD: U7.82; also elsewhere on the board
SYSDDIR: U7.86; also elsewhere on the board
SYSINT0: U7.83; also elsewhere on the board
SYSINT1: U7.81; also elsewhere on the board
SYSINT2: U7.79; also elsewhere on the board
SYSINTACK: U7.80; also elsewhere on the board
~B8_MEM_RD: U7.77; also elsewhere on the board
~B8_MEM_WR: U7.76; also elsewhere on the board
~BBUSRQ: U7.16; also elsewhere on the board
~BIACK: U7.91; also elsewhere on the board
~BIO_RD: U7.88; also elsewhere on the board
~BIO_WR: U7.78; also elsewhere on the board
~CPU_BUSACK: U7.128; also elsewhere on the board
~CPU_BUSRQ: U7.125; also elsewhere on the board
~CPU_HALT: U7.129; also elsewhere on the board
~CPU_INT: U7.120; also elsewhere on the board
~CPU_IORQ: U7.142; also elsewhere on the board
~CPU_M1: U7.71; also elsewhere on the board
~CPU_MREQ: U7.9; also elsewhere on the board
~CPU_NMI: U7.119; also elsewhere on the board
~CPU_RD: U7.19; also elsewhere on the board
~CPU_RFSH: U7.124; also elsewhere on the board
~CPU_RST: U7.143 (I/O/GSR); also elsewhere on the board
~CPU_WAIT: U7.70; also elsewhere on the board
~CPU_WR: U7.17; also elsewhere on the board
~MMU_RAM1_CE: U7.105; also elsewhere on the board
~MMU_RAM1_DE: U7.93; also elsewhere on the board
~MMU_RAM1_WE: U7.101; also elsewhere on the board
~MMU_RAM2_CE: U7.98; also elsewhere on the board
~MMU_RAM2_DE: U7.94; also elsewhere on the board
~MMU_RAM2_WE: U7.102; also elsewhere on the board
~RAM_CE: U7.118; also elsewhere on the board
~ROM_CE: U7.121; also elsewhere on the board
~SYSDEN: U7.87; also elsewhere on the board

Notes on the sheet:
Optional +3V3 supply
Pin assignments are flexible. CLK20 must go on a GCKn pin.
BIRQn: Interrupt request lines: lower 'n' is higher prio. BIACK: Signal to release the BIRQn. BINTEN: HI after the RETI instruction is detected.

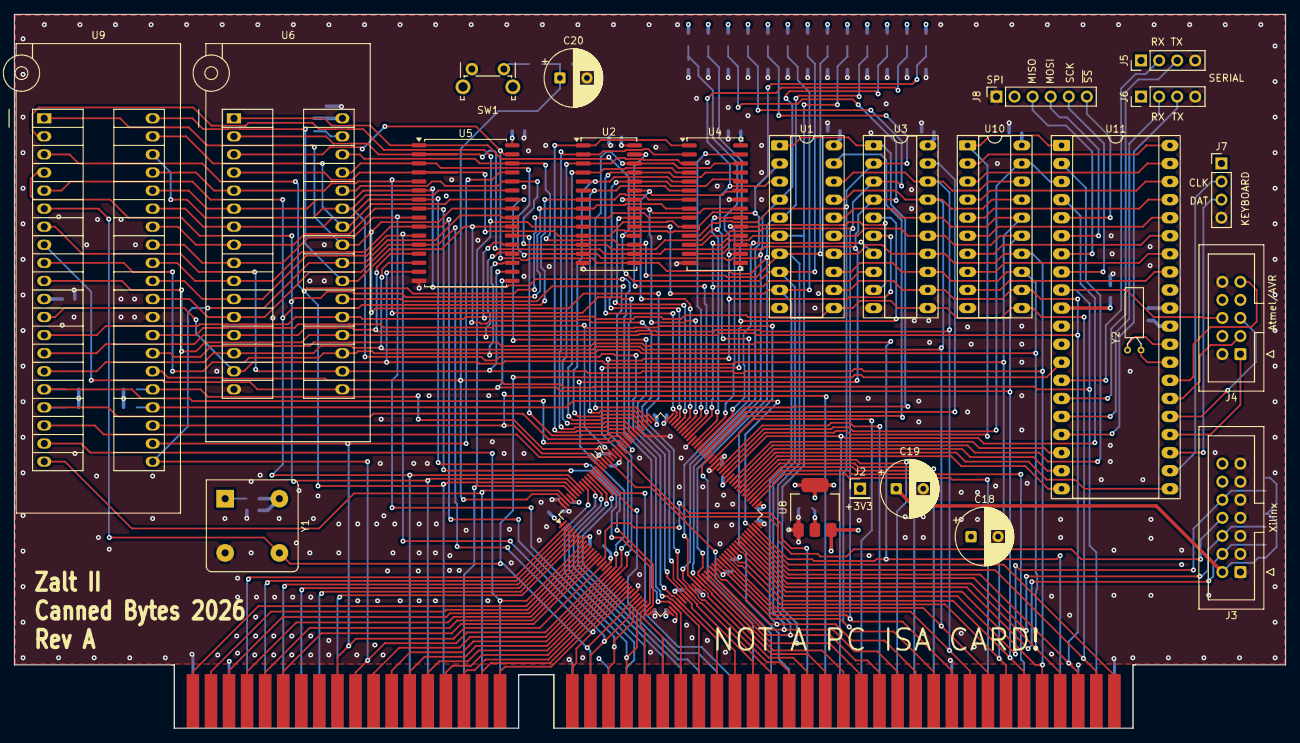
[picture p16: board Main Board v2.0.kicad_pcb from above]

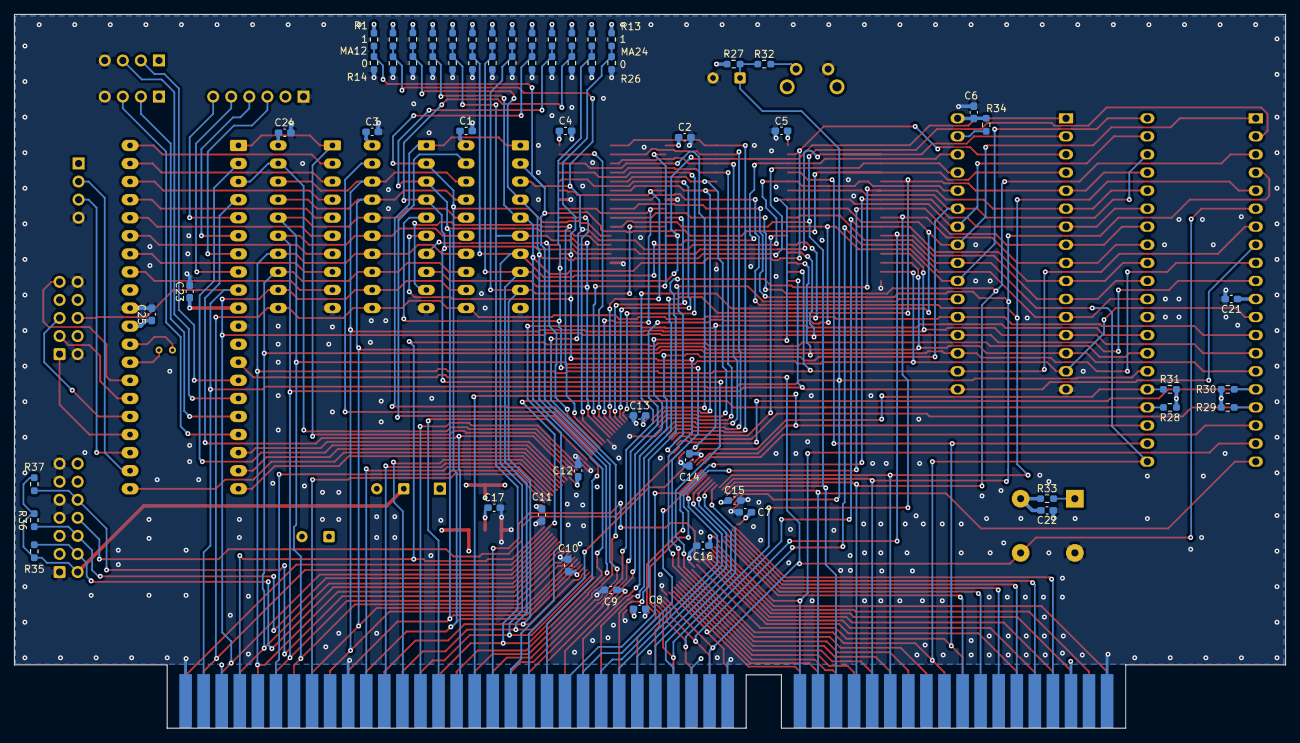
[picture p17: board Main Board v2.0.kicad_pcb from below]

Board: 4 copper layers, 178.7 x 100.3 mm, 84 parts (59 on the bottom side), 150 nets.

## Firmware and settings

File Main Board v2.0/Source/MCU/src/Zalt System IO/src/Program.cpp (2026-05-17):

// comment out to disable debug output
#define DEBUG
#include "Debug.h"

#include "DataPort.h"
#include "Program.h"
#include "Serial.h"
#include "StringUtils.h"

#include "RtcCommandHandler.cpp"
#include "ConsoleCommandHandler.cpp"

class Program
{
public:
    static const uint8_t ProgramComponentId = 0x10;

    Program()
        : _prevCommand(DataCommands::None), _currentCommandHandler(nullptr),
          _rtcCommandHandler(_dataPort), _consoleCommandHandler(_dataPort, _userConsole, _debugConsole)
          
    {}

    void Initialize()
    {
        // Start the timer that powers Time<TimeResolution> / Scheduler
        Scheduler::Start();

        // open console port (usart)
        if (!_userConsole.Open(BaudRates::Baud115200))
            Stop(1);

        if (!_debugConsole.Open(BaudRates::Baud115200))
            Stop(2);
    }

    void Run()
    {
        DataCommands command = _dataPort.getCommand();
        if (_prevCommand != command)
        {
            _currentCommandHandler = nullptr;
            _prevCommand = command;
            Information("Received command: ", (uint8_t)command);

            if (_rtcCommandHandler.HandleCommand(command))
            {
                _currentCommandHandler = &_rtcCommandHandler;
            }
            else if (_consoleCommandHandler.HandleCommand(command))
            {
                _currentCommandHandler = &_consoleCommandHandler;
            }
            else
            {
                Warning("Unhandled command: ", (uint8_t)command);
            }
        }

        if (_currentCommandHandler)
        {
            if (_currentCommandHandler->Run())
            {
                Information("Completed command: ", (uint8_t)command);
                _currentCommandHandler = nullptr;
            }
        }
    }

    void Stop(uint8_t code)
    {
        // Don't use Debug-logging, for it can be turned off.

        if (code > 2)
        {
            _debugConsole.Transmit.WriteLine("CRITICAL: MCU stopped:" + code);
        }
        else if (code > 1)
        {
            _userConsole.Transmit.WriteLine("CRITICAL: Failed to open debug console.");
        }
        else
        {
            // TODO: blink the SPI-SS pin as a last resort
        }

        while (true);
    }

//private:
    UserConsole _userConsole;
    DebugConsole _debugConsole;
    DataPort _dataPort;

private:
    DataCommands _prevCommand;
    CommandHandler* _currentCommandHandler;
    RtcCommandHandler _rtcCommandHandler;
    ConsoleCommandHandler _consoleCommandHandler;

    template <typename T>
    void Information(const char* message, T value)
    {
        if (Debug<ProgramComponentId>::CanLog<DebugLevel::Info>())
        {
            StringWriter<42> str;
            str.Write(message);
            str.Write(value);
            LogInfo<ProgramComponentId>(str);
        }
    }

    template <typename T>
    void Warning(const char* message, T value)
    {
        if (Debug<ProgramComponentId>::CanLog<DebugLevel::Warning>())
        {
            StringWriter<42> str;
            str.Write(message);
            str.Write(value);
            LogWarning<ProgramComponentId>(str);
        }
    }
};

Program program;

int main()
{
    program.Initialize();

    while (true) {
        program.Run();
    }

    return 0;
}

// user console
ISR(USART0_RX_vect)
{
    program._userConsole.Receive.OnIsCompleteInterrupt();
}

ISR(USART0_UDRE_vect)
{
    program._userConsole.Transmit.OnAcceptDataInterrupt();
}

// debug console
ISR(USART1_RX_vect)
{
    program._debugConsole.Receive.OnIsCompleteInterrupt();
}

ISR(USART1_UDRE_vect)
{
    program._debugConsole.Transmit.OnAcceptDataInterrupt();
}

// data exchange is triggered by an external interrupt on pin B2 (INT2)
ISR(INT2_vect)
{
    program._dataPort.OnDataInterrupt();
}

#ifdef DEBUG

void AtlDebugWrite(uint8_t componentId, DebugLevel level, const char *message)
{
    // switch (level)
    // {
    // case DebugLevel::Critical:
    //     serial.Transmit.Write("!!:");
    //     break;
    // case DebugLevel::Error:
    //     serial.Transmit.Write("!:");
    //     break;
    // case DebugLevel::Warning:
    //     serial.Transmit.Write("?:");
    //     break;
    // case DebugLevel::Info:
    //     serial.Transmit.Write("i:");
    //     break;
    // case DebugLevel::Trace:
    //     serial.Transmit.Write("t:");
    //     break;
    // case DebugLevel::Debug:
    //     serial.Transmit.Write("d:");
    //     break;
    // default:
    //     break;
    // }

    // TODO: {ticks}
    // TODO: [componentId] (lookup?)

    program._debugConsole.Transmit.WriteLine(message);
}

// void AtlDebugWrite(uint8_t componentId, DebugLevel level, const char *message)
// {
//     serial.Transmit.Write(Scheduler::getTicks());
//     serial.Transmit.Write(" [");
//     serial.Transmit.Write(componentId);
//     serial.Transmit.Write("] ");

//     switch (level)
//     {
//     case DebugLevel::Critical:
//         serial.Transmit.Write("CRITICAL: ");
//         break;
//     case DebugLevel::Error:
//         serial.Transmit.Write("ERROR: ");
//         break;
//     case DebugLevel::Warning:
//         serial.Transmit.Write("WARNING: ");
//         break;
//     case DebugLevel::Info:
//         serial.Transmit.Write("INFO: ");
//         break;
//     case DebugLevel::Trace:
//         serial.Transmit.Write("TRACE: ");
//         break;
//     case DebugLevel::Debug:
//         serial.Transmit.Write("DEBUG: ");
//         break;
//     default:
//         break;
//     }
//     serial.Transmit.WriteLine(message);
// }

bool AtlDebugFilter(uint8_t componentId, DebugLevel level)
{
    // if (level > DebugLevel::Warning)
    //     return false;

    // if (componentId == 1)
    //     return false;

    return true;
}

#endif // DEBUG

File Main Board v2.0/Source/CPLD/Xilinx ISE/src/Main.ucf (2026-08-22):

# User Constraints File (UCF)
# Device: XC95288XL-TQ144
# Board:  Zalt2 Main Board v2.0 (U7)
# Generated from: Main Board v2.0 schematic / IPC netlist (2026-05-13)
#
# Naming conventions:
#   Active-low signals use the _N suffix.
#   Hierarchical net names from the schematic (e.g. /CPU/A0, Control Logic/MA22)
#   are flattened to their signal portion only.
#
# Note: JTAG dedicated pins (TDI=P63, TMS=P65, TCK=P67, TDO=P122) are fixed
#       in silicon and require no LOC constraints.
#
# Power/GND pins (no constraints needed):
#   VCC (+3V3): P1  P8  P37 P42 P55 P73 P84 P109 P127 P141
#   GND:        P18 P29 P36 P47 P62 P72 P89  P90  P99 P108 P114 P123 P144

# ----------------------------------------------------------------------------
# Clocks
# ----------------------------------------------------------------------------

NET "CLK20" LOC = "P30" | BUFG = "CLK" ;
NET "BCLK" LOC = "P126" | SLEW = "FAST" | DRIVE = "8" ;

NET "CLK20" TNM_NET = "CLK20" | CLOCK_DEDICATED_ROUTE = TRUE;
TIMESPEC "TS_CLK20" = PERIOD "CLK20" 50 ns HIGH 50 % ;

#NET "BCLK"    TNM_NET = "BCLK" ;
#TIMESPEC "TS_BCLK" = PERIOD "BCLK" 100 ns HIGH 50 % ;

# ----------------------------------------------------------------------------
# CPU Bus - Address (inputs from Z80)
# ----------------------------------------------------------------------------

NET "A<0>" LOC = "P28" ;
NET "A<1>" LOC = "P31" ;
NET "A<2>" LOC = "P32" ;
NET "A<3>" LOC = "P33" ;
NET "A<4>" LOC = "P34" ;
NET "A<5>" LOC = "P35" ;
NET "A<6>" LOC = "P39" ;
NET "A<7>" LOC = "P40" ;
NET "A<8>" LOC = "P41" ;
NET "A<9>" LOC = "P43" ;
NET "A<10>" LOC = "P44" ;
NET "A<11>" LOC = "P45" ;
NET "A<12>" LOC = "P140" ;
NET "A<13>" LOC = "P139" ;
NET "A<14>" LOC = "P138" ;
NET "A<15>" LOC = "P137" ;

# ----------------------------------------------------------------------------
# CPU Bus - Data (bidirectional with Z80)
# ----------------------------------------------------------------------------

NET "D<0>" LOC = "P58"  ;
NET "D<1>" LOC = "P59"  ;
NET "D<2>" LOC = "P60"  ;
NET "D<3>" LOC = "P61"  ;
NET "D<4>" LOC = "P64"  ;
NET "D<5>" LOC = "P66"  ;
NET "D<6>" LOC = "P68"  ;
NET "D<7>" LOC = "P69"  ;

# ----------------------------------------------------------------------------
# CPU Control Signals (active-low signals use _N suffix)
# ----------------------------------------------------------------------------

NET "CPU_MREQ_N" LOC = "P9" ;
NET "CPU_IORQ_N" LOC = "P142" ;
NET "CPU_RD_N" LOC = "P19" ;
NET "CPU_WR_N" LOC = "P17" ;
NET "CPU_M1_N" LOC = "P71" ;
NET "CPU_RFSH_N" LOC = "P124" ;
NET "CPU_HALT_N" LOC = "P129" ;
NET "CPU_WAIT_N" LOC = "P70" ;
NET "CPU_INT_N" LOC = "P120" ;
NET "CPU_NMI_N" LOC = "P119" ;
NET "CPU_RST_N" LOC = "P143" | BUFG = "SR" ;
NET "CPU_BUSRQ_N" LOC = "P125" ;
NET "CPU_BUSACK_N" LOC = "P128" ;

# ----------------------------------------------------------------------------
# Memory Chip Selects (outputs from CPLD)
# ----------------------------------------------------------------------------

NET "ROM_CE_N" LOC = "P121" ;
NET "RAM_CE_N" LOC = "P118" ;

# ----------------------------------------------------------------------------
# MMU - Physical Memory Address Extension (inputs from MMU address lines)
# ----------------------------------------------------------------------------

NET "MA<12>" LOC = "P46" ;
NET "MA<13>" LOC = "P48" ;
NET "MA<14>" LOC = "P49" ;
NET "MA<15>" LOC = "P50" ;
NET "MA<16>" LOC = "P51" ;
NET "MA<17>" LOC = "P52" ;
NET "MA<18>" LOC = "P53" ;
NET "MA<19>" LOC = "P54" ;
NET "MA<20>" LOC = "P56" ;
NET "MA<21>" LOC = "P57" ;
NET "MA<22>" LOC = "P20" ;
NET "MA<23>" LOC = "P21" ;
NET "MA<24>" LOC = "P22" ;

# ----------------------------------------------------------------------------
# MMU - Mapping RAM Control
# ----------------------------------------------------------------------------

NET "MMU_MAP<0>" LOC = "P111" ;
NET "MMU_MAP<1>" LOC = "P112" ;
NET "MMU_MAP<2>" LOC = "P113" ;
NET "MMU_MAP<3>" LOC = "P115" ;
NET "MMU_MAP<4>" LOC = "P107" ;
NET "MMU_MAP<5>" LOC = "P106" ;
NET "MMU_MAP<6>" LOC = "P103" ;
NET "MMU_MAP<7>" LOC = "P104" ;
NET "MMU_MAP<8>" LOC = "P116" ;
NET "MMU_MAP<9>" LOC = "P110" ;
NET "MMU_MAP<10>" LOC = "P117" ;

NET "MMU_RAM1_CE_N" LOC = "P105" ;
NET "MMU_RAM2_CE_N" LOC = "P98" ;
NET "MMU_RAM1_WE_N" LOC = "P101" ;
NET "MMU_RAM2_WE_N" LOC = "P102" ;
NET "MMU_RAM1_DE_N" LOC = "P93" ;
NET "MMU_RAM2_DE_N" LOC = "P94" ;
NET "MMU_RAM_DDIR" LOC = "P95" ;

# ----------------------------------------------------------------------------
# MMU - Memory Protection Unit signals
# ----------------------------------------------------------------------------

NET "MMU_MP_EXE" LOC = "P97"  ;
NET "MMU_MP_RD" LOC = "P96"  ;
NET "MMU_MP_WR" LOC = "P100"  ;

# ----------------------------------------------------------------------------
# Expansion Bus - IRQ / INTACK daisy-chain
# ----------------------------------------------------------------------------

NET "BIRQ<0>" LOC = "P136"  ;
NET "BIRQ<1>" LOC = "P135"  ;
NET "BIRQ<2>" LOC = "P134"  ;
NET "BIRQ<3>" LOC = "P133"  ;
NET "BIRQ<4>" LOC = "P132"  ;
NET "BIRQ<5>" LOC = "P6"   ;
NET "BIRQ<6>" LOC = "P4"   ;
NET "BIRQ<7>" LOC = "P2"   ;

NET "BINTACK<0>" LOC = "P92" ;
NET "BINTACK<1>" LOC = "P130" ;
NET "BINTACK<2>" LOC = "P131" ;
NET "BINTACK<3>" LOC = "P75" ;
NET "BINTACK<4>" LOC = "P74" ;
NET "BINTACK<5>" LOC = "P7"  ;
NET "BINTACK<6>" LOC = "P5"  ;
NET "BINTACK<7>" LOC = "P3"  ;

NET "BINTEN" LOC = "P85" ;
NET "BIACK_N" LOC = "P91" ;
NET "BBUSRQ_N" LOC = "P16" ;

# ----------------------------------------------------------------------------
# Expansion Bus - Memory / IO Strobes (outputs to expansion bus)
# ----------------------------------------------------------------------------

NET "B8_MEM_WR_N" LOC = "P76" ;
NET "B8_MEM_RD_N" LOC = "P77" ;
NET "BIO_WR_N" LOC = "P78" ;
NET "BIO_RD_N" LOC = "P88" ;

# ----------------------------------------------------------------------------
# Expansion Bus - Bus Control Lines
# ----------------------------------------------------------------------------

NET "BC1" LOC = "P27"  ;
NET "BC2" LOC = "P26"  ;
NET "BC3" LOC = "P25"  ;
NET "BC4" LOC = "P24"  ;
NET "BC5" LOC = "P23"  ;
NET "BC13" LOC = "P15"  ;
NET "BC14" LOC = "P14"  ;
NET "BC15" LOC = "P13"  ;
NET "BC16" LOC = "P12"  ;
NET "BC17" LOC = "P11"  ;
NET "BC18" LOC = "P10"  ;

# IO/GCK3 to GND (big mistake!)
NET "GNDPIN" LOC = "P38" ;

# ----------------------------------------------------------------------------
# System Interface (MCU <-> CPLD)
# ----------------------------------------------------------------------------

NET "SYSINT<0>" LOC = "P83"  ;
NET "SYSINT<1>" LOC = "P81"  ;
NET "SYSINT<2>" LOC = "P79"  ;
NET "SYSINTACK" LOC = "P80" ;
NET "SYSCMD" LOC = "P82" ;
NET "SYSDDIR" LOC = "P86" ;
NET "SYSDEN_N" LOC = "P87" ;

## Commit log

2026-04-06 schematic done*
    [CPU.kicad_sch, Control Logic.kicad_sch, ExpansionBus.kicad_sch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]
2026-04-08 board update
    [CPU.kicad_sch, Control Logic.kicad_sch, ExpansionBus.kicad_sch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]
2026-04-11 schematic update
    [CPU.kicad_sch, Control Logic.kicad_sch, ExpansionBus.kicad_sch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]
2026-04-13 schematic updates
    [CPU.kicad_sch, Control Logic.kicad_sch, ExpansionBus.kicad_sch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]
2026-05-02 board progress
    [Main Board v2.0.kicad_pcb]
2026-05-11 board rev a routed
    [CPU.kicad_sch, Control Logic.kicad_sch, ExpansionBus.kicad_sch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]
2026-05-13 final board
    [Main Board v2.0.kicad_pcb, Main Board v2.0.kicad_pcb_bom.csv, Main Board v2.0.kicad_pcb_positions.csv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]
2026-05-16 chat smart device for storage
2026-05-16 update schematic
2026-05-24 tdo/tdi swap text
    [Control Logic.kicad_sch]
2026-05-24 os task switch
2026-05-25 rst with switch to os-task
2026-05-31 update jtag schematic comments
    [Control Logic.kicad_sch]
2026-08-23 task switch on rst
